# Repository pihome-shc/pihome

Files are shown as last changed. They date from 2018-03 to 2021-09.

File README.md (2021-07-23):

<p align="center">
    <a href="https://www.pihome.eu" target="_blank" align="center">
        
    </a>
<br/>
</p>

# PiHome - Smart Heating Control

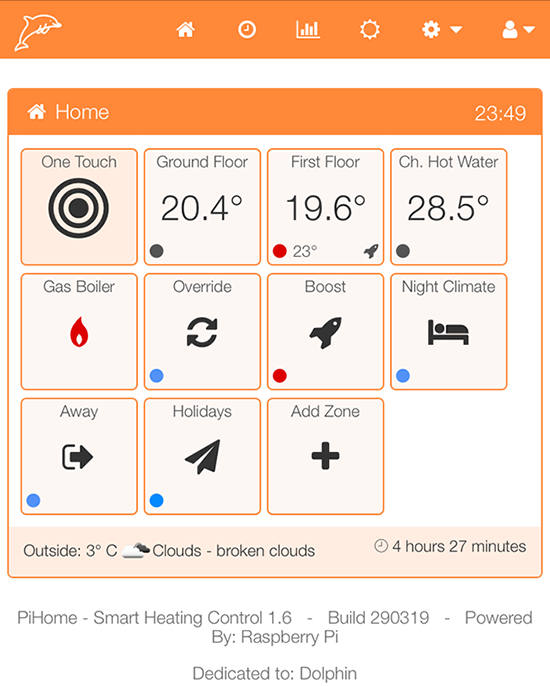
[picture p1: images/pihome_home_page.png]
PiHome - Smart Heating Control - Home Screen


PiHome – Smart Heating Control is home automation system or you can say central heating control systems that runs on credit card size single board computer Raspberry Pi. You can control your home heating from your smartphone, laptop or tablet, PiHome is a wireless boiler control which mean you don’t need to run cables from pihome controller to your boiler or to your heating zone valve or to any temperature sensors in any heating zone.PiHome is active heating control of your multi zoned heating, hot water including electrical immersion with unlimited schedules, boost and night climate suites your needs.

[Step by Step Instructions](http://www.pihome.eu/how-to-install/ "PiHome - Step by Step Instructions")

<p style="color:red;">Before we deep dive into this project something very important: PiHome comes with ABSOLUTELY NO WARRANTY, to the extent permitted by applicable law. DO NOT MAKE ANY CHANGES TO YOUR HEATING SYSTEM UNTIL UNLESS YOU KNOW WHAT YOU ARE DOING, contents provided here are for information and education purpose only, I take no responsibility for any loss or damage to you or your property.”</p3>

###If you want to download SD card image for Raspberry Pi please visit http://www.pihome.eu 

## Smart Heating Control – Features:
* Support Serial Gateway
* Support Ethernet and WiFi Gateway
* Unlimited schedule 
* Boiler and heating zone usage graphs
* Boost control for each Zone
* Override for each Zone
* Night climate
* Away

## Planned features
A real documentation (currently there's none, but the code is self explanatory and commented as well )

Follow Instructions on [PiHome](http://www.pihome.eu "PiHome - Smart Heating Control") if you have any question drop me comments and i will do my best to reply as soon as humanely possible. 

## Requirements
Basic knowledge of command line with following main components for pihome to function. 
* Apache Web Server
* PHP 7.x
* MySQL/MariaDB 

## How To Install 
sudo apt-get install git
sudo git clone https://github.com/pihome-shc/pihome "/var/www"
For more detailed instructiosn vist [PiHome](http://www.pihome.eu "PiHome - Smart Heating Control") website 

## Secial Thanks to

* [SB Admin 2 Template](http://startbootstrap.com/template-overviews/sb-admin-2 "SB Admin 2 Template ")
* [Pretty Checkbox](http://www.cssscript.com/pretty-checkbox-radio-inputs-bootstrap-awesome-bootstrap-checkbox-css "Pretty Checkbox ")
* [Font-Awesome](https://fortawesome.github.io/Font-Awesome "Font-Awesome")
* [Ionicons](http://ionicons.com "Ionicons ")
* [Box Shadow CSS](http://www.cssmatic.com/box-shadow "Box Shadow CSS")
* [AnimateCSS](https://daneden.github.io/animate.css "Animate.css ")
* [MySensors](https://www.mysensors.org "MySensors")
* [RaspberryPi Home Automation](http://pihome.harkemedia.de "RaspberryPi Home Automation")
* [All Others if forget them...](http://www.pihome.eu "All Others if forget them...")

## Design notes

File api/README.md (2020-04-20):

# APIs

## Boost State API
This API is used to set or check the BOOST on or off state for a given zone by name.
To check the current boost state call using http://pihome ip address/api/boostSet?zonename=abc where abc is the name of the zone.
To set the boost state call using http://pihome ip address/api/boostSet?zonename=abc&state=x where abc is the name of the zone and x is either true or false (alternatively 1 or 0 can be used).
The returned JSON format is:
```
    {
        "success": true,
        "state": zoneState
    }
```

## Get Zone Temperature API
This API is used to return the temperture for a given zone by name.
To return the temperature for a zone call using http://pihome ip address/api/getTemperature?zonename=abc where abc is the name of the zone.
The returned JSON format is:
```
    {
        "success": true,
        "state": zoneTemperature
    }
```

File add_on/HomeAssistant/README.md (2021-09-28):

# Home Assistant integration
For monitoring and controlling PiHome from Home Assistant via MQTT. PiHome will automatically broadcast over MQTT all the entity definitions needed to setup and then update the following HA entities:
* PiHome CPU Usage - sensor
* PiHome CPU Load (1m, 5m and 15m) - sensors
* PiHome CPU temperature - sensor
* PiHome Memory Use - sensor
* PiHome Swap Usage - sensor
* PiHome Disk Use - sensor
* PiHome Host Ip - sensor
* PiHome Last Boot - sensor
* PiHome Network throughput (up & down) - sensors
* PiHome Wifi Strength - sensor
* Boiler Status - binary sensor
* Climate entity for each zone defined in PiHome
  * Away Status (this is the same for all zones)
  * Zone Current Temperature (for each zone)
  * Zone Target Temperature (for each zone)
  * Zone Current Mode (for each zone)
  * Zone Current Status (for each zone)
  * Zone Boost (for each zone)
  * Zone Override (for each zone)
  * Zone sensor battery percentage (for each zone using a MySensor sensor)
  * Zone sensor battery voltage (for each zone using a MySensor sensor)

The climate entites allow to trigger the PiHome Boost function (Aux Heat in Home Assistant) for each zone, enable or disable the PiHome Away status and adjust the target temperature for each zone. When the target temperature of a zone is adjusted in Home Assisatant the Override mode is triggered in PiHome using the new target temperature. When installing this add-on a change will be made to the PiHome Override mode logic: **the Override mode will automatically be disabled when a new schedule for the zone starts**.

## Quick Start

1. Ensure your database is updated (i.e. the *mqtt* table includes the *topic* column)
2. Execute bash install.sh this will:
   * Install the Phyton moudles needed
   * Create and enable a service for autostart
   * Start service that was created

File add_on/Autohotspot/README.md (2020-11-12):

# Autohotspot

This code is the work of RaspberryConnect.com, thank you for this guide and code.

The installer has been modified to add support for the Armbian OS and to allow integartion with PiHome

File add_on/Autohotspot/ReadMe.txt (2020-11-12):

RaspberryConnect.com
This installer script, the autohotspot and autohotspotN scripts can be shared and modified but all references to RaspberryConnect.com must be kept in place.

AutoHotspot Setups:
This script is for installing a Raspberry Pi WiFi setup where the Pi will connect to a previously configured Wifi network when the Pi is in range of the router or Automatically setup a Raspberry Pi Hotspot/access point when a known wifi network is not in range.
This can also be run manually or with a timer to switch without a reboot.

This is available in two setups:
1: Internet access available for connected devices when a Ethernet cable is connected for the Raspberry Pi's 3A,3B,3B+ & 4. For Rapberry Pi's A,B, B+,& 2 if an usb Wifi adapter is used.
2: No internet access for connected devices. Designed for the Raspberry Pi Zero W or other Raspberry PI's where only a direct connection to the PI from a phone, tablet or Laptop is required.

There is also setup for permanent hotspot with internet access for connected devices.

For more information and for the manual setup's see:
https://www.raspberryconnect.com/projects/65-raspberrypi-hotspot-accesspoints/157-raspberry-pi-auto-wifi-hotspot-switch-internet
https://www.raspberryconnect.com/projects/65-raspberrypi-hotspot-accesspoints/158-raspberry-pi-auto-wifi-hotspot-switch-direct-connection
https://www.raspberryconnect.com/projects/65-raspberrypi-hotspot-accesspoints/168-raspberry-pi-hotspot-access-point-dhcpcd-method

This script will install any of these three setups or allow you to change between setup types.
In addition the Hotspot SSID and Password can be changed, new WiFi networks can be added to the Raspberry PI while in Hotspot Mode. The Pi can be forced between Network mode and Hotspot mode without a reboot. Also there is an uninstaller.

To use the installer:

Download the AutoHotspot-Setup.tar.xz archive from
curl "https://www.raspberryconnect.com/images/hsinstaller/AutoHotspot-Setup.tar.gz" -o AutoHotspot-Setup.tar.gz

Unarchive the file to the curent folder using the command
tar -xzvf AutoHotspot-Setup.tar.xz
If you are using the Desktop then right click on the AutoHotspot-Setup.tar.xz and select Extract Here

open a terminal screen and navigate to the Autohotspot folder. If this is in your home directory then use 
cd Autohotspot
if this is your desktop then use 
cd ./Desktop/Autohotspot
Run the script with the command
sudo ./autohotspot-setup.sh
This script will fail if sudo is not used.

You will presented with a menu with these options

 1 = Install Autohotspot with Internet for Connected Devices
 2 = Install Autohotspot with No Internet for connected devices
 3 = Install a Permanent Hotspot with Internet for connected devices
 4 = Uninstall Autohotspot or Permanent Hotspot
 5 = Add or Change a WiFi network (SSID)
 6 = Autohotspot: Force to a Hotspot or Force to Network if SSID in Range
 7 = Change the Hotspots SSID and Password
 8 = Exit

Option 1: Install Autohotspot with Internet for Connected Devices 
Once installed and after a reboot the Raspberry Pi will connect to a router that has previously been connected to and is listed in /etc/wpa_supplicant/wpa_supplicant.conf. If no router is in range then it will generate a WiFi hotspot.
This will have an SSID of RPiHotspot and password of 1234567890
Use option 7 to change the password and also the SSID if required
If an ethernet cable is connected to the Pi with access to the internet then it will allow devices connected to the hotspot access to the internet or local network.
Once a connection to the hotspot has been made you can access the Raspberry Pi via ssh & VNC with
ssh pi@192.168.50.5
vnc: 192.168.50.5::5900
for webservers use http://192.168.50.5/

Option 2: Install Autohotspot with No Internet for connected devices
This option is similar to option 1 but connected devices have no internet connection if an ethernet cable is connected. 
This has been designed so you can access only the Pi from a Laptop, tablet or phone.
The hotspot SSID will be RPiHotspot with a password of 1234567890
Once a connection to the hotspot has been made you can access the Raspberry Pi via ssh & VNC with
ssh pi@10.0.0.5
vnc: 10.0.0.5::5900
for webservers use http://10.0.0.5/

Otion 3: Install a Permanent Hotspot with Internet for connected devices
This is for a permanent WiFi hotspot with internet access for connected devices.
The Raspberry Pi will only have network or internet access when an ethernet cable is connected.
Once a connection to the hotspot has been made you can access the Raspberry Pi via ssh & VNC with
ssh pi@192.168.50.10
vnc: 192.168.50.10::5900
for webservers use http://192.168.50.10/

Additional setup is required if you wanted to use a second WiFi device to connect to the internet rather than a ethernet conection. This will be a future option.

Option 4: Uninstall Autohotspot or Permanent Hotspot
This will disable the setup of any of the three setups and return the Raspberry Pi to default Wifi settings.
Hostapd & dnsmasq will not be uninstalled just disabled.

Option 5: Add or Change a WiFi network (SSID)
If you are using either of the autohotspot setups in hotspot modes and wish to connect to a local WiFi network. You will be unable to scan for any networks as the desktop wifi option will be disabled, shown as red crosses. You can manually add the details to /etc/wpa_supplicant/wpa_supplicant.conf if you know them. 
This option will allow you to scan for local WiFi networks and update the Pi. If you then reboot or use the Force... option ,see below. 
This option only works for WiFi networks where only a password is required. If a username is required this will not work. (Future update)

Option 6: Autohotspot: Force to a Hotspot or Force to Network if SSID in Range
This option is only for the Autohotspot setups.
If you are at home and connected to your home network but would like to use the hotspot. This option will force the pi to hotspot mode and will ignore your home network untill the next reboot. If you use this option again while in hotspot mode it will attempt to connect to a known network. This will go back to the hotspot if no valid WiFi network is found or there is a connection issue.
 
Option 7: Change the Hotspots SSID and Password
By default the hotspot ssid is RPiHotSpot with a password of 1234567890. Use this option to change either or both SSID and Password.
You will be prompted to change both but if you make no entry and press enter the existing setting will be kept.
The password must be at least 8 characters. 

Option 8: Exit
Exit the script.

NFtables Warning.
This setup uses iptables for routing the Hotspots to the internet, options 1 & 3. From Raspbian 10 Buster, IPtables are depreciated in place of NFtables. By default NFtables will handle IPtable rules. 
If you know you are using NFtables for a Firewall or other routing rules then don't use the internet routed hotspots and only use option 2, Autohotspot without internet. Otherwise there will be a conflict with your routing tables. 
NFtables will be implemented shortly in the next main update of the installer and scripts.    
Raspbian Stretch (9) & Jessie (8) only use IPtables.
You will be warned when you initially run the installer script if NFtables are active.

/etc/network/interfaces file:
many older hotspot and network setup guides online add entries to the /etc/network/interfaces file. This file is depreciated in Raspbian and any entry in this file is not compatible with these setups. This installer backup and remove any entries found in this file. They will be restored if the uninstall option is used.

RaspberryConnect.com

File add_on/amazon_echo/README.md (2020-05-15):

# echo
For controlling local devices with the Amazon Echo.

Instructions for installation and usage see https://github.com/n8henrie/fauxmo

Credit to Nathan Henrie (https://n8henrie.com)

## Quick Start

1. Execute the installer using - 'sh install_echo.sh'
2. Tell Echo, "discover my devices"
3. Use Echo's "zone name on" and "zone name off" to set the BOOST on or off as required
4. Use the Alexa app to edit zone names as required

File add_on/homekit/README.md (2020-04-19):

# Homekit
For controlling local devices with the iOS Home App. This interface uses Homebridge and the Homebridge Http Webhooks plugin to provide control of BOOST for individual zones and to interogate temperature sensors. 

## Quick Start

1. Install Homebridge, see https://github.com/homebridge/homebridge/wiki/Install-Homebridge-on-Raspbian
2. Execute bash install.sh this will:
    Install the Homebridge Http Webhooks plugin.
    Modify /etc/apache2/sites-available/000-default.conf and enable mod_rewrite so that urls without the .php extension can be used (a backup will be created),
    Check that the Webhooks cache storage directory has been created and is empty.
    Create a backup of /var/lib/homebridge/config.json.
    Add to config.json the Webhooks platform
    Add to config.json Webhooks switches for each zone where status = 1, the [id] value will be switchxx where xx is the zone_id.
    Add to config.json Webhooks sensors for each zone where status = 1 or graph_it = 1, the [id] value will be sensorxx where xx is the zone_id.

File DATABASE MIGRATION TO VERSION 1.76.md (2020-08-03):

# Process to Migrate the Database to Version 1.76

## Changes
The 'zone' table has been split in to two tables, 'zone' and 'zone_sensors'.
The 'zone' table contains zone and contoller identification information.
The 'zone_sensors' table' contains any sensor related information linked to a particular zone. Category 2 type zones will have no entries in the 'zone_sensors' table.
The database views have been ammended to reflect the new table structures.

## Migration Process
Execute the 'migrate_db.php' file found in the directory 'MySQL_Database', this will update the database structure and migrate the existing 'zone' table data, it will also update the views as required.
Update the other files in the normal manner.

## NOTE - DO NOT UPDATE THE DATABASE BY EXECUTING 'update_db.php'.

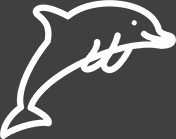
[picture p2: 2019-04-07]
images/dolphin.png

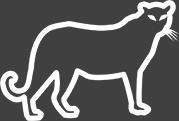
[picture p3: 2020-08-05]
images/amur_leopard.png

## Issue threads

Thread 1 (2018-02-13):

Customisation for different setup

harvybob, 2018-02-13:
Hi,

I'm very intrested in setting up a similar controller to what you have, but php coding is non existent for me, the work i have done is by learning python.

Can you assist/guide me a little on how to make this work for me?
The setup i have at the moment is
1)multiple DS18B20's around the house connected to multiple pi's. Each pi sends back readings to a central mysql database.
2) use bv4627 relay board to switch on and off various zones - i have an ufh manifold of 8 zones, plus first floor and DHW - so at present 10 zones (This will be come 15 in the future)

Everything is wired at present so no need to the wireless side, but want some pointers on where to make adjustments for the different relay controller, and also the data being held on a central mysql (not running on a pi!) I cant see any contact points via the website so forgive me for raising as an issue - feel free to close without comment if you are unable to help me!

pihome-shc, 2018-02-13:
Hi,
first question, what is the heat sources? is it gas boiler, solid fuel or solar? you are using pi with DS18B20 around the house to report back only temperature? does each pi with DS18B20 have relay connected or your relay module is connected to another pi who control zone?

harvybob, 2018-02-13:
Hi, the heat source is gas boiler,
I have two pi's and lots of network cables with sensors on the end.
Pi 1 has approx 8 sensors, and also runs my current code + interface
Pi 2 has approx 3 sensors and runs the control of the relay board over i2c
The relay pi has code which invokes a pulse of a relay (short on and off) based on the zone that is needed ( the relay board handles 12v, to then activate as 230v latching relay - The pi only needs to pulse to turn on, and pulse again to turn off of the 12v system, and is isolated from interference from the pi, as it is controlled using i2c rather then directly over gpio.

pihome-shc, 2018-02-13:
Hi,
main brain in pihome heating is boiler.php i have added support for GPIO Pin connected zone relay and boiler relay. line important to you are
205, 206 for Zone Relay
247, 248 for Boiler Relay ON status
285, 286 for Boiler Relay Off status
you can execute any command you like in these lines to control your zone or boiler relay, tried to google how to send on/off command to bv4627 relay but i didn't find any simple answer.

harvybob, 2018-02-13:
the bv4627 is a bit special in that way - the commands i have are in python -
for on is:
bv4627.write(bytearray([relay_no,1,0,1]))
for off is:
bv4627.write(bytearray([relay_no,0,0,1]))

but you need the i2c library for it to work. Ill have a look at boiler.php and see what i can do,

Any tips on the sensors? do you base boiler.php on the values as they are in a database table?

pihome-shc, 2018-02-13:
Then you can place these commands in boiler.php after you install required library.  and best to do test run.  on temperature sensors side:
Each temperature sensors is represented with node_id in nodes table, when you create zone you just select correct node_id (temperature sensor), this way you have zone and temperature sensors for each zone. i hope this make some sense. best to have look at table structure and table view structure.
Thank you

pihome-shc, 2018-02-22:
@harvybob
did you manage to test the code? need any further help?
W

harvybob, 2018-02-24:
I'm having issues installing and setting up, i've put a question on the LAMP setup page
[http://www.pihome.eu/2017/10/11/apache-php-mysql-raspberry-pi-lamp/#comment-238](url)

seems setup.php is throwing back an error on the mysql_connect() .
error is:
`PHP Fatal error:  Uncaught Error: Call to undefined function mysql_connect() in /var/www/setup.php:38
Stack trace:
#0 {main}
  thrown in /var/www/setup.php on line 38
`

Full detail son the post above

pihome-shc, 2018-02-24:
@harvybob
php7 isnt supported for PiHome, you need to following <a href="http://www.pihome.eu/2017/11/02/install-apache-php-7-0-mysqlmariadb-raspberry-pi-lamp/">Install Apache, PHP and MySQL on a Raspberry Pi (LAMP)</a> let me know if you need more help
Admin

pihome-shc, 2018-02-26:
@harvybob
i have added lines lines in setup.php to check php version before running it.
Admin

pihome-shc, 2018-04-01:
you can change that to anything as system isnt depended on utf16. let me know if you need more help otherwise i m closing this ticket.
pihome - admin

harvybob, 2018-04-02:
Is there a specific place that it needs to be changed or is it throughout the installation script?

pihome-shc, 2018-04-02:
can you share your python script you are using to control your relay?

harvybob, 2018-04-02:
If your able to see my repo's there's home heating. I2c_raw.py does the actual switching, and the switch_relay.py does it from application - so figures out which relay needs to change etc. Line 111 does the actual switch. I'll try an link it when I get to a computer, octodroid doesn't let me copy/paste a link

harvybob, 2018-04-09:
[https://github.com/harvybob/home_heating/blob/master/i2c_raw.py](url) is the class which activates the relays- there are 8 per board.

to invoke the above, i use:

`def switch_relay(sensor):
    """Will look up relay number for a sensor and switch it"""
    relay_results=select_sql("SELECT relay,board FROM sensor_master WHERE sensors = '{0}'".format(sensor))
    for relay in relay_results:
        relay_no=int(relay[0])
        relay_board=int(relay[1])
        bv4627 = i2c_raw.i2c(relay_board, 1)
        logging.info("switching on relay "+str(relay_no)+" on board "+str(relay_board))
        bv4627.write(bytearray([relay_no,1,0,1]))
        time.sleep(.4)
        logging.info("switching off relay "+str(relay_no)+" on board "+str(relay_board))
        bv4627.write(bytearray([relay_no,0,0,1]))`

pihome-shc, 2018-10-05:
Closing this issue, no further comments required,

Closed 2018-10-05.

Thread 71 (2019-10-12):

Buffer Tank -  Second Heat Source

dvdcut, 2019-10-12:
# Buffer Tank -  Second Heat Source
Some background and explanation about buffer tank and combined storage tank.

## Buffer Tank:
A buffer tank is a backup/reserve tank for storing heating in form of hot water which can be called upon when needed. Buffer Tanks are designed for use with standard central heating systems (biomass or solid fuel systems in conjunction with solar water heating system. The water is heated by the heat source (solar, biomass or wood boiler) to a set temperature in the tank and this hot water can be stored until it is required. It therefore will reduce the ‘short cycling’ of a boiler, in that it will reduce the amount of times that a boiler will turn on and off to heat the water and in doing this it will help to increase the lifetime of the boiler.

## Combined storage tanks
A combined storage tank combines hot water storage for heating support. As a result, warm water, typically from solar thermal energy is stored temporarily for both purposes for later consumption.  (its rare installation but still if some one else can shed some light and give schematic for connection and how to control it)

## Option for second heat source:
As i understand right now PiHome do not support second heat source and now way of controlling it or deciding where the heat comes from (heat sources is defined as boiler) and heat comes from same single source.

## Suggestion:
### Option One
Build some differential controller with two sensors and two relay and let that differential controller  to decide where the heat comes from, PiHome only send instructions when there is demand for heat. This would be ideal if buffer tank and boiler are in same location.

### Option Two
In some cases buffer tank and boiler aren't in same location hence one differential controller isn't going to work. configure/modify PiHome to have buffer tank as second heat source or should I say proffered heat source and if that heat source is above set point then heat should be called from buffer tank and if buffer tank is below set point then call for heat from second heat source i.e gas boiler. i know second option requires two controller: one for boiler and second for buffer tank.

This would be huge advantage for PiHome over commercially available solution in the market. all commercially available solutions do not have any way of managing or calling second heat source in managed and decent way as far as i tell (may be i m wrong but i m open to correction).
I would prefer to see PiHome managing/controlling second heat source from itself and second option would definitely gives more controller rather then having only option one implemented, also implementing option one would left out all those who's boiler and buffer tank in separate locations.

sorry for long story but i felt the needs explaining, i m not an expert by any mean and open to correction.

pihome-shc, 2019-10-13:
@dvdcut thank you for explaining and typing :)

pihome-shc, 2019-10-14:
@dvdcut i don't have buffer tank and don't know how heating is circulated from buffer tank. in my place i have to trigger boiler and then zone valve for heating and not to worry about circulation pump but if i had buffer tank then i would have some circulation pump to circulate the heat from buffer tank? so we just need to trigger that pump some what same as we do for gas boiler i would imagine until buffer tank temperature is above set point.

dvdcut, 2019-10-21:
i have been working on this, its not anywhere near finish but its starting point. i have touched boiler.php for second heat source,

### MySQL database table
```
CREATE TABLE `buffer_tank` (
	`id` INT(11) NOT NULL AUTO_INCREMENT,
	`status` TINYINT(4) NULL DEFAULT NULL,
	`name` CHAR(50) NULL DEFAULT NULL,
	`controller_id` INT(11) NULL DEFAULT NULL,
	`controller_child_id` INT(11) NULL DEFAULT NULL,
	`sensor_id` INT(11) NULL DEFAULT NULL,
	`sensor_child_id` INT(11) NULL DEFAULT NULL,
	`min_c` INT(11) NULL DEFAULT NULL,
	PRIMARY KEY (`id`),
	INDEX `FK_buffer_tank_nodes` (`sensor_id`),
	INDEX `FK_buffer_tank_nodes_2` (`controller_id`),
	CONSTRAINT `FK_buffer_tank_nodes` FOREIGN KEY (`sensor_id`) REFERENCES `nodes` (`id`) ON UPDATE SET NULL ON DELETE SET NULL,
	CONSTRAINT `FK_buffer_tank_nodes_2` FOREIGN KEY (`controller_id`) REFERENCES `nodes` (`id`) ON UPDATE SET NULL ON DELETE SET NULL
)
COLLATE='utf8mb4_general_ci'
ENGINE=InnoDB
AUTO_INCREMENT=2;
```
### settinglist.php file, i have this after boiler.
```
<button class="btn btn-default btn-circle btn-xxl mainbtn animated fadeIn" data-href="edit_boiler.php" data-toggle="modal" data-target="#buffer_tank">
<h3 class="buttontop"><small><?php echo $lang['buffer_tank']; ?></small></h3>
<h3 class="degre" ><i class="fa fa-tint fa-1x green"></i></h3>
<h3 class="status"></small></h3>
</button>
```
### model.php file

```
//Buffer Tank settings
echo '
<div class="modal fade" id="buffer_tank" tabindex="-1" role="dialog" aria-labelledby="myModalLabel" aria-hidden="true">
    <div class="modal-dialog">
        <div class="modal-content">
            <div class="modal-header">
			<button type="button" class="close" data-dismiss="modal" aria-hidden="true">x</button>
                <h5 class="modal-title">'.$lang['buffer_tank_settings'].'</h5>
            </div>
            <div class="modal-body">';
$query = "SELECT * FROM buffer_tank;";
$results = $conn->query($query);
$brow = mysqli_fetch_array($results);
echo '<p class="text-muted">'.$lang['buffer_tank_info_text'].'</p>';

echo '
	<form data-toggle="validator" role="form" method="post" action="settings.php" id="form-join">

	<div class="form-group" class="control-label">
	<div class="checkbox checkbox-default checkbox-circle">';
	if ($brow['status'] == '1'){
		echo '<input id="checkbox2" class="styled" type="checkbox" value="1" name="status" checked>';
	}else {
		echo '<input id="checkbox2" class="styled" type="checkbox" value="1" name="status">';
	}
	echo '<label for="checkbox2"> '.$lang['buffer_tank_enable'].'</label></div></div>

	<div class="form-group" class="control-label"><label>'.$lang['buffer_tank_name'].'</label>
	<input class="form-control input-sm" type="text" id="name" name="name" value="'.$brow['name'].'" placeholder="Buffer tank name ">
	</div>

	<div class="form-group" class="control-label"><label>'.$lang['buffer_tank_controller_id'].'</label> <small class="text-muted">'.$lang['buffer_tank_controller_id_info'].'</small>
	<select class="form-control input-sm" type="text" id="buffer_tank_controller_id" name="buffer_tank_controller_id">';

	//get current buffer_tank_controller_id from nodes table
	$query = "SELECT * FROM nodes WHERE id ='".$brow['controller_id']."' Limit 1;";
	$result = $conn->query($query);
	$row = mysqli_fetch_assoc($result);
	$controller_id=$row['node_id'];
	$notice_interval=$row['notice_interval'];

	echo '<option value="'.$controller_id.'" selected>'.($controller_id=='0' ? 'N/A' : $controller_id).'</option>';

	//get list from nodes table to display
	$query = "SELECT * FROM nodes where name = 'Buffer Controller Relay' OR name = 'Buffer Controller' AND node_id!=0;";
	$result = $conn->query($query);
	if ($result){
		while ($nrow=mysqli_fetch_array($result)) {
			echo '<option value="'.$nrow['node_id'].'">'.$nrow['node_id'].'</option>';
		}
	}
	echo '<option value="0">N/A</option>
	</select>
    </div>';

	echo '
	<div class="form-group" class="control-label"><label>'.$lang['buffer_tank_controller_child_id'].'</label> <small class="text-muted">'.$lang['buffer_tank_controller_child_id_info'].'</small>
	<select class="form-control input-sm" type="text" id="buffer_tank_controller_child_id" name="buffer_tank_controller_child_id">
	<option selected>'.$brow['controller_child_id'].'</option>
	<option value="0">0</option>
	<option value="1">1</option>
	<option value="2">2</option>
	<option value="3">3</option>
	<option value="4">4</option>
	<option value="5">5</option>
	<option value="6">6</option>
	<option value="7">7</option>
	<option value="8">8</option>
	</select>
    </div>

	<div class="form-group" class="control-label"><label>'.$lang['sensor_id'].'</label> <small class="text-muted">'.$lang['sensor_id_info'].'</small>
	<select class="form-control input-sm" type="text" id="sensor_id" name="sensor_id">
	<option selected>'.$brow['sensor_id'].'</option>
	<option value="0">0</option>
	<option value="1">1</option>
	<option value="2">2</option>
	<option value="3">3</option>
	<option value="4">4</option>
	<option value="5">5</option>
	<option value="6">6</option>
	<option value="7">7</option>
	<option value="8">8</option>
	</select>
    </div>

	<div class="form-group" class="control-label"><label>'.$lang['min_temperature'].'</label> <small class="text-muted">'.$lang['min_temperature_info'].'</small>
	<select class="form-control input-sm" type="text" id="max_operation_time" name="max_operation_time">
	<option selected>'.$brow['min_c'].'</option>
	<option value="30">30</option>
	<option value="40">40</option>
	<option value="45">45</option>
	<option value="50">50</option>
	<option value="55">55</option>
	<option value="60">60</option>
	<option value="65">65</option>
	<option value="70">70</option>
	<option value="80">80</option>
	<option value="85">85</option>
	<option value="90">90</option>
	<option value="95">95</option>
	<option value="100">100</option>
	<option value="110">110</option>
	<option value="120">120</option>
	</select>
    </div>
	';

	echo '</div>
            <div class="modal-footer">
				<button type="button" class="btn btn-primary btn-sm" data-dismiss="modal">'.$lang['close'].'</button>
				<input type="button" name="submit" value="Save" class="btn btn-default login btn-sm" onclick="buffer_tank_settings()">

            </div>
        </div>
    </div>
</div>';
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
pihome-shc, 2019-10-21:
@dvdcut,
i will give it try tomorrow, your code missing **request.js** and **db.php** code.

pihome-shc, 2019-10-26:
@dvdcut i had implemented your changes, all looks good on gui apart from buffer tank info text, i think its to long. its like explaining what buffer tank is, i think one short line would be enough.

> A buffer tank is a backup/reserve tank for storing heating in form of hot water which can be called upon when needed. Buffer Tanks are designed for use with standard central heating systems (biomass or solid fuel systems in conjunction with solar water heating system) If you have Butter Tank installed and you want to used it as primary heat source you can add this information here.

dvdcut, 2019-12-09:
Buffer tank implementation proving to be more difficult then i thought, i dont know if its all worth in the end or one  differential controller would be better option. anyway i have done some work in last few days on buffer tank i think all gui part is completed but boiler.php is proving to be bit difficult.

[Buffer Tank.zip](https://github.com/pihome-shc/pihome/files/3937471/Buffer.Tank.zip)

pihome-shc, 2019-12-14:
@dvdcut
all GUI looks good, and i can see buffer tank on main screen and all settings working for buffer tank but i think [boiler.php](https://github.com/pihome-shc/pihome/blob/master/cron/boiler.php) need some working and logic isn't there yet in the code, its partially working.

dvdcut, 2019-12-18:
yes, login in boiler.php isnt implemented and its proving to be difficult, i'll work on this issue in new year.

dvdcut, 2020-05-02:
i think i have to drop this, i have found that every buffer tank comes with its controller so i think we don't need this. we can always add butter as zone disable zone to monitor its temperature

pihome-shc, 2020-05-02:
@dvdcut i think you are right and not many user have buffer tank big enough to run heating from it but only supplement hot-water for the house.
closing this

Closed 2020-05-02.

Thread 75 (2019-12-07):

Hot Water Priority Feature Request

harvybob, 2019-12-07:
Hi, Some boilers have an option for hot water priority - where the boiler will increase the heat output to heat up a hot water tank quickly - at a higher temprature then the radiators would normally take.

for this, the boiler has an additional set of controls.

Is there a way for PiHome to be programmed such that if Hot Water demand is on, Close off all zone valves for non hot water if the following two criteria is met: there is a demand for hot water from the tank +the scheduled window for hot water is active?

pihome-shc, 2019-12-07:
@harvybob
is there any interface on boiler that can be checked? or how we know if boiler does this feature? and how to check if there is hotwater demand? this can be implemented.

harvybob, 2019-12-18:
Apologies missed this, how is hot water demand managed at the moment? Alternatively all tanks will have a thermostat so would need to detect using a pin on the pi. The thermostat is usually 0v so shouldn't be a problem?

Most boilers have the feature however usually undocumented, if the boiler has a feature it would be in the installation manual, internally wiring would have contacts for the room stat, and a second pair for dhw.

dvdcut, 2020-03-11:
recently i had new boiler installed and it has this feature but when i asked the installer about this feature he dismissed me by saying i don't have pipe work for this and i can not use it :( but currently hot water goes to my manifold and then based on which zone calling for heat that hot water circulated in that zone (either heating or hot water) i think this is how most of the houses have it setup. may be yours is different and you do have pipe work for hot water

harvybob, 2020-03-13:
Hi dvdcut, There are generally two ways to use HotWater Priority - first and the easiest is using a three port valve - which requires plumbing to be setup as such.

The other way (and the way that alot of plumbers dont know/want to know) is by using the correct actuators on the port valves (assuming you use these!) and/or using relays.

My setup is the second - i have three port valves, one for hot water, one for UFH and the third for rads. The same will apply if you have two port valves. The Hot water actuator has been changed to a 6 wire version - this allows the actuator to send both open and closed signals which is what is needed for my boiler to know if hot water is needed or radiator. If you want to use the existing 5 wire actuactor, you need in include a relay to flip the signal from open to closed and vice versa... Plumbers usually dont want to get involved in the electric side so dont want to do it.

Your setup may be different from this again, but will still be doable in some way! do you use an UFH manifold or are you using port valves?

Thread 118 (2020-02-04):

Serial Read Bottleneck

MindaugasMeskauskas, 2020-02-04:
### Summary:
Yesterday for first time I encountered strange issue, all 3 of my nodes were reporting wrong temperature. Boiler was ON for longer as it should have been. At first I couldn’t tell what was the problem, as all 3 nodes frequently were updating DB with “current” temperature. Next morning I checked graphs (see below) and you can see that right temperature curve appeared about 6 hours late. As it affected all notes the bottleneck must have been on receiving end.

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
Spikes shown on graph around 1am, was me testing nodes at around 10pm.

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
Raspberry Pi temp curve looks as it should (different script, not affected by serial read)

### Observations:
Haven’t done any testing, but this is what I have observed. All of this is my closest guess. Ref similar issue on [stackoverflow](https://stackoverflow.com/questions/19908167/reading-serial-data-in-realtime-in-python)

serialgw.py script has time.sleep(1) in its loop, so it means if serial port receives more than 1 message a second, messages will start to pile up in queue and will be read out one by one every second.
To delay serial read by this much (6h) about 21600 additional messages needed to be written/read in short period of time (not sure how many messages are generated in normal circumstances).

### Possible Solution:
Part 1: In general we are not expecting more than 1 message per second in average, but to prevent such unexpected behaviour and provide future proof, serialgw.py loop should be implemented without sleep as well as without causing extensive additional resources on CPU.

Part 2: Number of additional messages looks to be way too high. Need to be investigate what could have generated all of them in such sort time.

pihome-shc, 2020-02-04:
@MindaugasMeskauskas,
i know this issue, when last time i installed a 32 zone UFH system in Ireland
34 temperature sensors,
10 Zone Controller
1 Boiler Controller
if i do maths correctly:
Temperature sensors sends 3 messages: temperature, battery volt, battery %
Zone Controller: 4 messages per controller with ack to keep controller alive in system.

Node | # | rx | tx | total
-- | -- | -- | -- | --
Sensor | 32 | 0 | 3 | 96
Zone | 10 | 4 | 4 | 160
Boiler | 1 | 1 | 1 | 1
Total |   |   |   | 257

Total 257 messages to process per minute for script it was over the limit and script was causing some serious issues as script couldn't go thought all the messages in 60 seconds while boiler.php updated message_out table ready for next round.

### Workaround:
i decreased message_out per zone controller from 4 to 1 (manually set ack to 0 and leave one ack 1).
and inside wifigw.py  `time.sleep(0.1)`

back to what could have generated that many messages:
when heating is on temperature sensors send reading every 60ish seconds because temperature is changing. You have three zone so i m assuming, one zone controller, one boiler controller and three temperature sensors. your system have to deal with 27 messages every 60 seconds and if script go for sleep for 1 seconds we lose 30 seconds in sleep time per 60 seconds so its very close to cause queue.

Node | # | rx | tx | total
-- | -- | -- | -- | --
Sensor | 3 | 0 | 3 | 9
Zone | 1 | 4 | 4 | 16
Boiler | 1 | 1 | 1 | 2
Total |   |   |   | 27

i m not sure how cpu will react with no sleep time.
here is short video when boiler.php run and update message_out table, you can see cpu usage goes nearly 100% on both core.
https://www.dropbox.com/s/xwmobktyrtehbbc/2020-02-04%2023.02.54.mov?dl=0

MindaugasMeskauskas, 2020-02-05:
@pihome-shc
Did some digging yesterday and found that in average 30-40 messages were processed per minute. Max observed was 47. That is a bit high, but not to overload system, as it happened. Checked all processed messages and it looks like I haven't disabled debugging on GW and it prints all debugging info to serial. Will test that next. Still puzzled what could have caused such delay. Could have gateway debug printed so many messages in some scenario?

FYI, my setup:
2 temperature node - only for testing in different rooms or as redundancy
1 water tank node - 2 sensors but returns average
0 Zone - No zone controller (but guessing messages are still sent out as zones are setup in interface)
1 Boiler - but would be nice to have second source :) e.g. water tank is gas and electric.

pihome-shc, 2020-02-05:
@MindaugasMeskauskas
yes debug messages are processed as well even thought they dont get into database but python script still have to process them and ignore them. did you change sleep time to lower value? or remove it all together.

MindaugasMeskauskas, 2020-02-06:
@pihome-shc
Had no time to check it further. Haven't touched anything. Still running original code and with GW debug enabled. Seems to be running OK at the moment.

MindaugasMeskauskas, 2020-02-09:
Finally looked at this again. Observed that GW sometimes get into situation where it produces 200+ debug messages without any payload. Example below:

`0;255;3;0;9;1388779 TSF:MSG:READ,67-67-67,s=67,c=3,t=67,pt=2,l=8,sg=0:67
0;255;3;0;9;1388800 !TSF:MSG:LEN=8,EXP=15`

Have no node 67 so not sure if this some interference or what, but know that I don't need that information of incomplete incoming messages flooding serial buffer. If simply disabling debugging, GW stops writing to serial, but strangely still reads serial port :/ All Serial GW examples I found have debugging enabled which is OK for setting up, but not for production and no explanation how do it without enabling debugging. Played with parameters from MySensors library MyConfig.h and found that if disabling debug by removing line `#define MY_DEBUG` and adding `#define MY_SERIALDEVICE Serial` only messages are written to serial. Current message rate per minute for my setup is 5-17 and that is way better than before with 30-40 or even above 200 in rare circumstances.

Haven't done any code changes is serialgw.py, which is not required with current message rate.

pihome-shc, 2020-02-09:
@MindaugasMeskauskas may be someone in your nearby have mysensors nodes :)

pihome-shc, 2020-02-15:
@MindaugasMeskauskas are you using irq pin on your nRF (i m assuming you are using nRF radio) i know with irp pin it improves buffering and message processing.

pihome-shc, 2020-02-20:
is this issue need any further work?

Closed 2020-02-20.

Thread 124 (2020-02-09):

Zone - Add/Edit

pihome-shc, 2020-02-09:
When adding zone, it set to zone temperature sensors id to 0 and zone controller only show boiler controller from drop down list.

#69 - Missing save button on Zone edit

MindaugasMeskauskas, 2020-02-09:
I probably could check this tomorrow if no one else already doing so.

pihome-shc, 2020-02-09:
Zone Add/Edit is fixed from my last update but if you have free time may be test these changes. second part of this bug is when you edit the zone it add another entry in message_out table.

pihome-shc, 2020-02-20:
closing this issue

Closed 2020-02-20.

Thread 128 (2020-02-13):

Inversed logic

sandreialexandru, 2020-02-13:
Most boilers require a closed circuit to turn on heating. This means that a boiler connected to a Normal Open relay would be OFF in normal state. When triggering the relay the circuit gets closed and the boiler turns ON.
Having security in mind and assuming that the SD card or the Raspberry Pi could get faulty then the relay would close the NC contacts and the boiler would turn ON indefinitely. I suggest an inverse logic in _/cron/boiler.php_
**_$relay_on = '1'; //GPIO value to write to turn on attached relay
$relay_off = '0'; // GPIO value to write to turn off attached relay_**

dvdcut, 2020-02-13:
i think this is down to relay board you are using, You need to have relay with optocoupler as descried in [pihome website ](http://www.pihome.eu/2017/10/12/wireless-arduino-boiler-controller-relay-with-nrf24l01/)
this way if pi dies or sd card or any other thing then this relay gets turned off.

sandreialexandru, 2020-02-13:
Turning the relay off while the boiler is connected to NC contacts just puts the boiler to ON

MindaugasMeskauskas, 2020-02-13:
@sandreialexandru
Common standard relays have 3 contacts.
COM = common contact
NC = normally closed contact
NO = normally open contact

In our case if you disconnect signal wires from relay it should switch off (COM + NC = off when no signal)
Switch wires between NC and NO or change relay you have.

sandreialexandru, 2020-02-13:
@MindaugasMeskauskas
I'm very aware of how relays (electromagnetic or with transistor optocoupler) work. But inversing the logic would make PiHOME possible to be used with any kind of relays.

dvdcut, 2020-02-13:
two variables at the top of boiler.php to modify values as your needs. sorry not trying to be hard but if your boiler work different then you have to swap variable values so PiHome is always in control.

```
$relay_on = '1'; //GPIO value to write to turn on attached relay
$relay_off = '0'; // GPIO value to write to turn off attached relay
```

MindaugasMeskauskas, 2020-02-13:
I got now what was asked, but think reversing logic is done when compiling Arduino Sketch - PiHome_Boiler_Controller_v031.ino
`#define RELAY_ON 1  // GPIO value to write to turn on attached relay`
`#define RELAY_OFF 0 // GPIO value to write to turn off attached relay`

dvdcut, 2020-02-13:
i think @sandreialexandru was asking for raspberry pi gpio pin,

sandreialexandru, 2020-02-13:
After searching for a while to be sure that almost everywhere, all boilers and thermostats work on the same principle I've found some discussions stating that boilers get connected to COM+NO pins of relay. If we do this with PiHOME everything works backwards.
[https://www.tyrrellsmarthome.com/wp-content/uploads/2018/02/Thermostat-Energy-Combo-Bundle.pdf](url)
[https://diy.stackexchange.com/questions/115954/isolation-relay-for-ecobee-smart-thermostat-nc-or-no](url)

pihome-shc, 2020-02-13:
I think its worth testing this on raspberry pi just to be sure, i can do this later and update here the results.

sandreialexandru, 2020-02-15:
I have tested this by redefining the two variables in boiler.php
$relay_on = '1'; //GPIO value to write to turn on attached relay
$relay_off = '0'; // GPIO value to write to turn off attached relay

pihome-shc, 2020-02-15:
@sandreialexandru so if pihome set relay to 1 ($relay_on = '1';) it mean really would be on and if pi fails relay will turn off as there is no signal?
you dont need to unplug power to pi cable but you can unplug signal cable from pi to relay board.

aszumski, 2020-02-16:
@sandreialexandru I think most of optoisolated 5v relay boards that people use activate relay when you pull it down input to 0V. Just adjust relay on/off variables as you wish. For example I have zone valves wired to pi via relay board but I use uln2803 between relay board and pi (don't like idea of driving 5v input with 3.3v) that changes the on/off logic, so I just adjusted the script for my needs.

harvybob, 2020-02-16:
Would the values for this be better in a config file?(like you guys have done for the database connection details) that way it's kept for the individual, and not over written on upgrade? For me using i2c I need 1 for on, but for others it will be 0 for on depending on the relay used...

pihome-shc, 2020-02-20:
may be best to give option to user during creation of nodes i.e define on state of relay with dropdown 1 or 0 save it to database as it would be easy maintain and update.

pihome-shc, 2020-05-01:
closing this issue.

Closed 2020-05-01.

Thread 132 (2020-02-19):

Reorganising Settings Menu

MindaugasMeskauskas, 2020-02-19:
As @pihome-shc have mentioned in another post list of icons in settings menu keeps growing.
Open this issue to discussion how we could tackle this.

Example suggestions:
- Systems °, OS Version, PIHome Update, Uptime, Wifi, Ethernet, etc. could be added to one "system" menu under one icon as all just displays info. Maybe reboot and shutdown buttons added to it as well as they are relevant to the system.

- Once of confit of temperature units, language, time zone, etc., should be grouped under "First Startup".

- Or icons could be grouped like "One Touch" button on home screen

> i was looking at the ever growing list of icons under settings. i was thinking to put these settings under language or system or perhaps another icon for time-zone?

_Originally posted by @pihome-shc in https://github.com/pihome-shc/pihome/issues/121#issuecomment-583626295_

pihome-shc, 2020-02-19:
@MindaugasMeskauskas
Setting icons can be organised same as Temperature Graphs,  Daily usage, Boiler Usage (data-toggle), i m open to suggestions, i thin merging these icons requires decent amount of work and it will be easy for future addition for example i m thinking to make raspberry pi as access point if no wifi/ethernet available and give user option to configure Wi-Fi from settings.

### PiHome
PiHome Update
MQTT
PiConnect
Boost
Backup

### Systems
OS Version
Uptime
Wi-fi
Ethernet
User Account
Cron Jobs
Services

### Setup
Override
Frost
Units
Language
Graph
Boiler
Node
Sensors
Zone
Gateway
OpenWeather

pihome-shc, 2020-02-25:
may be its time to implement permission. i.e normal user dont need to see or change anything and some maintenance user account with higher power.

twa127, 2020-03-04:
I like that idea, user able to do scheduling, boost, override, holidays etc but not add zones, change units, language etc or even user not able to access the settings menu at all

dvdcut, 2020-03-04:
i m in favor of hiding some icons and only allow users with some sort of higher permission. bit like any other home alarm, where engineer have different code to access all options and home users some other options.

twa127, 2020-03-09:
Anyone want to try this and see what you think

[settingslist.zip](https://github.com/pihome-shc/pihome/files/4306624/settingslist.zip)

dvdcut, 2020-03-09:
that looks good, here is my version but can not get it to work properly so i think yours would better.

[settingslist.zip](https://github.com/pihome-shc/pihome/files/4306969/settingslist.zip)

twa127, 2020-03-09:
Hi,

Looks like we were thinking on the same lines.

I did not know whether to allow the selected sub-menu to stay open or close it when another menu is chosen as you have done.

dvdcut, 2020-03-09:
i think it will be confusing for ordinary people at first glance, may be best to hide first set of icons when displaying second, third or fourth, my version still have problems as you can see its hiding but not moving icons up next to displayed icons.

twa127, 2020-03-09:
dvdcut - attached your version mixed with mine
[settingslist.zip](https://github.com/pihome-shc/pihome/files/4308585/settingslist.zip)

pihome-shc, 2020-03-09:
@twa127 / @dvdcut
As always great work. few suggestions: change those icons as @twa127 had them in his version, add two <br>after icons list, add default load icon where you had shutdown, reboot and thank you icon. also worth adding one line description for each category

twa127, 2020-03-09:
update my version
[settingslist.zip](https://github.com/pihome-shc/pihome/files/4308798/settingslist.zip)

twa127, 2020-03-09:
what will default load do?

pihome-shc, 2020-03-09:
@twa127
i think your version mixed with @dvdcut  version looks lot better and with that i can not see shutdown, reboot and thank you icon.

twa127, 2020-03-09:
Update with a bit of help text when hovering over icons.
[settingslist.zip](https://github.com/pihome-shc/pihome/files/4308911/settingslist.zip)

pihome-shc, 2020-03-10:
@twa127 / @dvdcut
i have combined your ideas into this, see what you both think and if happy can you do pull request.
[settingslist.zip](https://github.com/pihome-shc/pihome/files/4315144/settingslist.zip)

twa127, 2020-03-11:
Looks good to me

Sent from my iPhone

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

twa127, 2020-03-11:
Just a thought - why not enter settings with all sub menus closed. Also I don’t think shutdown and reboot sit logically in the status menu, which is why I left them on the main settings screen.

Sent from my iPhone

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

pihome-shc, 2020-03-11:
Yes, that is good idea, lets do that then.

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

dvdcut, 2020-03-11:
i love the way it worked out, @twa127 is right shutdown and reboot do not sit in status, i made some improvements to @pihome-shc combined version. i m happy with this

[settingslist.zip](https://github.com/pihome-shc/pihome/files/4317645/settingslist.zip)

twa127, 2020-03-11:
I've tidied up a bit, left thanks in the status menu and added the following lines to en.php:

$lang['tooltip_1'] = "System Status Displays";
$lang['tooltip_2'] = "System Configuration Menus";
$lang['tooltip_3'] = "Boiler Configuration Menus";
$lang['tooltip_4'] = "Node and Zone Configuation";
$lang['system_status'] = "System Status";
$lang['system_configuration'] = "System Configuration";
$lang['boiler_configuration'] = "Boiler Configuation";
$lang['node_zone_configuration'] = "Node and Zone Configuation";

[settingslist.zip](https://github.com/pihome-shc/pihome/files/4319093/settingslist.zip)

pihome-shc, 2020-03-11:
great work, can you do pull request for this now, i think its ready to be implemented.

MindaugasMeskauskas, 2020-03-13:
Works nicely, well done.
But have one observation, tab icons are too small for small touchscreen devices. Tried to fix, but I'm not good with CSS.

twa127, 2020-03-14:
Latest version has slightly larger icons, is that better

Sent from my iPhone

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

twa127, 2020-03-30:
Hi,

I was thinking that 'Services' might be better in the System Configuration menu as now both the MQTT and Amazon Echo services can be configured here

Closed 2020-04-19.

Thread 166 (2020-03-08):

Remove Default Values from Database

pihome-shc, 2020-03-08:
Remove all default values from database and add those values in code so system do not rely on default values where information isnt added via code. fixing this issue will help **#57 Process to update PiHome and Database** and streamline the code for updates and it will remove MySQL/MariaDB version dependency.

twa127, 2020-03-09:
Sounds okay to me, you would need to populate the user table via code otherwise you could not get in to the application at all

dvdcut, 2020-03-09:
in my experience with update_db.php is strange i thought its something to do with my setup even though i m using img file from pihome website. but it keep asking me to update default values.

twa127, 2020-03-09:
I'd also not display the the Boiler icon on the home screen until there was an entry in the boiler table

twa127, 2020-03-09:
dvdcut - had a similar problem in the past was due to using an older version of MySQL/MariaDB, so this change would fix that problem.

twa127, 2020-03-10:
I'll post an update for the boiler model to enable creation of the initial boiler record

twa127, 2020-03-14:
Getting quite close to a solution for this, a couple of points:

1. The user table need to be populated to allow initial access to the WEB interface
2. The system table needs to be populated to identify version and build values

These could be populate using a couple of INSERT queries in setup_db.php
The initial setup of the system could then be performed from the WEB interface -

1. Configure nodes either automatically or manually for GPIO and I2C
2. Configure boiler from boiler model
3. Configure Zones
4. Configure schedules

pihome-shc, 2020-03-14:
@twa127
yes you are right, basic database we have at the moment with some basic entries would be the default ones, i.e user and system related information and i think no need to insert them during setup_db.php.

or you are thinking to making web based installer without any information in database file? but in either case lots of code needs to be changed to remove default values, for example right now nodes related info fully populated from gateway script. and same for holiday schedule left null.

twa127, 2020-03-15:
I think the latest commit will allow us to use a completely empty database file, with version and build numbers in the config.ini file, setupdb.php will be used to populate user and system tables.

Please give the attached a try

[setup_db.zip](https://github.com/pihome-shc/pihome/files/4333997/setup_db.zip)

pihome-shc, 2020-03-15:
@twa127 looks good, i think having blank database will help updating database easy and clean, also future pull request can only update **db_config.ini** with build number and this will limit messing up database file.

twa127, 2020-03-15:
Still need to add create default away and holidays tables to zones.php when the first zone is created, I'll add that to the next commit

twa127, 2020-03-15:
Do you want me to commit this update

pihome-shc, 2020-03-16:
@twa127, did you already commit this update?

twa127, 2020-03-16:
No, I’ll do it in the morning if your happy with it

Sent from my iPhone

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

pihome-shc, 2020-03-16:
Second Part of this updated was to eliminate any default values from database, for instance boiler table have some default values,

CREATE TABLE `boiler` (
	`id` INT(11) NOT NULL AUTO_INCREMENT,
	`sync` TINYINT(4) NOT NULL **DEFAULT '0',**
	`purge` TINYINT(4) NOT NULL **DEFAULT '0'** COMMENT 'Mark For Deletion',
	`status` TINYINT(4) NULL DEFAULT '0',
	`fired_status` TINYINT(4) NULL **DEFAULT '0'**,
	`name` CHAR(50) NULL **DEFAULT 'Gas Boiler'** COLLATE 'utf16_bin',
	`node_id` INT(11) NULL **DEFAULT NULL**,
	`node_child_id` INT(11) NULL **DEFAULT '1'**,
	`hysteresis_time` TINYINT(4) NULL **DEFAULT '3'**,
	`max_operation_time` TINYINT(4) NULL **DEFAULT '60',**
	`datetime` TIMESTAMP NULL **DEFAULT current_timestamp() ON UPDATE current_timestamp(),**
	PRIMARY KEY (`id`) USING BTREE,
	INDEX `FK_boiler_zone` (`node_id`) USING BTREE,
	CONSTRAINT `FK_boiler_zone` FOREIGN KEY (`node_id`) REFERENCES `pihome`.`nodes` (`id`) ON UPDATE RESTRICT ON DELETE RESTRICT
)
COLLATE='utf8_general_ci'
ENGINE=InnoDB
AUTO_INCREMENT=2
;

removing these values will help me to further work on #24 PiConnect Improvements and #57 Process to update PiHome and Database.

twa127, 2020-03-17:
okay I will work on that before I commit the empty database, I think the date related defaults will be the biggest problem as some of the UPDATE queries rely on the default.

twa127, 2020-03-17:
Do you want to remove all the default values from every table

Sent from my iPhone

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

pihome-shc, 2020-03-17:
Yes where possible. I can work with you if you wand to devide work with me.

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

twa127, 2020-03-17:
I’ll plod on for now, away, boiler, holidays  and gateway are done

Sent from my iPhone

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

twa127, 2020-03-17:
Also boost, email and frost_protection are done, working on the message queues

Sent from my iPhone

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

pihome-shc, 2020-03-17:
Thank you.

twa127, 2020-03-19:
I think that I've now changed all the INSERT INTO queries. I've setup my test system successfully from an empty database which has no default clauses.

Please give the attached a try

[setup_db.zip](https://github.com/pihome-shc/pihome/files/4354534/setup_db.zip)

pihome-shc, 2020-03-20:
@twa127 Great work,
couple of things

Boiler:
Enable Boiler checkbox is disabled but after i add boiler records it set that to enable
Schedule:
schedulelist.php have two extra </div> at line 139 and 140
when adding schedule it leaves holidays_id column as null, may be add 0 instead of null value
Boost:  (sb-admin-2.css)
.chat li.left .chat-body padding-top: 10px;
987 canceling out 233
Holidays
holidaylist.php have extra </div > on line 156
enabling and disable schedule does not reload holidayslist.php file but it works on holiday dates.

twa127, 2020-03-20:
Hi

Can you please explain what you mean:

Schedule:
schedulelist.php have two extra at line 139 and 140

Sent from my iPhone

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

pihome-shc, 2020-03-20:
@twa127

Schedule:
schedulelist.php have two extra div  at line 139 and 140

Holidays
holidaylist.php have extra div  on line 156

twa127, 2020-03-20:
I see and agree that they are both wrong, but they have not been changed in this latest batch of updates, so the errors are historical.

I use grep -o '<div' schedulelist.php | wc -l to count the number of opening div and then grep -o '</div' schedulelist.php | wc -l to count the number of closing div, the numbers should obviously match.

I will investigate and fix both files if you want?

pihome-shc, 2020-03-20:
@twa127 that is great way of calculating.
with those extra div panel footer isnt in its correct place.
can you push these changes please.

twa127, 2020-03-20:
okay will do

twa127, 2020-03-20:
Boost: (sb-admin-2.css)
.chat li.left .chat-body padding-top: 10px;
987 canceling out 233

You committed this change on 14 Dec 2019, I'm not sure which one is correct

pihome-shc, 2020-03-20:
@twa127,
i m working on PiConnect script and null values are problematic thats why it has to be 0 if schedule isnt belongs to holiday.

twa127, 2020-03-20:
okay, I'll give the problem some thought :-)

twa127, 2020-03-20:
Okay, now changed

Sent from my iPhone

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

dvdcut, 2020-03-26:
@twa127
my gateway is keep failing with error in log file

```
### 2020-03-26 14:38:50,570 - ERROR ###
Traceback (most recent call last):
  File "/var/www/cron/gateway.py", line 245, in <module>
    timestamp = datetime.datetime.now().strftime('%Y-%m-%d %H:%M:%S')
NameError: name 'datetime' is not defined

### 2020-03-26 14:42:37,333 - ERROR ###
Traceback (most recent call last):
  File "/var/www/cron/gateway.py", line 258, in <module>
    timestamp = datetime.datetime.now().strftime('%Y-%m-%d %H:%M:%S')
NameError: name 'datetime' is not defined

### 2020-03-26 14:43:18,794 - ERROR ###
Traceback (most recent call last):
  File "/var/www/cron/gateway.py", line 258, in <module>
    timestamp = datetime.datetime.now().strftime('%Y-%m-%d %H:%M:%S')
NameError: name 'datetime' is not defined

### 2020-03-26 14:44:31,136 - ERROR ###
Traceback (most recent call last):
  File "/var/www/cron/gateway.py", line 258, in <module>
    timestamp = datetime.datetime.now().strftime('%Y-%m-%d %H:%M:%S')
NameError: name 'datetime' is not defined
```

pihome-shc, 2020-03-29:
@twa127 sorry if i missed anything but i still see database have all the values, i.e its not blank.

twa127, 2020-03-30:
Not committed the empty one yet as I was not sure you were happy with it, just let me know and I’ll do it

Sent from my iPhone

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

pihome-shc, 2020-03-30:
@twa127
let me test this one last time and after this you can do pull request, i'll be using reference to this attachment.
https://github.com/pihome-shc/pihome/issues/166#issuecomment-601154249

twa127, 2020-03-30:
Okay

Sent from my iPhone

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

pihome-shc, 2020-03-30:
@twa127
**Setting->Gateway**
Language missing, some extra fields are showing but when gateway type is select then right fields are displayed. toggle isn't working as it suppose to work. everything works as it should.

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
you can do pull request for database.

twa127, 2020-03-31:
Hi

Is this problem fixed now?

pihome-shc, 2020-03-31:
@twa127 yes, language issue is fixed i think you can do pull request for database. i'll change documentation to include extra steps.

twa127, 2020-03-31:
Okay will do

Sent from my iPhone

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

dvdcut, 2020-05-22:
can i suggest here something:
can we keep some defaults data in database, like boiler and two zone, one heating second hotwater.

pihome-shc, 2020-05-27:
@dvdcut is there any reason you want to have two zone and boiler record in database?

dvdcut, 2020-06-06:
when i was installing my dev system from github i had some issues, may be adding boiler and one zone will make few things out of the box work and make it more plug and play type

pihome-shc, 2020-06-06:
@twa127 did great job on clean-up work on database, i know it is confusing as documentation is missing for fresh install, specially if some one is trying to install from scratch.

adding boiler record wouldn't hurt but it has to added from [setup.php](https://github.com/pihome-shc/pihome/blob/master/setup.php) and [setup_db.php](https://github.com/pihome-shc/pihome/blob/master/MySQL_Database/setup_db.php) files.

Closed 2020-07-02.

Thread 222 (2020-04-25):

Python 3

twa127, 2020-04-25:
Do you think we should consider migrating to the latest version of python?

pihome-shc, 2020-04-25:
Up until now single image is compatible with all versions of rpi, do you think moving to altes version of python will make single image compatible across all rpi models?

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

pihome-shc, 2020-04-25:
i have rpi 3, 4 and zoro w, if you need testing i can do this for you no problem,

twa127, 2020-04-25:
can't see why not Raspian comes with Python 2 & 3, only reason for asking is that 2 is now obsolete

pihome-shc, 2020-04-25:
then i dont see any problem updating to version 3

twa127, 2020-04-25:
oh dear I need to upskill then :-)))

pihome-shc, 2020-04-25:
You asked for it :)

dvdcut, 2020-04-27:
python isnt major part of pihome i think only place python is used is gateway or i2c relay.

harvybob, 2020-04-27:
I packed away my test pi, but i will set it up tonight and test i2c with python3 - i ran the upgrade utility and the only changes made were the comments so fingers crossed with that side!

pihome-shc, 2020-04-28:
@harvybob,
did you mange you test your 12c relay with python version 3?

harvybob, 2020-04-28:
both easyi2c.py and i2c_relay.py (both needed together) work on python 3.5

pihome-shc, 2020-05-09:
Free python 3 course if anyone interested, don’t know how good is this one.

https://www.udemy.com/course/python-3-bootcamp-2020/?couponCode=PYTHON-LEARN

twa127, 2020-05-12:
Here is the updated python3 gateway code, I've been running it on both a serial and ethernet gateway for over 24 hours, please let me know what you think

[cron.zip](https://github.com/pihome-shc/pihome/files/4616551/cron.zip)

dvdcut, 2020-05-12:
Notes to Python3 as @twa127 mentioned in other issue:
Check version of pthon you have:
`python --version`
Set python 3 as default:
`nano ~/.bashrc`
Add the following after the last line in the file
`alias python='/usr/bin/python3'`
To implement the change:
`source ~/.bashrc`

Remember that after this if you want to run python 2 code you will have to call as phython2 e.g python2 /var/www/cron/gateway.py (to run the existing gateway script)
Also you need to install phthon3 mysql library
`sudo apt-get install python3-mysqldb`

dvdcut, 2020-05-12:
@twa127,
dont know what is wrong but find_mygw3.py isnt finding my gateway, i deliberately changed ip to wrong one in my database for gateway and killed exiting process to let check_gw3.php find gateway but after over one hour still not found. but then i run old scrip `python2 /var/www/cron/find_mygw/find_mygw.py` and in few minuts it found gateway. dont know what is wrong with find_mygw3.py

twa127, 2020-05-12:
okay I'll have a look, it uses an updated version of ping.py, so maybe it's something related to that

twa127, 2020-05-12:
I did not notice that ping.py had been doctored to return when the ip/port was discovered. Implemented the same process for ping3.py, so should now find the gateway

[ping3 .zip](https://github.com/pihome-shc/pihome/files/4617647/ping3.zip)

pihome-shc, 2020-05-12:
@twa127  / @dvdcut great work, i just tested and it is working for me with your latest ping3.py,
also steps for setting python3 as default worked as well.

twa127, 2020-05-12:
good news, so most of the python now works with version 3, I'll mop up the rest

do you want to stick with the '3' in the file names or should be drop it?

pihome-shc, 2020-05-12:
i lets move to python 3 and keep old name (remove 3 from the name)

pihome-shc, 2020-05-12:
@harvybob can you test your i2c relay with python 3

twa127, 2020-05-12:
I think we could do i2c using 'blinka' but I don't have an i2c relay to play with. I've moved my boiler watchdog display over to blinka using SPI, did have a few problems but they were down to the beaglebone kernel naming conventions tor the SPI ports
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

pihome-shc, 2020-05-12:
@twa127 that display looks great, i also monitor my flow temperature. but not return temperature, did you put any intelligence based on flow and return temperature?

to test i2c @harvybob is the only one who have i2c relay board.

twa127, 2020-05-12:
Nope the main function is to monitor the fault condition and attempt to reset the boiler x times to clear the fault. The main fault condition is due to the return temp not tracking the flow temp in a given time, so the boiler thinks there is a blockage, hence I display both and the boiler has flow and return thermistors which return current temps

harvybob, 2020-05-13:
> @harvybob can you test your i2c relay with python 3

Mine work fine - do you want me to push the new code? tbh the only code that needed changing was the comments put in for PiHome!

(i have not done a full pull of the new code - just tested the i2c relay board itself!)

harvybob, 2020-05-13:
> @twa127 / @dvdcut great work, i just tested and it is working for me with your latest ping3.py,
also steps for setting python3 as default worked as well.

Just a thought, the change to 3 using profile may not work when running cron jobs? (a good few years back when i was working on RHEL 5 we had problems where changes in the profile didnt work in the script. As part of crontab or the job itself we had to invoke the profile...

twa127, 2020-05-13:
Morning

We execute call gpio_ds18b20.py and notice.py as cron jobs, the rest are called from within php code.

We could execute as, for instance , python3 gpio_ds18b20.py then no need to make python 3 the default.

I don't think the pycache folder gets created in every instance, for example running gpio_ds18b20.py or notice.py does not create a pycache folder, but find_mygw does, but in fact this is little different to the current python2 find_mygw which produces a ping.pyc file rather than the  __pycache__ folder produced by the python3 version

I

twa127, 2020-05-13:
"When you import a module, Python stores the compiled bytecode in that directory so that future imports can use it directly, rather than having to parse and compile the source again. It does not do that for merely running a script, only when a file is imported. (Previous versions used to store the cached bytecode as .pyc files that littered up the same directory as the .py files, but starting in Python 3 they were moved to a subdirectory to make things tidier.)"

In the case if find_mygw.py ping is imported and for i2c_relay.py  easyi2c is imported and this is where the .pyc file or  __pycache__ directory get created.

harvybob, 2020-05-13:
Personally i think doing this
` python3 gpio_ds18b20.py `

would be a better way - a bit more work  but it will mean if other people dont make 3 the default etc then it wont cause problems ,plus at some point when 4 comes round and we migrate to 4, we will know which ones are 3 and 4 etc.

The pycache is just to keep github tidy! as soon as someone runs the code it will get created anyway, but github doesnt need the cache'd files does it?

twa127, 2020-05-13:
we have already sent a precedent in boiler.php by executing the new gpio relay code with python3, so it gets my vote :-)

I don't see the need to distribute the pycache directories as they get created at run time, where required.

dvdcut, 2020-05-13:
i can see in boiler.php  both ways its not unified,

`exec("python3 /var/www/cron/gpio/gpio3_relay.py " .$boiler_node_child_id ." ".$relay_on );`
and
`exec("python /var/www/cron/i2c/i2c_relay.py" .$boiler_node_id." ".$boiler_node_child_id." 1"); `

i m based on pihome img file so all the hard work will be done for me by author :)

twa127, 2020-05-13:
Hi,

Yes that's because we have already deployed the python3 gpio relay code, but not yet deployed the i2c update to python3

harvybob, 2020-05-13:
I've pushed #231  to add two new files for the i2c relays. Boiler.php has NOT been updated - i need to rebuild my setup with the current code - I have a VM where my main code runs, along with the database, and then a PI which does the DS and actual relays... need to rebuild both but need to do a full rebuild for db which will take time.

twa127, 2020-05-13:
can someone give this a try please, you need to execute with python3 gpio_ds18b20.py

[gpio_ds18b20.zip](https://github.com/pihome-shc/pihome/files/4621698/gpio_ds18b20.zip)

dvdcut, 2020-05-13:
@twa127 i tested this and it worked for me, i even deleted my exiting ds sensors from database to check it if creates them again or not, and that worked as well.

twa127, 2020-05-13:
great, the changes were only cosmetic

pihome-shc, 2020-05-13:
@dvdcut thank you for testing this, @twa127 can you do pull request for ds18b20 sensors please. i m planing to another release over weekend and want to get added in next version.

twa127, 2020-05-13:
Okay, I'll do all the python3 updates using existing naming (ie no 3)

harvybob, 2020-05-13:
updated boiler.php to refer to python3 #235 for the i2c control.

pihome-shc, 2020-05-13:
@twa127
i m getting this error while starting gateway.py file
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
twa127, 2020-05-14:
Very sorry I did not really make myself plain. This version of fauxmo is very different from the python2 one we are currently using, to test we do not need to use any of the existing installation process. The advantage to this one is that it is maintained, see https://github.com/n8henrie/fauxmo

To test:

1. Install faxmon with - pip3 install fauxmo
2. create config directory with - mkdir /etc/fauxmo
3. copy the config.json file I sent before with - cp config.json /etc/fauxmon
4. edit /etc/fauxmon/config.json and change the zonename to match your setup (using %20 for any white spaces)
5. start with verbose debugging using - fauxmon -vv
6. echo should be able to discover the new Test Switch

pihome-shc, 2020-05-14:
@twa127
i tested echo without modifying anything and it worked, can we produce zone names automatically?

```
root@pihome:~# fauxmo -vv
2020-05-14 14:35:50 fauxmo:42       INFO     Fauxmo v0.5.0
2020-05-14 14:35:50 fauxmo:51       INFO     Using config: /etc/fauxmo/config.json
2020-05-14 14:35:50 fauxmo:136      INFO     Starting UDP server
2020-05-14 14:35:57 fauxmo:57       INFO     setup.xml requested by Echo
2020-05-14 14:35:57 fauxmo:66       INFO     request BasicEvent1
2020-05-14 14:35:57 fauxmo:140      INFO     Attempting to get state for Test Switch
2020-05-14 14:35:57 fauxmo:146      INFO     Test Switch state: off
2020-05-14 14:35:59 fauxmo:66       INFO     request BasicEvent1
2020-05-14 14:35:59 fauxmo:140      INFO     Attempting to get state for Test Switch
2020-05-14 14:35:59 fauxmo:146      INFO     Test Switch state: off
2020-05-14 14:36:13 fauxmo:57       INFO     setup.xml requested by Echo
2020-05-14 14:36:53 fauxmo:66       INFO     request BasicEvent1
2020-05-14 14:36:53 fauxmo:162      INFO     Attempting to turn on Test Switch
2020-05-14 14:36:53 fauxmo:66       INFO     request BasicEvent1
2020-05-14 14:36:53 fauxmo:140      INFO     Attempting to get state for Test Switch
2020-05-14 14:36:53 fauxmo:146      INFO     Test Switch state: on
2020-05-14 14:37:11 fauxmo:57       INFO     setup.xml requested by Echo
2020-05-14 14:37:11 fauxmo:66       INFO     request BasicEvent1
2020-05-14 14:37:11 fauxmo:157      INFO     Attempting to turn off Test Switch
2020-05-14 14:37:11 fauxmo:66       INFO     request BasicEvent1
2020-05-14 14:37:11 fauxmo:140      INFO     Attempting to get state for Test Switch
2020-05-14 14:37:11 fauxmo:146      INFO     Test Switch state: off
```

twa127, 2020-05-14:
Hi,

That's good news, I'll come up with an install.sh to install, modify the service and build the config.json similar to the homekit solution and commit when ready

pihome-shc, 2020-05-14:
@twa127,
Thank you for your hard work.

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

harvybob, 2020-05-15:
Just noticed a typo in boiler.php with reference to i2c_relay.py pushing the fix - to add a space after the .py

Only affects i2c

pihome-shc, 2020-06-06:
@twa127 Any more work needed for python 3 or can this issue be closed?

twa127, 2020-06-06:
Hi

I think it’s safe to close

Sent from my iPhone

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

Closed 2020-06-06.

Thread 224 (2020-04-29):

Gateway script with wired and wireless ds18b20

dvdcut, 2020-04-29:
This looks some bug in the gateway.py script,
background:
i added two wired sensors to raspberry pi and enable cron job for ds18b20 sensors and it worked ok as expected.
when i power on wireless sensors gateway.py script keep terminating and i think it is related to node id of wired sensors node_id.
**one example of error:**
```
Size of the String Received:  41
Date & Time:                  Wed Apr 29 15:32:32 2020
Full String Received:         32;255;0;0;17;2.3.1\n
Full Statement Received:      ['32', '255', '0', '0', '17', '2.3.1\n']
Node ID:                      32
Child Sensor ID:              255
Message Type:                 0
Acknowledge:                  0
Sub Type:                     17
Pay Load:                     2.3.1
/var/www/cron/gateway.py:182: Warning: (1292L, "Truncated incorrect DOUBLE value: '28-03156520b4ff                                                                                     '")
  cur.execute('SELECT COUNT(*) FROM `nodes` where node_id = (%s)', (node_id, ))
/var/www/cron/gateway.py:182: Warning: (1292L, "Truncated incorrect DOUBLE value: '28-01156572dbff                                                                                     '")
  cur.execute('SELECT COUNT(*) FROM `nodes` where node_id = (%s)', (node_id, ))
1: Node ID: 32  Already Exist In Node Table, Updating MS Version
DB Error 1292: Truncated incorrect DOUBLE value: '28-03156520b4ff                                                                                     '
More info in log file: /var/www/logs/main.log
### 2020-04-29 15:32:32,225 - ERROR ###
Traceback (most recent call last):
  File "/var/www/cron/gateway.py", line 194, in <module>
    cur.execute('UPDATE nodes SET ms_version = %s where node_id = %s', (payload, node_id))
  File "/usr/lib/python2.7/dist-packages/MySQLdb/cursors.py", line 250, in execute
    self.errorhandler(self, exc, value)
  File "/usr/lib/python2.7/dist-packages/MySQLdb/connections.py", line 50, in defaulterrorhandler
    raise errorvalue
OperationalError: (1292, "Truncated incorrect DOUBLE value: '28-03156520b4ff
```

i have warped node_id with single ' after many tries i got it working but now it is presenting 3 more problems,
i. it does not update sensor name
ii. it does not update sketch version
iii. each time i reset sensor it create new entry in node table again without name and sketch version.

on screen it present all ok but db update not happening. i can not fix this issue. see attached gateway.zip file, may be there is better way to address this.

can any one looks at this please.
[gateway.zip](https://github.com/pihome-shc/pihome/files/4552494/gateway.zip)

twa127, 2020-04-29:
node_id is an integer and the node_id column is CHAR, so hence the error, you could try replacing line 182 with -

        query = 'SELECT COUNT(*) FROM `nodes` where node_id = ' + str(node_id)
        cur.execute(query)

twa127, 2020-04-29:
Only happens when you have ds18b20 sensors nodes in the table

dvdcut, 2020-04-29:
i installed wired sensors on my raspberry pi to monitor spare room temperature. if that is question then yes it only happened since in installed wired sensor.
this time after resting sensors few times it didnt create multiple entries for same sensors but still name and sketch version is missing.

```
Size of the String Received:  41
Date & Time:                  Wed Apr 29 22:31:19 2020
Full String Received:         32;255;0;0;17;2.3.1\n
Full Statement Received:      ['32', '255', '0', '0', '17', '2.3.1\n']
Node ID:                      32
Child Sensor ID:              255
Message Type:                 0
Acknowledge:                  0
Sub Type:                     17
Pay Load:                     2.3.1
/var/www/cron/gateway.py:184: Warning: (1292L, "Truncated incorrect DOUBLE value: '28-03156520b4ff                                                                                     '")
  cur.execute(query)
/var/www/cron/gateway.py:184: Warning: (1292L, "Truncated incorrect DOUBLE value: '28-01156572dbff                                                                                     '")
  cur.execute(query)
1: Adding Node ID: 32 MySensors Version: 2.3.1

```
Here are the changes.
```
				# ..::Step One::..
				# First time Temperature Sensors Node Comes online: Add Node to The Nodes Table.
				if (node_id != 0 and child_sensor_id == 255 and message_type == 0 and sub_type == 17):
				#if (child_sensor_id != 255 and message_type == 0):
					#cur.execute('SELECT COUNT(*) FROM `nodes` where node_id = (%s)', ('node_id', ))
					query = 'SELECT COUNT(*) FROM `nodes` where node_id = ' + str(node_id)
					cur.execute(query)
					row = cur.fetchone()
					row = int(row[0])
					if (row == 0):
```

twa127, 2020-04-29:
yeah I'm sure you have identified a bug in gateway.py script, I can reproduce by creating a dummy ds18b20 node, I'll try adding a wireless node and see what happens

twa127, 2020-04-29:
quick test - added a single mysensor node with no name or sketch_version

dvdcut, 2020-04-29:
yes i did :( but what is the fix for this, you have better control over python

twa127, 2020-04-30:
Good Morning

please try this

[gateway.zip](https://github.com/pihome-shc/pihome/files/4556737/gateway.zip)

dvdcut, 2020-04-30:
just like that, waoo, that is great and it worked, i haven't restarted any other nodes, do you think it will be ok for other wireless nodes ?
```
node_id = str(statement[0])
```

twa127, 2020-04-30:
Glad it worked okay, yeah should be okay for the wireless nodes, I deleted one and it came back okay.

Do you think we should have a new 'type' for these ds18b20 sensors, as calling them GPIO means they show up in the nodes settings gui?

twa127, 2020-04-30:
We could call them GPIOSensor

dvdcut, 2020-04-30:
i didnt notice they show up in nodes, but not you got me thinking should we rename nodes to wired node, Yes GPIOSensors is good option

twa127, 2020-04-30:
yep would only then need a little tweak in model.php
change $query = "SELECT * FROM nodes where type != 'MySensor';";
to $query = "SELECT * FROM nodes where type not like '%Sensor';";

pihome-shc, 2020-04-30:
@twa127/ @dvdcut i did test and pull request worked great, anything else you need or can this issue be closed ?

twa127, 2020-05-01:
Okay for me

Sent from my iPhone

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

dvdcut, 2020-05-01:
@twa127 thank you for fixing this. i will close this issue now,

Closed 2020-05-01.

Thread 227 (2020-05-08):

python error for physical gpio

dvdcut, 2020-05-08:
i think space is missing and small other things.
```
2020-05-08 11:09:25 - Zone: Sensor Reading     29.80
2020-05-08 11:09:25 - Zone: Weather Factor     0.6
2020-05-08 11:09:25 - Zone: DeadBand           0.5
2020-05-08 11:09:25 - Zone: Temperature        30.9
2020-05-08 11:09:25 - Zone ID: 35
2020-05-08 11:09:25 - Zone: Hot Water Controller: 0 Controller Child: 33 Zone Status: 0
2020-05-08 11:09:25 - Zone: Hot Water Stop Cause: No Schedule - Target C:0 Zone C:30.4
2020-05-08 11:09:25 - Zone: GIOP Relay Status: 1 (0=On, 1=Off)
----------------------------------------------------------------------------------------
2020-05-08 11:09:25 - Boiler Switched Off At: 2020-05-08 07:44:02
python3: can't open file '/var/www/cron/gpio/gpio3_relay.py35': [Errno 2] No such file or directory
2020-05-08 11:09:25 - Boiler GIOP: 35 Status: 1 (0=On, 1=Off)
2020-05-08 11:09:25 - Boiler Fired Status: 0
2020-05-08 11:09:25 - Boiler Hysteresis Status: 0
----------------------------------------------------------------------------------------
2020-05-08 11:09:25 - Boiler Script Ended

```

pihome-shc, 2020-05-08:
@dvdcut i had comments on PiHome website yesterday [Shaun Jepson](http://www.pihome.eu/2020/04/11/pihome-version-1-74/#comment-21325) had same issue, i thought he needed following dependencies installed. (i replied without ready :( )

```
sudo apt install python3-pip
sudo pip3 install RPI.GPIO
sudo pip3 install adafruit-blinka
```

pihome-shc, 2020-05-11:
@dvdcut any further testing needed? @twa127 you are the expert on python. anything else needed for this issue?

twa127, 2020-05-12:
I think we are okay with the gpio code, just need to make sure the dependences are installed, also need to add to the list -
sudo apt-get install python3-mysqldb

#222 need this one for the gateway code migration to python3. I've moved it across to python3 can you please test the attached gateway migration - the main change was to the serial read/write as python3 handles strings differently, I've included '3' in the filenames just to distinguish it from the old version, you will need to change the cron job from check_gw.php to  check_gw3.php and kill gateway.py if it's still running.

[cron.zip](https://github.com/pihome-shc/pihome/files/4614042/cron.zip)

dvdcut, 2020-05-12:
@twa127
i tried your code.
```
root@pihome:~# python /var/www/cron/gateway3.py
  File "/var/www/cron/gateway3.py", line 162
    print("Full String Received:         ",end = in_str)
                                               ^
SyntaxError: invalid syntax
```

twa127, 2020-05-12:
are you running under python3 by default, if not needs to be

python3 /var/www/cron/gateway3.py

dvdcut, 2020-05-12:
my mistake, how i can make python3 as default?
by running python3 /var/www/cron/gateway3.py it is working.

twa127, 2020-05-12:
you can check what is the current version by using python --version

to set python 3 as default - nano ~/.bashrc and at the following after the last line in the file

alias python='/usr/bin/python3'

remember that after this if you want to run python 2 code you will have to call as phython2 eg
 python2 /var/www/cron/gateway.py (to run the existing gateway script)

twa127, 2020-05-12:
I've been running both a serial and ethernet gateway with the python3 code for the last 24hours and so far no problems

dvdcut, 2020-05-12:
root@pihome:~# python --version
Python 2.7.16
root@pihome:~#

dvdcut, 2020-05-12:
```
root@pihome: ~ # python3 --version
Python 3.7.3
root@pihome:~#
```

dvdcut, 2020-05-12:
ok, its all looks ok, we have to make python 3 as default or call it with python3
one question inside check_gw3.php
you changed this
```
//if status set to 0 then check if gateway PID is running and if found then kill
if ($gw_status == '0') {
	//Gateway Python Script location
	$gw_script_txt = 'python /var/www/cron/gateway.py';
	//Check if Porocess is running and get its PID
	exec("ps aux | grep '$gw_script_txt' | grep -v grep | awk '{ print $2 }' | head -1", $out);
	if (count($out) > 1) {
		echo "\033[36m".date('Y-m-d H:i:s')."\033[0m - Gateway PID is: \033[41m".$out[0]."\033[0m \n";
		echo "\033[36m".date('Y-m-d H:i:s')."\033[0m - Stopping Python Gateway Script \n";
		//Kill Gateway Python Scrip PID
		exec("kill -9 '$out[0]'");
	} else {
		echo "\033[36m".date('Y-m-d H:i:s'). "\033[0m - Gateway is DISABLED \n";
	}
```
to this

```
//if status set to 0 then check if gateway PID is running and if found then kill
if ($gw_status == '0') {
	exec("ps -p $gw_pid", $output);
        if (count($output) > 1) {
	        echo "\033[36m".date('Y-m-d H:i:s'). "\033[0m - Stopping Python Gateway Script \n";
        	exec("kill -9 $gw_pid");
		echo $line;
        } else {
		echo "\033[36m".date('Y-m-d H:i:s'). "\033[0m - Python Gateway Script is DISABLED \n";
	}
```

twa127, 2020-05-12:
sorry I was not using the latest copy of check_gw, the only changes were to the python calls, updated current version attached

[find_mygw3.zip](https://github.com/pihome-shc/pihome/files/4616342/find_mygw3.zip)

dvdcut, 2020-05-12:
i was referring to check_gw3.php i didn't check find_mygw3.py

twa127, 2020-05-12:
oops sorry sent the wrong file :-(

[check_gw3.zip](https://github.com/pihome-shc/pihome/files/4616454/check_gw3.zip)

dvdcut, 2020-05-12:
can we close this issue and move this conversation to #222

twa127, 2020-05-12:
sounds a good idea to me, I'll repost the code to test in that tread

dvdcut, 2020-05-12:
closing this issue. now, gpio issue was resolved.

Closed 2020-05-12.

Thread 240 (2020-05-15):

Boost issue zone status not known (i2c?)

harvybob, 2020-05-15:
Hi Guys, I've updated to the latest software (the python 3 changes as of 15/5/20),
and have the following setup:

1) A VM running the database and the main code
2) A Pi2 B with DS18b20
3) A Pi1 B with two I2C relay Boards - IDs in the os as boards 32 and 33.

I created the nodes for the two relay boards - Type as I2C, Node ID as the board ID and number of children as 8.

I then went to add a Zone - the DS18B20 were already writing to the database so just a matter of selecting the correct relay board and relay, first issue: When i added the Nodes, it automatically creates the children as 1 to 8 - but my board needs 10-17. No matter - i manually changed the values on the Nodes table for the two boards to have a max child id of 17.

Then i go back to create the Node, and it needs a boilerID - now i dont have a boiler ID as my setup will be that the zone valve will activate the boiler?

I end up creating the boiler as my first I2C Node, and child 1 (note that i do not have a relay that will activate with the board id of 32, and relay id of 1!)

I've been testing various bits to make sure all is working and i've come across this error:
```----------------------------------------------------------------------------------------
2020-05-15 16:06:02 - Boost is Active for This Zone
2020-05-15 16:06:02 - Zone: Sensor Reading     24.06
2020-05-15 16:06:02 - Zone: Weather Factor     0.6
2020-05-15 16:06:02 - Zone: DeadBand           0.5
2020-05-15 16:06:02 - Zone: Temperature        25.16
2020-05-15 16:06:02 - Zone ID: 39
2020-05-15 16:06:02 - Zone: dining room Controller: 33 Controller Child: 16 Zone Status:
Traceback (most recent call last):
  File "/var/www/cron/i2c/i2c_relay.py", line 49, in <module>
    main()
  File "/var/www/cron/i2c/i2c_relay.py", line 40, in main
    status = int(sys.argv[3])
IndexError: list index out of range
2020-05-15 16:06:03 - Zone Relay Broad: 33 Relay No: 16 Status:
```

The error seen is because the Zone Status is not set - ie its not been populated.

Another Zone which is working is:

```
----------------------------------------------------------------------------------------
2020-05-15 16:06:03 - Zone: Sensor Reading     24.56
2020-05-15 16:06:03 - Zone: Weather Factor     0.6
2020-05-15 16:06:03 - Zone: DeadBand           0.5
2020-05-15 16:06:03 - Zone: Temperature        25.66
2020-05-15 16:06:03 - Zone ID: 40
2020-05-15 16:06:03 - Zone: kitchen Controller: 33 Controller Child: 15 Zone Status: 0
2020-05-15 16:06:03 - Zone: kitchen Stop Cause: No Schedule - Target C:0 Zone C:25.16
2020-05-15 16:06:05 - Zone Relay Broad: 33 Relay No: 15 Status: 0
----------------------------------------------------------------------------------------
```

I seem to recall this issue appearing previously -but never got to the bottom of it - something to do with the boost i think and being close to the target values.

pihome-shc, 2020-05-15:
when you i2c node, it ask for Number of Child Devices attached to Node, which gives max number of child devices number i.e if you add 10 it will give max number of child devices. but looks like its a bug where your child devices numbers are not starting from 1 to 10?

On you boiler, even your boiler isnt controlled by PiHome you still need one boiler entry in database.

harvybob, 2020-05-16:
> when you i2c node, it ask for Number of Child Devices attached to Node, which gives max number of child devices number i.e if you add 10 it will give max number of child devices. but looks like its a bug where your child devices numbers are not starting from 1 to 10?
>
> On you boiler, even your boiler isnt controlled by PiHome you still need one boiler entry in database.

I had to do that as the way my i2c board is numbered is 10-17. The way the code is setup is that it uses the childId to select which relay to activate

pihome-shc, 2020-05-16:
i think logic can be added for i2c child id as free text input,

harvybob, 2020-05-18:
To be honest im ok with it working this way - i tell it its child id 1-17, i just use 10-17 so dont need to change on my account. The status thing is more the issue. Throws an error when boost is set, the zone does not get a correct status.

pihome-shc, 2020-05-18:
@harvybob it looks like one one arrangement is passed to i2c python script, ie. status is blank
**2020-05-15 16:06:03 - Zone Relay Broad: 33 Relay No: 16 Status:**
i think best to change language for more clarity

```
$lang['node_child_id'] = "Child Devices";
$lang['node_child_id_info'] = "Number of Attached Devices for i2c max number of child id";
```

harvybob, 2020-05-19:
But ChildID 17 which is also active  works just fine, ,as does 16 when the temperature is lower then 24 degrees.

pihome-shc, 2020-05-22:
@harvybob do we need to do anything further on this issue?

harvybob, 2020-05-26:
Not sure - the error i guess is not having a status - which only happens when using boost..

pihome-shc, 2020-05-26:
@harvybob it only happens when you boost one zone and rest of the zone stay normal? can you do some testing and run boiler.php and send all output.

pihome-shc, 2020-06-06:
@harvybob can we close this issue? or any update?

twa127, 2020-06-07:
Just for info - i2c_relay.py expects 3 parameters in order to drive the BV4627, the first is the i2c address of the board (default is 32 decimal, I guess if you had 2 boards, you would change the address of the second board to 33 decimal), the second parameter is the relay number of the board (1 to 8) and the final parameter is the relay state (0 = off, 1 = on). The code requires all 3 parameters in the correct sequence, note that the existing code does not check that it is passed all 3 arguments.

My understanding of using 2 BV4627 boards with the existing python script, is that each board would have its individual i2c address and 8 child ids numbered 1 to 8

harvybob, 2020-06-08:
Hi twa127, The issue is that the status is unknown, not sure why but i cant get it to happen again at the moment (maybe because weather is hotter and already over the max set...

I have the boards set with different id's etc and that is all working.

pihome-shc, 2020-07-02:
@harvybob any further work required on this? can this issue be closed ?

harvybob, 2020-07-03:
Not that i can identify, I cant seem to test/get the same error now so i cant really dig any more.
May as well close.

Closed 2020-07-03.

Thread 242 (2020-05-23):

Frost protection icon

dvdcut, 2020-05-23:
today one of my wireless sensors was out of battery power and that zone went into frost protection but no icon was showing on gui only boiler icon was red and upon physical inspection of manifold i realized my ground floor heating was on and sensors hadn't reported as it was out of power. i think this is bug, also i think if i frost protection temperature is set to 0 then it will be disabled. may be changing info text for this as well.
`$lang['frost_protection_text'] = "System will protect itself against frost. To Disable projection you can set the temperature to 0";`

pihome-shc, 2020-05-27:
@dvdcut i will do some testing later and suggest the update.

pihome-shc, 2020-05-27:
@dvdcut,
if zone temperature sensors do not send reading for while and db_cleanup.php remove 3 days old value from the point db_cleanup.php run.
```
$query = "DELETE FROM messages_in WHERE datetime < DATE_SUB(curdate(), INTERVAL 3 DAY);";
```
i this issue is caused by interval between db_cleanup.php and value being 24h older. hence still shows in zone but boiler.php kick start zone as frost protection.

as far as frost protection disable goes that should do as well. if value is set to 0 then frost protection is disable.
can you do pull request for change in language please.

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

pihome-shc, 2020-05-27:
another option would be to change db_cleanup.php crontab to 10 0 * * * from 0 2 * * * or even run job once every 1 hour.

dvdcut, 2020-05-29:
if that is the case then fix is easy, why not remove old values more frequently ?

pihome-shc, 2020-05-29:
@dvdcut yes it would best to run cleanup cronjob more frequently, may be run it once every hour. i m going to change this in PiHome image as well.

pihome-shc, 2020-06-03:
closing this issue now, text is already added in frost protection model and clean-up job will be added once every hour in next img file for raspberry pi.

Closed 2020-06-03.

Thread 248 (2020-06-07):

Multi Zone Relay Module

twa127, 2020-06-07:
I have been looking at the existing i2c relay code, with the aim of bringing it in-line with the GPIO relay code. This has made me realize that the existing i2c solution is hardware specific, the code is tailored for the ByVac  BV4627 relay module and it appears that ByVac no longer trade, hence it's a bit of a dead-end.
Their do not appear to be many alternatives available and any i2c module with multiple relays will have its own specific way of controlling the individual relays, for example the Sparkfun Qwiic Quad Relay (COM-15102) uses a specific single byte to control each relay, while the BV4627 uses a sequence of bytes to select a relay and set its state.

For systems which require a large number of zone relays, some type of interface would be required to avoid using a large number of GPIO pins. The interface could be i2c or SPI, or 1-wire (even RS232). My initial thought is using an Arduino i2c 8  channel relay driver shield https://www.robotshop.com/uk/8-channel-relay-driver-shield.html coupled with perhaps a Arduino Uno and an off-the-shelf 8 relay module. The Uno could be configured as a wireless node with or without a temperature sensor. The 8  channel relay driver shield  is stackable so there is room for expansion. Any thoughts?

I've attached a single file python 3 i2c relay control for the BV4627 if anyone is in a position to test.

[i2cRelay.zip](https://github.com/pihome-shc/pihome/files/4742096/i2cRelay.zip)

harvybob, 2020-06-08:
Hi @twa127. I think I'm the only one using i2c at the moment - and im the only one with the ByVac boards!

ByVac has indeed stopped trading, DCS Electronics has taken over the hardware and will be looking to manufacture these in the future, however they did not get the licence for software so not sure where that leaves the support for these going forward.

With regards to the i2cRelay file, will it be used in the same way? board number, relay number and then on/off?

twa127, 2020-06-08:
Hi

Yes should work exactly the same way

Sent from my iPhone

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

harvybob, 2020-06-08:
Just downloading micropython as that is a dependency I do not have installed at the moment...

harvybob, 2020-06-08:
Having problems with micropython -

I downloaded the latest one - 1.12

untar'ed it.
cd mpy-cross
make

let it complete then tried to run the i2c script and got the following:

``` python3 i2cRelay.py 32 10 1

  _____    _   _    _
 |  __ \  (_) | |  | |
 | |__) |  _  | |__| |   ___    _ __ ___     ___
 |  ___/  | | |  __  |  / _ \  | |_  \_ \   / _ \
 | |      | | | |  | | | (_) | | | | | | | |  __/
 |_|      |_| |_|  |_|  \___/  |_| |_| |_|  \___|

    S M A R T   H E A T I N G   C O N T R O L

********************************************************
*   I2C Interface Relay Support Communication Script   *
*   Build Date: 11/09/2019 Version 0.02                *
*   Last Modified: 06/06/2020                          *
*                                 Have Fun - PiHome.eu *
********************************************************

Traceback (most recent call last):
  File "i2cRelay.py", line 33, in <module>
    from micropython import const
ImportError: No module named 'micropython'
```

twa127, 2020-06-09:
ok I'll come up with a version without micropython

twa127, 2020-06-09:
version with no micropython

[i2cRelay.zip](https://github.com/pihome-shc/pihome/files/4752761/i2cRelay.zip)

harvybob, 2020-06-10:
Had to install some additional software:
sudo apt-get install python3-pip
sudo pip3 install adafruit-circuitpython-busdevice

Once that was installed, the new i2c code works fine as follows:
to switch on relay A (10) on board 32:
'python3 i2cRelay.py 32 10 1

to switch off relay A (10) on board 32:
'python3 i2cRelay.py 32 10 0

I switched each on board 32 and 33 without problems
And i also learnt that

you can turn off all relays with:
'python3 i2cRelay.py 32 18 1

and
you can turn on all relays with:
'python3 i2cRelay.py 32 19 1

pihome-shc, 2020-07-02:
@twa127 any further update on this? or can this be closed ?

Closed 2020-07-03.

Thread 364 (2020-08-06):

Issue since v1.76 update

pihome-shc, 2020-08-06:
Received this from one user.

Hats off to you and the team on the latest release. Its really getting slick.

I've been following the github discussions with interest, and updated from 1.75 to 1.76 as soon as you sent the notification.

I noticed a few things since the update - but I'm not very familiar with github - I didn't know if I should raise these queries as bugs, but I figured I'd run them by you.

Issue since v1.76 update:
- Graphs no longer showing temperature - despite sensor's saving temp readings to database (otuside temp + cpu temp graphs are working fine though.
- 'network settings' blank in database - no new row created via migrate or update php scripts (I manually added an entry)
- 'node_id' blank in database - no new row created via migrate or update php scripts
- 'zone_graphs' blank in database - no new row created via migrate or update php scripts    I tried out the tasmota set-up - but i note that a number of the menu's in 'Settings' do not seem to save - so I have manually added the http command settings via phpmyadmin. For now the home gui is showing my tasmota relay's cycling on/off - but the command issued via pihome do not seem to be working I will need to dig into this further to see if I can figure out what is happening).

Kind regards,

twa127, 2020-08-06:
Hi,

Not sure why the graphs should be a problem
Network settings table not effected by either migrate or update so should remain in the same state as before or be empty
Not sure what you mean about node_id
zone_graphs table should not be effected by either migrate or update, I'll investigate
I fixed the http message GUI yesterday #360

twa127, 2020-08-06:
I think I can see the problem with the zone graphs, the query in gateway.py need to be amended to reflect the split zone table, I'll sort this out asap

twa127, 2020-08-06:
The current version of gateway.py uses absolute values to reference the columns in the select query used for zone_graphs table, I'll change this to reference the columns by name, just in case this is causing a problem

twa127, 2020-08-06:
the node_id table was added at #321 MySensors Nodes without ID and is populated as required by gateway.py

scottagecheeseandcrackers, 2020-08-06:
Hey guys - in the interest of working out any kinks - here is my SQL database backup from prior to the update. I hope this helps.
[pihome_2020-08-05_08-27-35.zip](https://github.com/pihome-shc/pihome/files/5037040/pihome_2020-08-05_08-27-35.zip)

@twa127 - I gave the sonoff / tasmota add-on a try. I managed to set-up a hallway lamp. The add 'zone http message' button would not allow me to save the power on command via the GUI. I tried adding the http message manually through phpmyadmin. If i locally login to my tasmota and cycle it - the pihome gui updates to show the state - but clicking the 'hallway lamp' symbol via pihome does not cycle the tasmota. I may need to dig further into this to figure out what is going on.

pihome-shc, 2020-08-06:
@twa127 graph issue is fixed after #365

twa127, 2020-08-06:
hi
@scottagecheeseandcrackers  I notice there is no 'zone_graphs' table in your database dump.

After #360 update you may need to delete your browser history to pickup the change to js/request.js, this should fix the http message GUI

twa127, 2020-08-07:
@scottagecheeseandcrackers when trying to debug your Sonoff, the first thing to check is that you have an entry in the messages_out table, this should have been created by the Add Zone process. Example below shows id = 92 entry for the Sonoff zone. You can manually set the Sonoff state by setting the payload to either 'Power ON' or 'Power OFF' and setting 'sent' to 0, gateway.py will then set the Sonoff the next time it cycles. Hope that helps
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

pihome-shc, 2020-08-08:
Any more work needed for this issue or. Can I close this issue?

twa127, 2020-08-08:
I think we have solved the issues mentioned in the original post

scottagecheeseandcrackers, 2020-08-08:
Apologies guys - was under a rock - missed the messages above.

@twa127  - Sonoff issue fixed with #360 - many thanks - really cool feature (I now have to see how many things around the house I can tasmota-ize)

zone_graphs is showing readings for the majority of my temperature sensors (for some reason one of them is missing)
But the graphs on the gui only show 2 temperature readings.
Also I'm not sure if you have implemented the battery voltage graph yet - but that too is blank.

pihome-shc, 2020-08-08:
@scottagecheeseandcrackers zone type nme are hard coded as heating and water make sure you have these two names as heating and water

twa127, 2020-08-08:
should have been no impact on battery voltage graphs, do you have anything in the nodes_battery table?

scottagecheeseandcrackers, 2020-08-08:
> @scottagecheeseandcrackers zone type nme are hard coded as heating and water make sure you have these two names as heating and water

@pihome-shc - my zone type table has these listed as 'Heating' and 'Hot Water'

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

scottagecheeseandcrackers, 2020-08-08:
> should have been no impact on battery voltage graphs, do you have anything in the nodes_battery table?

@twa127 - nodes_battery table fully populated for all sensors.

pihome-shc, 2020-08-08:
Change hot water to water in zone_type table

twa127, 2020-08-08:
Hi,

That's not going to work for all the current records in the zone_graphs table, might be a good idea to change the string test to look for sub-strings 'heating, 'water' and 'Immersion'

scottagecheeseandcrackers, 2020-08-08:
Sorry @twa127 - that went over my head...

twa127, 2020-08-08:
he he

Try using this for chart_load.php
[chart_load.zip](https://github.com/pihome-shc/pihome/files/5045443/chart_load.zip)

twa127, 2020-08-08:
I've looked at chart_batteryusage.php again and still can't see anything which should cause you to loose them after migrating the database. Can you post the first few records from your nodes_battery table please

scottagecheeseandcrackers, 2020-08-08:
@twa127
#
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

twa127, 2020-08-08:
That looks fine, I'll investigate further, did the updated chart_load.php fix your missing temperatures?

twa127, 2020-08-08:
Can you send me a screen shot of your nodes table please

scottagecheeseandcrackers, 2020-08-08:
> That looks fine, I'll investigate further, did the updated chart_load.php fix your missing temperatures?

Just rebooted the system to see any changes - I can now see my hot water temp reading alongside the outside temp.

Still missing a sensor reading though - perhaps it will appear as new readings are received.

scottagecheeseandcrackers, 2020-08-08:
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

twa127, 2020-08-08:
ah there is a check in chart_batteryusage.php for a valid min_value

$querya ="select * from nodes where `type` = 'MySensor' AND `name` LIKE '%Sensor' AND `min_value` <> 0;";

you need to set a min_value for all your nodes which are battery powered, hopefully that should fix the problem

scottagecheeseandcrackers, 2020-08-08:
Is the min_value for voltage or temp?

twa127, 2020-08-08:
% battery level threshold say for example 75, when the level falls below 75% it triggers a notification

scottagecheeseandcrackers, 2020-08-08:
> % battery level threshold say for example 75, when the level falls below 75% it triggers a notification

That fixed the voltage charts. Thanks

twa127, 2020-08-08:
great, so you happy with 1.76 now?

scottagecheeseandcrackers, 2020-08-08:
> great, so you happy with 1.76 now?

Great work. Fantastic build. Its really starting to out-perform other platforms.

twa127, 2020-08-08:
glad you like it :-)

Closed 2020-08-08.

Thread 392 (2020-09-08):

Releases 1.77

pihome-shc, 2020-09-08:
PiHome community always working hard to improve your smart home experience. Get the latest version for all of the available features. This release packed with some serious improvements and bug fixes.

# Highlights in This Release
There are over 100 changes to PiHome since Last release version 1.76, to name few of major changes:

#178 Fix for boiler and zone logs query
#387 Update to Sunset for Cat2 Zones #381 to enable offset against sunset time from weather api and improvement to formatting
#166 Changes to cron jobs - INSERT INTO queries changed to enable use of a database without DEFAULT values
#386 Change weather update check from 1 hour to 24 hours
#176 Enable creation of new frost protection record if table empty, tidy up email code section
#385 Enable use of sunset to start cat2 schedule, requires weather api, note: if schedule start time is set prior to sunset then this time is used to start schedule
#175 Create weather table record when database table empty
#382 Cosmetic change to display correctly when editing with nano
#174 Enable creation of new gateway record
#380 Fix to display min and max temperatures for 6 day weather
#173 Default away and holidays table creation
#172 Voice Command
#376 Fix to zone.php
#372 Update zone model display for cat2 zones and zones with multiple controllers
#369 Update chart_load.php to use sub-string as selection criteria
#164 Night Climate Scheduling added to scheduling.php
#367 Move max_operation_time to zone table (note; the zone table values will be NULL but not currently used anywhere)
#159 Fix Messages stalling in the Output Queue
#361 Bug Fix homelist.php (schedule running icon for add-on zones)
#360 Bug Fix Add HTTP Message GUI
#159 Bug Fix Gateway Python Script
#383 German translation (Thanks to Kevin)

## Full List of changes
https://github.com/pihome-shc/pihome/compare/1.76...master

# Contributors
Special thanks to the people who have contributed code and ideas to this release:
https://github.com/pihome-shc/pihome/graphs/contributors

# Important information
Update your PiHome Smart Heating installation even if you do not want to use new features, new release also include some bug fixes.

# How To update
Login to your PiHome via ssh and follow these steps to update your PiHome Smart Heating.

### Update Raspberry pi
sudo apt update
sudo apt upgrade

### Python 3 installation (if you are upgrading from older version)
sudo apt-get install python3-mysqldb
sudo apt-get install python3-pip
sudo pip3 install RPI.GPIO
sudo pip3 install adafruit-blinka
sudo pip3 install pyserial

### Set Python 3 as Default
python --version
Set python 3 as default:
nano ~/.bashrc
Add the following after the last line in the file
alias python='/usr/bin/python3'
To implement the change:
source ~/.bashrc

### Update PiHome Software
cd /var/www/
git pull origin

### Updated PiHome Database
cd MySQL_Database/
php update_db.php

### Migration Database
Execute the 'migrate_controller.php' file found in the directory 'MySQL_Database', this will update the database structure and migrate the existing controller records from zone table to zone_controller table, it will also update the views as required.

Update the other files in the normal manner.
cd /var/www/MySQL_Database/
php migrate_controller.php

## Wiring Pi Deprecated
Wiringpi is deprecated and no longer supported by PiHome, If you are using Raspberry pi GPIO to controller your zone or boiler make sure you update GPIO pin number, to physical pin number of your Raspberry pi.

## Help for Next PiHome Release
If you're interested in helping out please checkout GitHub for issue. If you like PiHome Smart Heating Controller please consider starring the project on GitHub and like us on Facebook (https://www.facebook.com/PiHomeHVAC)

### About PiHome and Its Evolution
http://www.pihome.eu/about-pihome-and-its-evolution/

pihome-shc, 2020-09-09:
@twa127 updated my dev. system and database migrated all good.

pihome-shc, 2020-09-11:
@twa127 when i setup new database it still requires migrate_controller.php, can these changes added to database for new setup so user don't need to run migrate_controller.php

twa127, 2020-09-11:
I left the database changes out because it caused problems when we did the sensor split migration. I thought leave it for a couple of days for most people to implement, then put in the database and view changes,

baseline-s, 2020-09-11:
Hi, Upgraded from 1.75 and had the following errors:

Applying Updates to Database.
MySQL Database Error with Query ALTER TABLE `zone` DROP `sensor_id`;
:Cannot drop index 'FK_zone_nodes': needed in a foreign key constraint
MySQL Database Error with Query ALTER TABLE `zone` MODIFY CONSTRAINT `FK_zone_type_id` FOREIGN KEY (`type_id`) REFERENCES `zone_type` (`id`);
:You have an error in your SQL syntax; check the manual that corresponds to your MariaDB server version for the right syntax to use near 'CONSTRAINT `FK_zone_type_id` FOREIGN KEY (`type_id`) REFERENCES `zone_type` (...' at line 1
MySQL Database Error with Query ALTER TABLE `zone` DROP INDEX `FK_zone_nodes`;
:Cannot drop index 'FK_zone_nodes': needed in a foreign key constraint

Additionally seem to have lost all my nodes and previous config.

twa127, 2020-09-11:
Hi,

I guess you probably had the same issue as @scottagecheeseandcrackers, I would suggest going back to a copy of the database before the update, then -

1. run migrate_db.php
2. run migrate_controller.php

DO NOT run update_db.php at any point

baseline-s, 2020-09-11:
Thanks, that solved the zone issues. load average is exceptionally high now with mysql taking most of the cpu. I'll have to dig deeper to understand why this is so. Running this on an old ModelB.

twa127, 2020-09-11:
yeah the load has crept up over the last few releases

Closed 2020-09-12.

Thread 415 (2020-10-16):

Holidays & nodes do not get deleted

sandreialexandru, 2020-10-16:
Triggering the delete button for holidays and nodes does nothing.

twa127, 2020-10-17:
committed a fix

twa127, 2020-10-17:
The delete node button in settings is working okay for me

Closed 2020-10-21.

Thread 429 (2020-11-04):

ZONE overrun

sandreialexandru, 2020-11-04:
Having a zone valve open for some time, after the boiler stops would be a good idea. This helps with the dissipation of heat and the prevention of pressure building up.
CASE 1:
 If boiler is triggered by zone valve, then boiler overrun is the way to prevent pressure build-up, if the recirculation pump can be managed separately.
CASE 2:
If boiler is triggered by GPIO, then as soon as boiler stops the zone valve closes(triggered by GPIO or Zone Controller), but residual heat will not be dissipated and pressure would build.

pihome-shc, 2020-11-05:
we already have implemented this: boiler stops first and takes reading from boiler table for overrun time and leave zone valve open but if anyone have boiler controlled by zone valve we have no way of offering control over that other then user have separate controller for boiler. or alternately user can disable this and have overrun loop (as i belive all systems have this)

sandreialexandru, 2020-11-05:
Are you saying that if boiler is controlled by GPIO and zones are controlled by Wireless Zone Controllers, the valves remain open after the boiler stops?

pihome-shc, 2020-11-05:
yes, that is the idea and i have my system controlled by gpio and it works

sandreialexandru, 2020-11-05:
Great! I think I missunderstood the code. Sorry for that.

pihome-shc, 2020-11-05:
no worries, if no further actions required can you close this issue

Closed 2020-11-05.

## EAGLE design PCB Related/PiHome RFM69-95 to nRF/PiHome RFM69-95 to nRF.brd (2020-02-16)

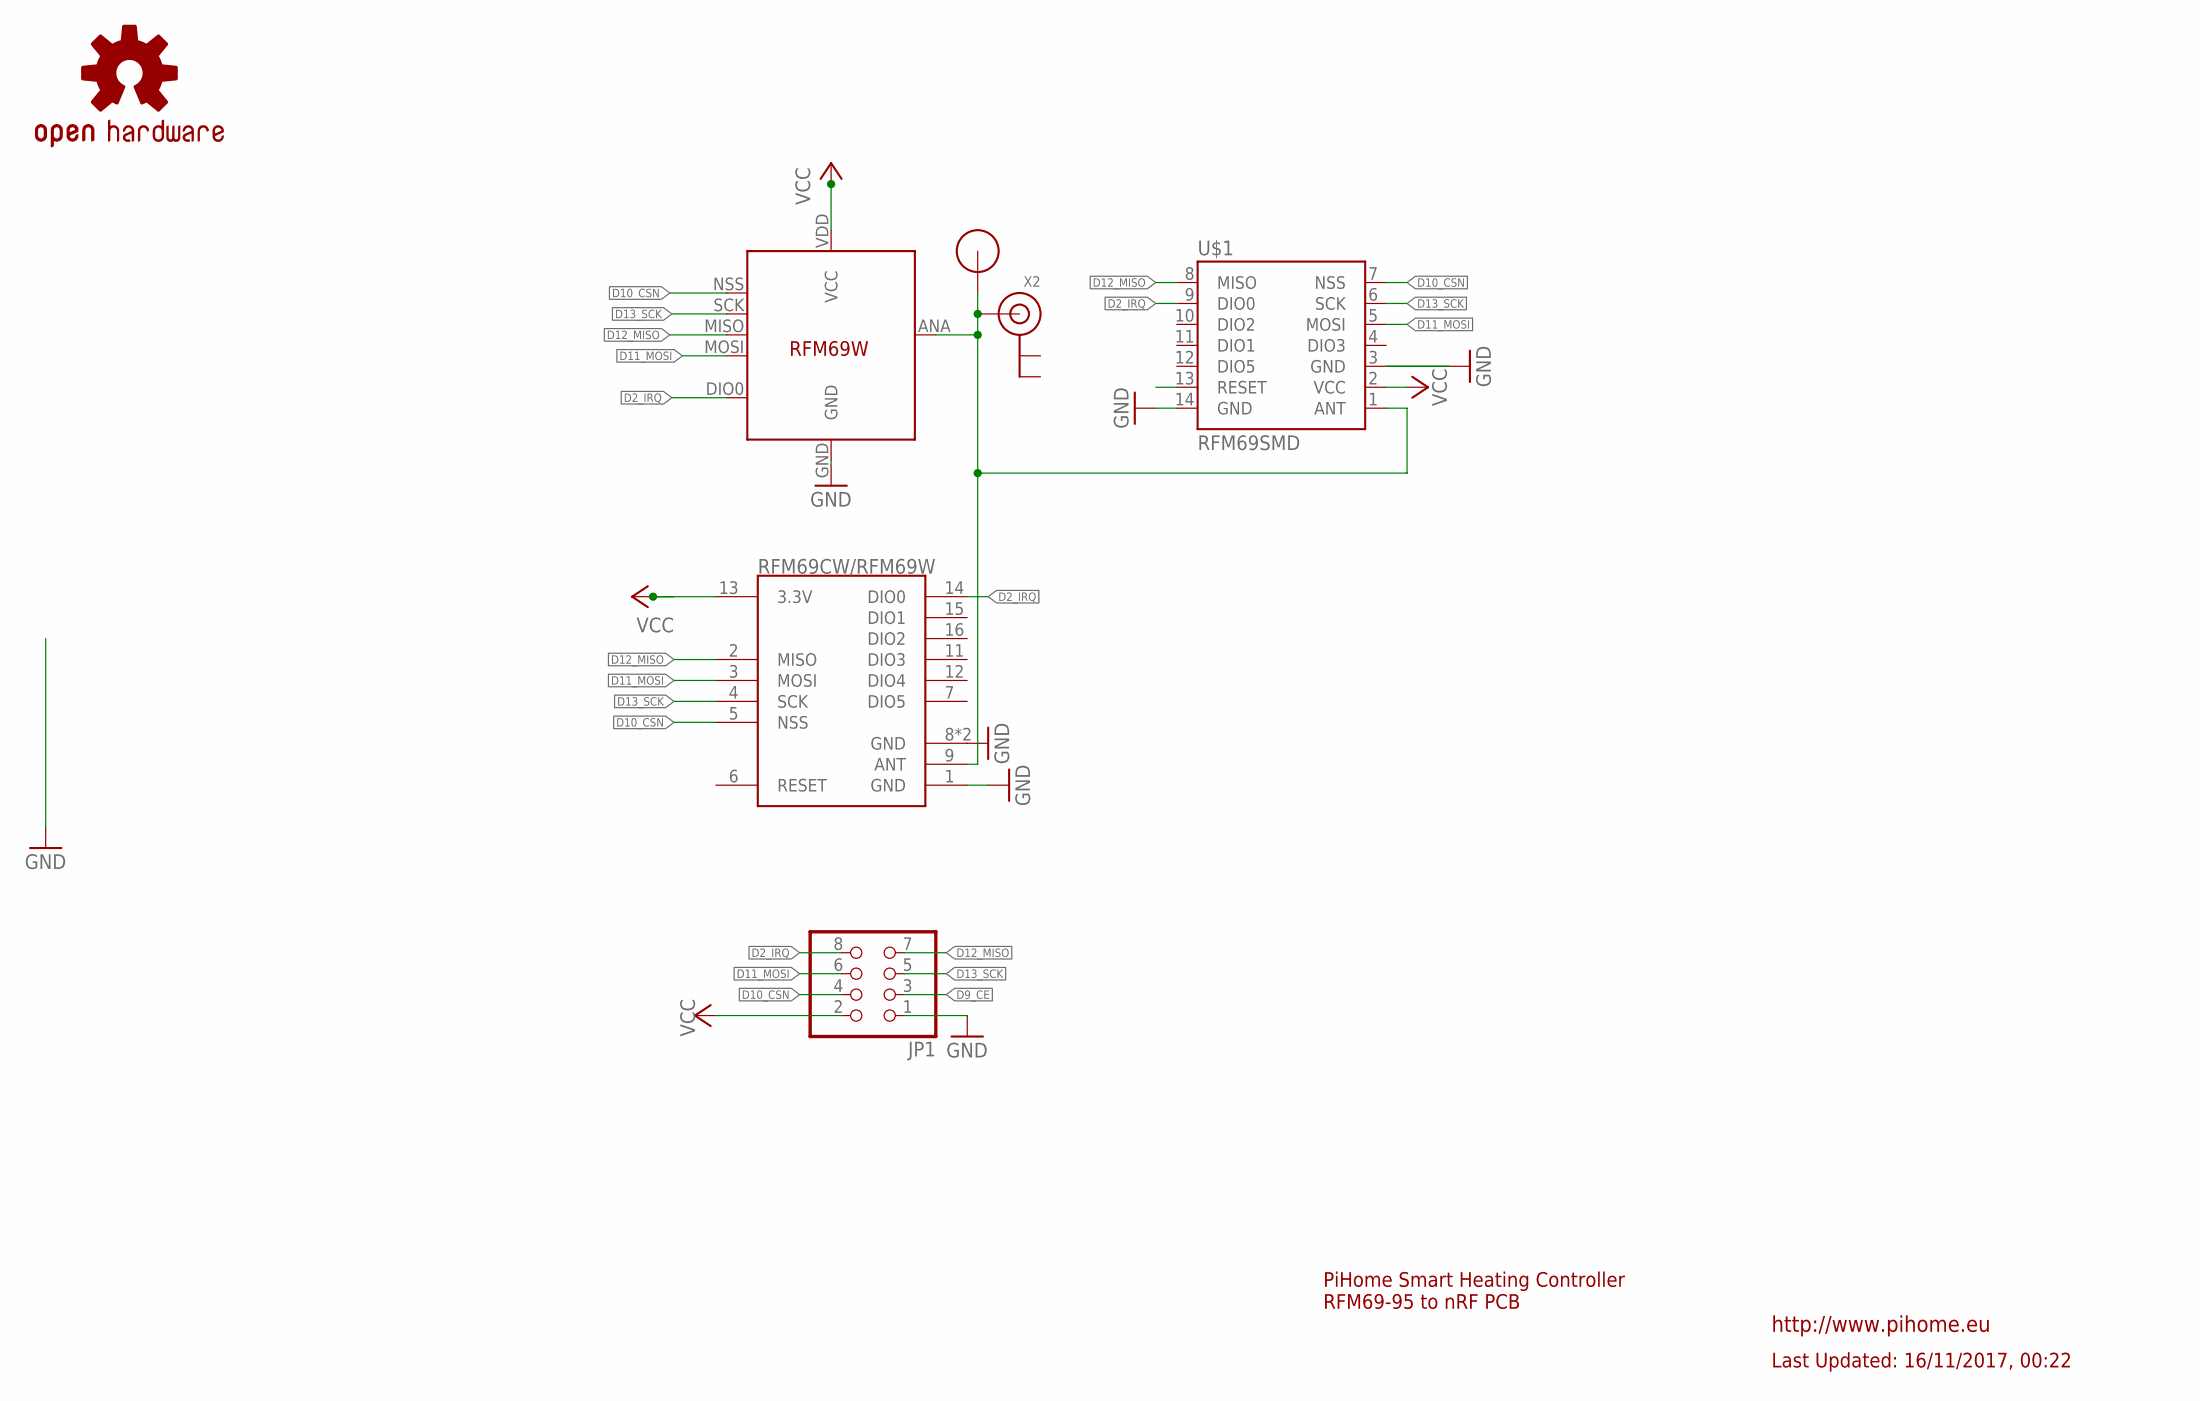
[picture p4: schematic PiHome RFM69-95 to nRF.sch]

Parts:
JP1: PINHD-2X4; 2X04
LOGO2: OSHW-LOGOS; OSHW-LOGO-S
RFM69CW/RFM69W: RFM69HCW; RFM69HCW-XXXS2
RFM69W-433MHZ: RFM69; RFM69W-MINPADS
U$1: RFM69SMD; RFM69
U$6: RFM12B_ANTENNA; RFM12B-ANTENNA
X2: ANTENNA_U.FL; U.FL

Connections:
D2_IRQ: JP1.8, RFM69CW/RFM69W.14 (DIO0), RFM69W-433MHZ.DIO0, U$1.9 (DIO0)
D9_CE: JP1.3
D10_CSN: JP1.4, RFM69CW/RFM69W.5 (NSS), RFM69W-433MHZ.NSS (SEL), U$1.7 (NSS)
D11_MOSI: JP1.6, RFM69CW/RFM69W.3 (MOSI), RFM69W-433MHZ.MOSI, U$1.5 (MOSI)
D12_MISO: JP1.7, RFM69CW/RFM69W.2 (MISO), RFM69W-433MHZ.MISO, U$1.8 (MISO)
D13_SCK: JP1.5, RFM69CW/RFM69W.4 (SCK), RFM69W-433MHZ.SCK, U$1.6 (SCK)
GND: JP1.1, RFM69CW/RFM69W.1 (GND), RFM69CW/RFM69W.8 (GND), RFM69CW/RFM69W.10 (GND), RFM69W-433MHZ.GND, U$1.3 (GND), U$1.14 (GND)
unnamed: RFM69CW/RFM69W.9 (ANT), RFM69W-433MHZ.ANA (ANT), U$1.1 (ANT), U$6.P$1, X2.3 (SIGNAL)
VCC: JP1.2, RFM69CW/RFM69W.13 (3.3V), RFM69W-433MHZ.VDD (VCC), U$1.2 (VCC)

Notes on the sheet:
PiHome Smart Heating Controller RFM69-95 to nRF PCB
Last Updated: 16/11/2017, 00:22
http://www.pihome.eu

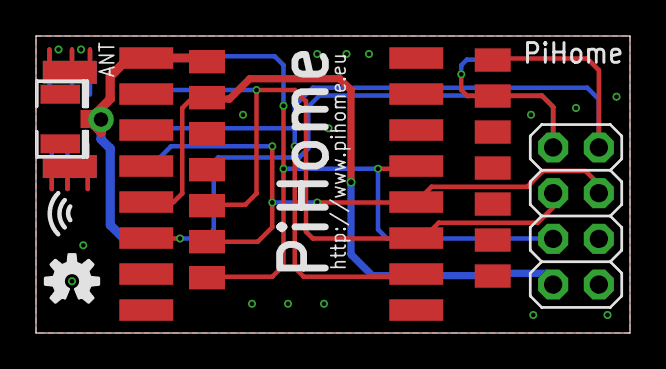
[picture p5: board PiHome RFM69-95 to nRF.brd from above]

Board: 2 copper layers, 33.0 x 16.5 mm, 7 parts (1 on the bottom side), 8 nets.

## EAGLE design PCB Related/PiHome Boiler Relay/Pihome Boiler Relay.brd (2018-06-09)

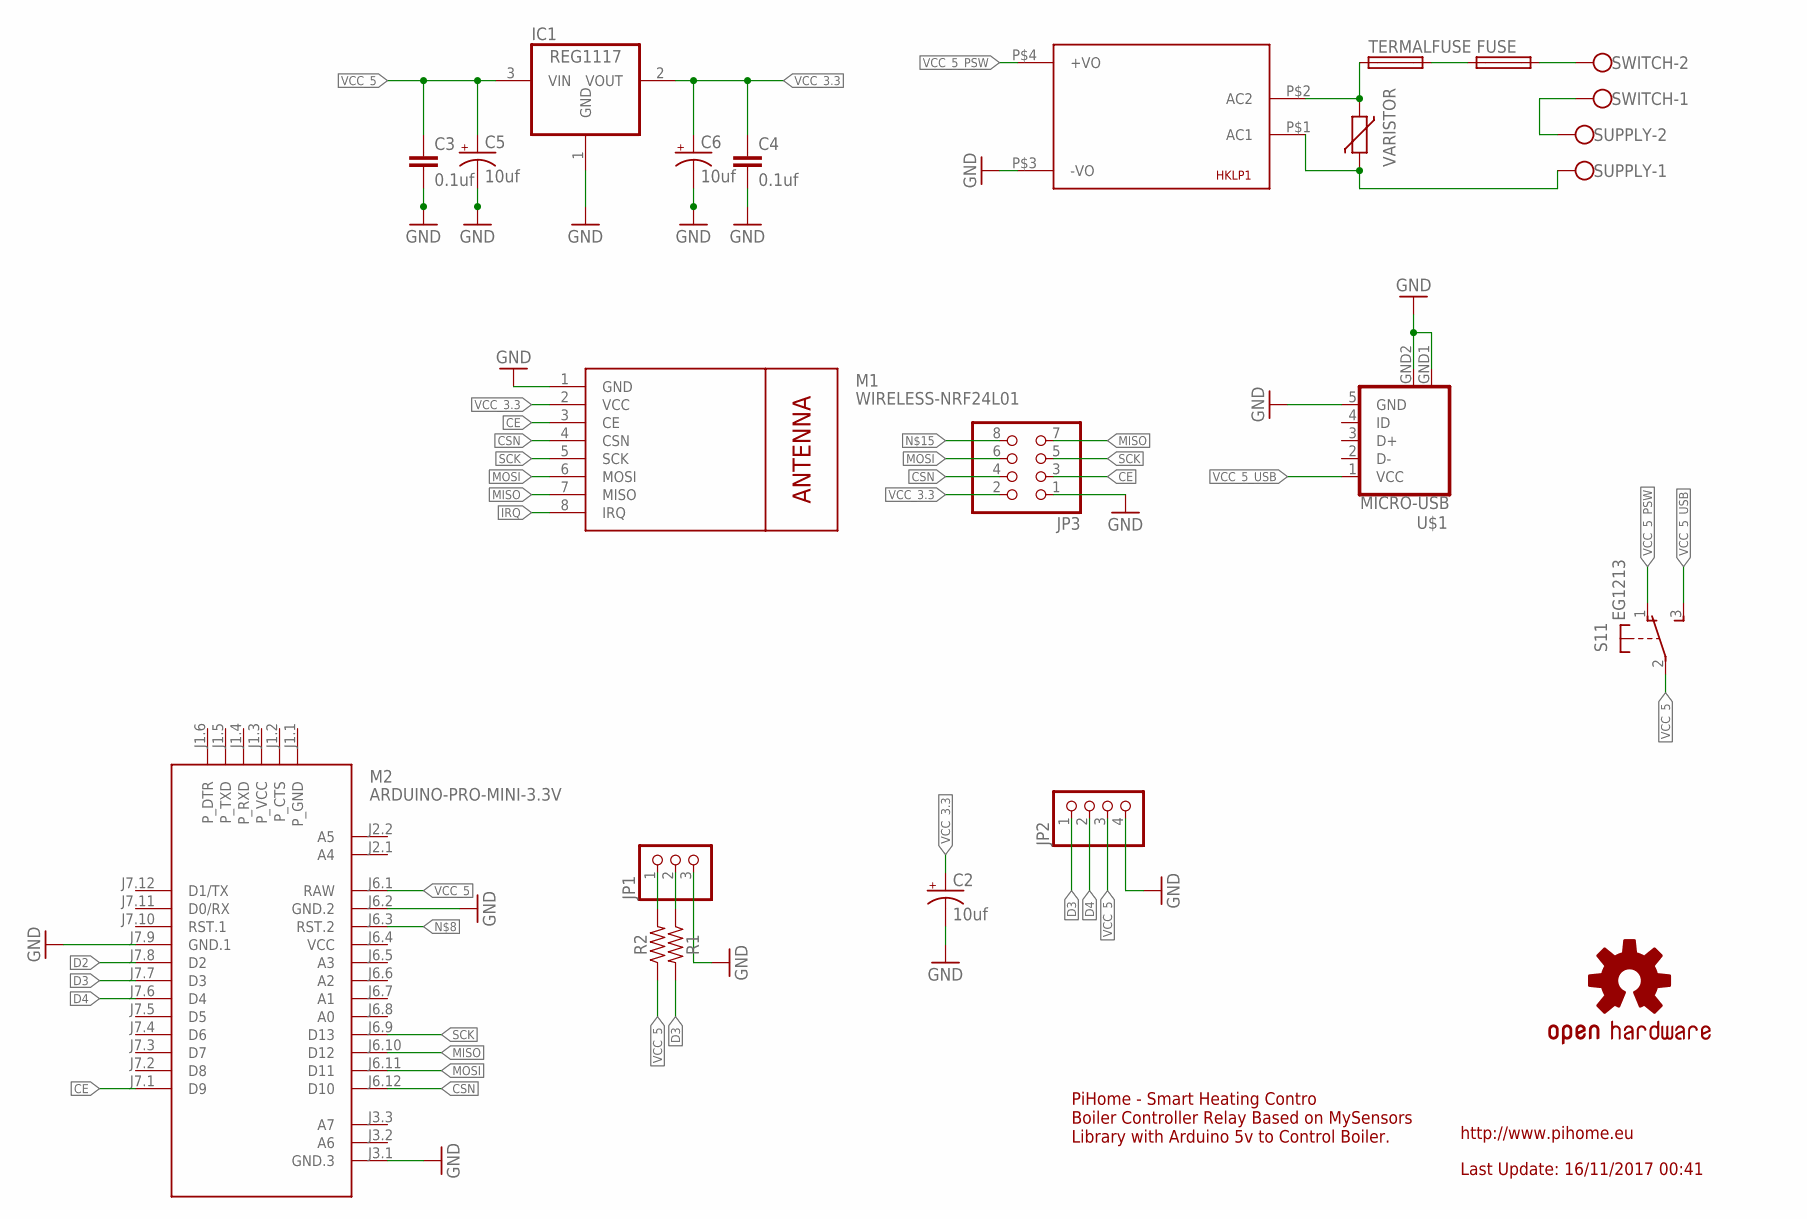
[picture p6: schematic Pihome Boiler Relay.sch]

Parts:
C2, C5, C6: 10uf; CPOL-RADIAL-10UF-25V-KIT
C3, C4: 0.1uf; CAP-PTH-SMALL-KIT
FUSE: TE5
HKLP1: HKLPM01
IC1: REG1117; SOT223
JP1: PINHD-1X3; 1X03
JP2: PINHD-1X4; 1X04
JP3: PINHD-2X4; 2X04
LOGO1: OSHW-LOGOL; OSHW-LOGO-L
M1: WIRELESS-NRF24L01
M2: ARDUINO-PRO-MINI-3.3V; ARDUINO-PRO-MINI
R1, R2: AXIAL-0.3
S1: EG1213
SUPPLY: W237-102
SWITCH: W237-102
TERMALFUSE: TE5
U$1: MICRO-USB
VARISTOR: VARISTOR-7,5; R-7,5

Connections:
CE: JP3.3, M1.3 (CE), M2.J7.1 (D9)
CSN: JP3.4, M1.4 (CSN), M2.J6.12 (D10)
D2: M2.J7.8 (D2)
D3: JP2.1, M2.J7.7 (D3), R1.P$2 (2)
D4: JP2.2, M2.J7.6 (D4)
GND: C2.2 (-), HKLP1.P$3 (-VO), JP1.3, JP2.4, JP3.1, M1.1 (GND), M2.J3.1 (GND.3), M2.J6.2 (GND.2), M2.J7.9 (GND.1), U$1.5 (GND), U$1.GND1 (GND), U$1.GND2 (GND)
GND-: C3.2, C4.2, C5.2 (-), C6.2 (-), IC1.1 (GND)
IRQ: M1.8 (IRQ)
MISO: JP3.7, M1.7 (MISO), M2.J6.10 (D12)
MOSI: JP3.6, M1.6 (MOSI), M2.J6.11 (D11)
unnamed: SUPPLY.2, SWITCH.1
unnamed: FUSE.1, TERMALFUSE.2
unnamed: HKLP1.P$2 (AC2), TERMALFUSE.1, VARISTOR.1
unnamed: HKLP1.P$1 (AC1), SUPPLY.1, VARISTOR.2
unnamed: JP1.2, R1.P$1 (1)
unnamed: JP1.1, R2.P$2 (2)
unnamed: FUSE.2, SWITCH.2
SCK: JP3.5, M1.5 (SCK), M2.J6.9 (D13)
VCC: M2.J6.4 (VCC)
VCC_3.3: C2.1 (+), C4.1, C6.1 (+), IC1.2 (VOUT), JP3.2, M1.2 (VCC)
VCC_5: C3.1, C5.1 (+), IC1.3 (VIN), JP2.3, M2.J6.1 (RAW), R2.P$1 (1), S1.2
VCC_5_PSW: HKLP1.P$4 (+VO), S1.1 (O)
VCC_5_USB: S1.3 (S), U$1.1 (VCC)

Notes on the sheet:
Last Update: 16/11/2017 00:41
http://www.pihome.eu
PiHome - Smart Heating Contro Boiler Controller Relay Based on MySensors Library with Arduino 5v to Control Boiler.

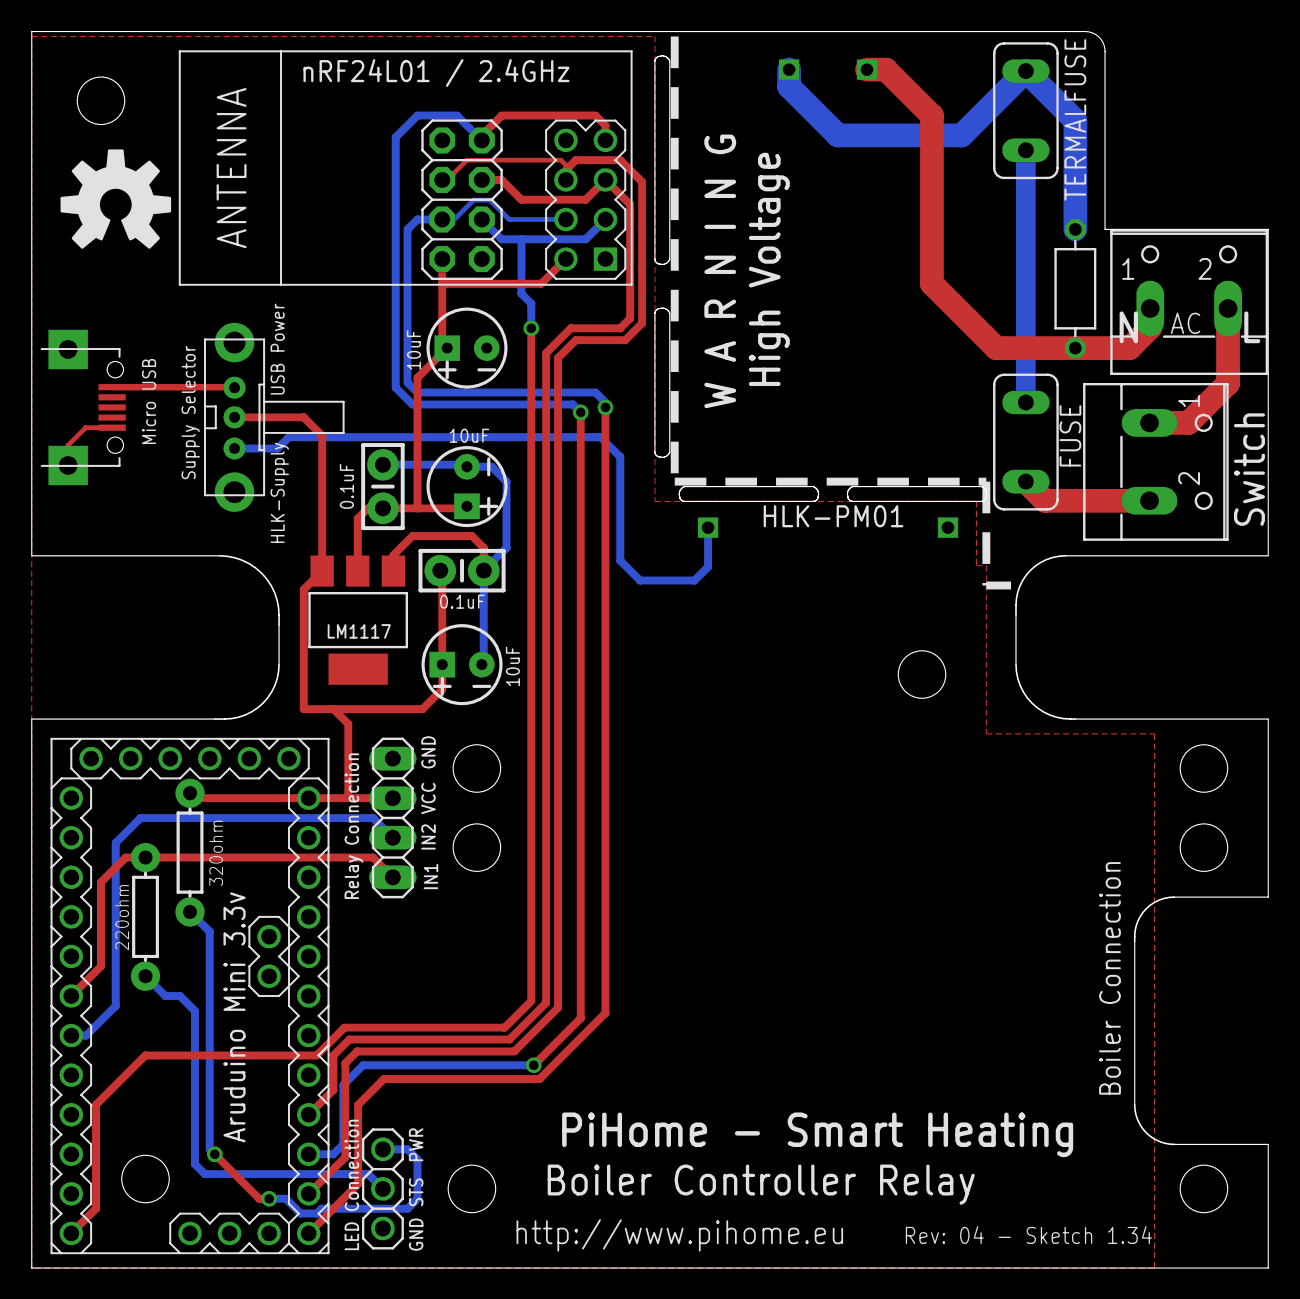
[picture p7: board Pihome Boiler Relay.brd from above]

Board: 2 copper layers, 79.4 x 79.4 mm, 22 parts (0 on the bottom side), 20 nets.

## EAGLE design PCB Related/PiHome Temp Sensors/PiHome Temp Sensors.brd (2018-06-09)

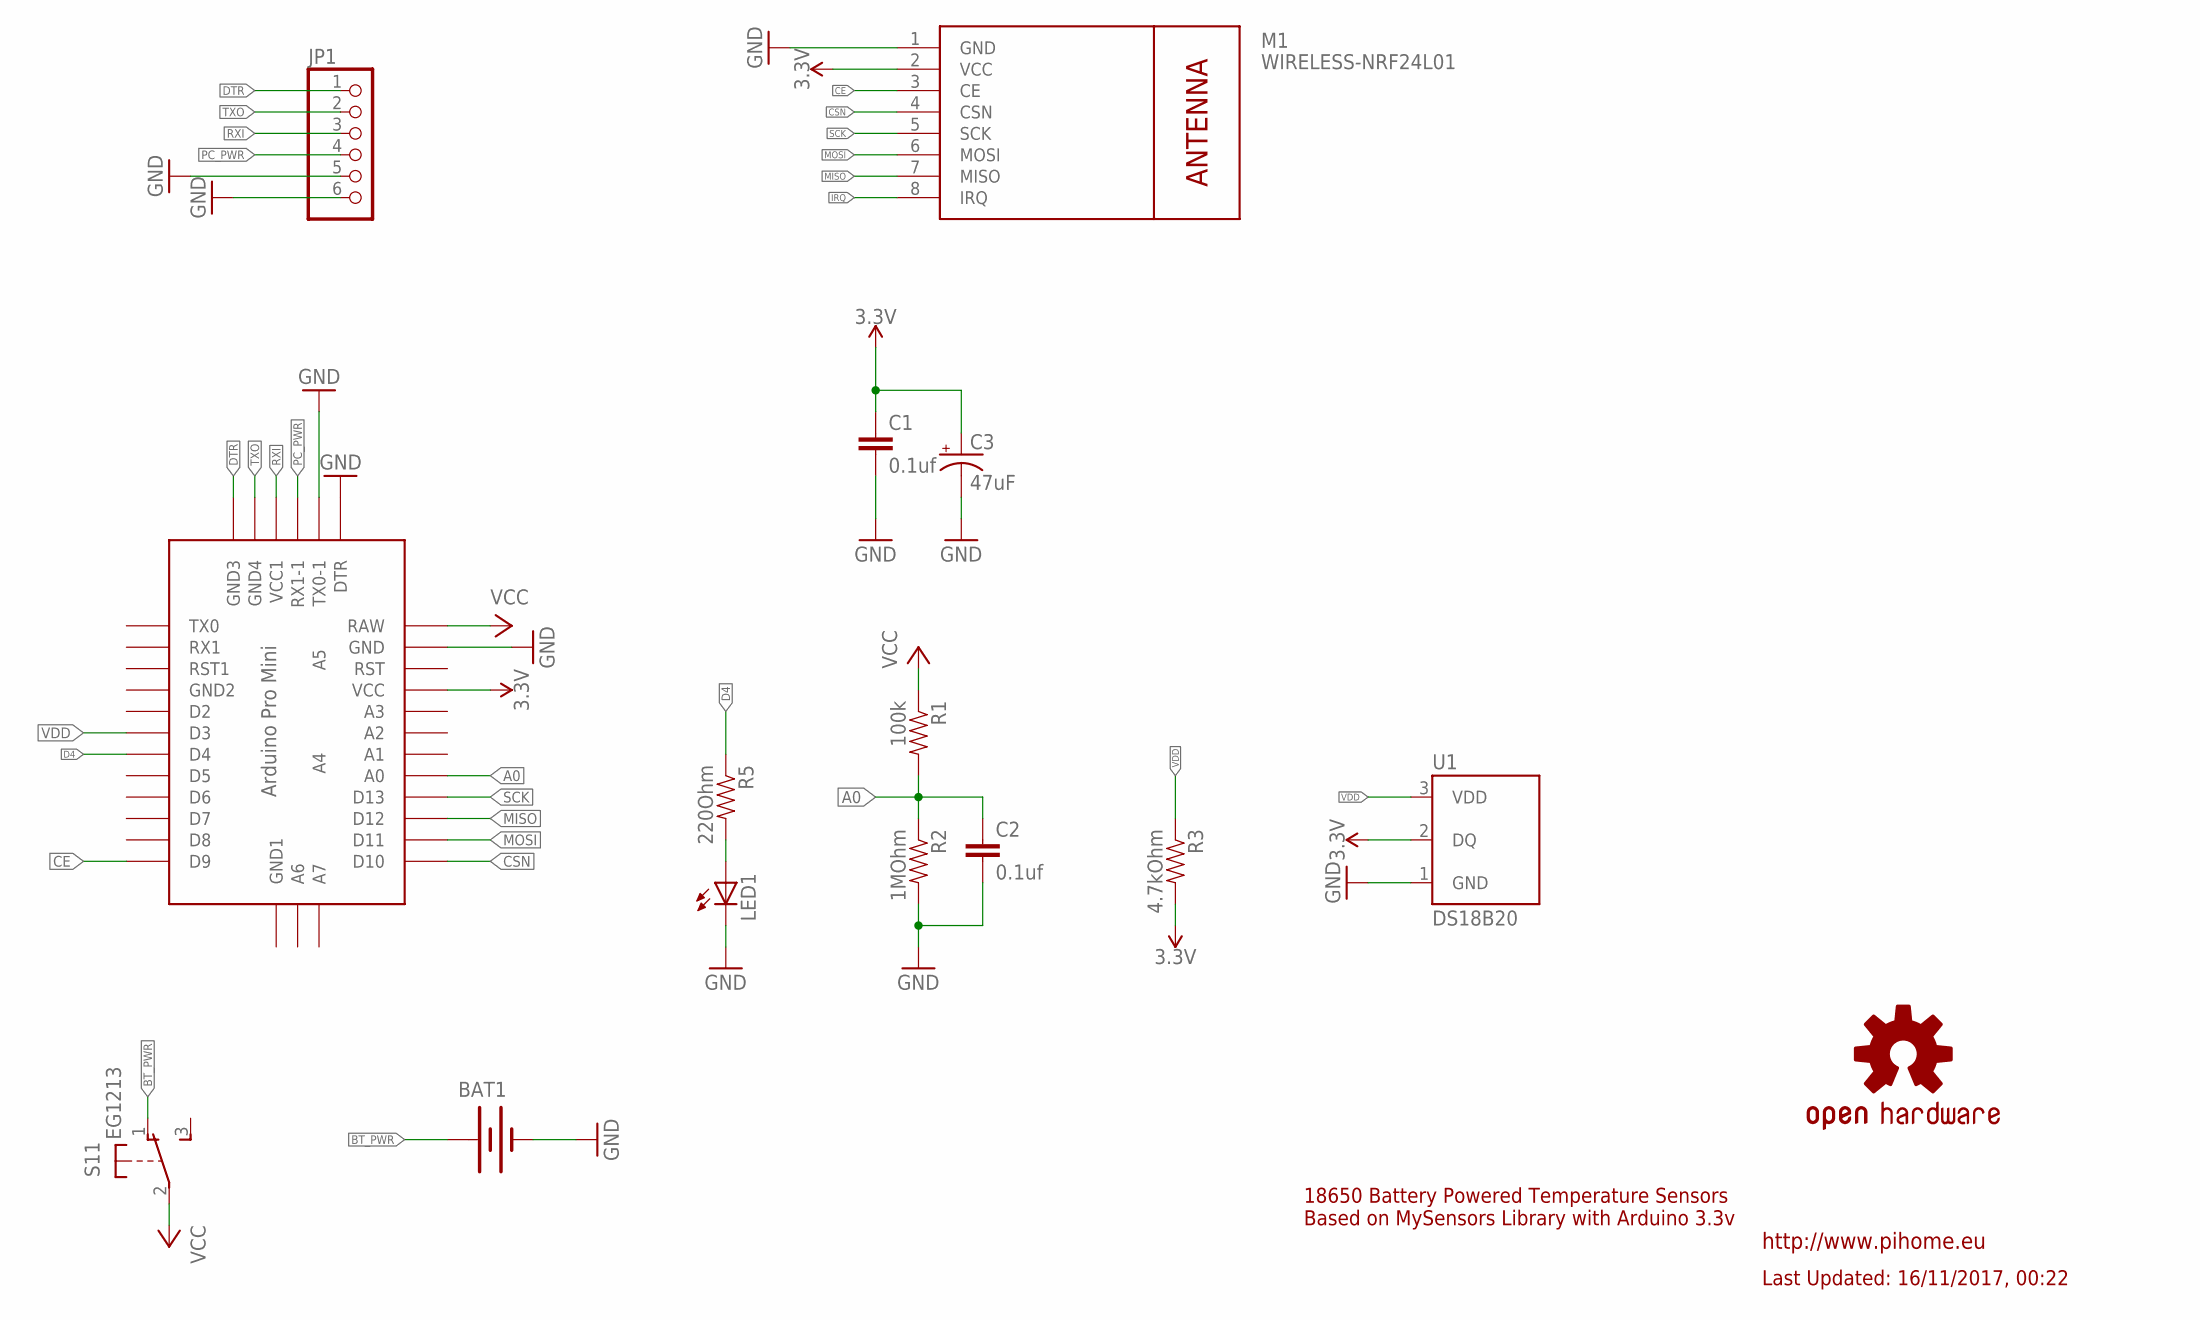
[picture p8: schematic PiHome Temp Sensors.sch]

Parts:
BAT1: BATTERY18650; BATTERY_18650-HOLDER
C1, C2: 0.1uf; CAP-PTH-SMALL-KIT
C3: 47uF; CPOL-RADIAL-10UF-25V-KIT
JP1: PINHD-1X6; 1X06
LED1: LED3MM
LOGO1: OSHW-LOGOL; OSHW-LOGO-L
M1: WIRELESS-NRF24L01
R1: 100k; AXIAL-0.3
R2: 1MOhm; AXIAL-0.3
R3: 4.7kOhm; AXIAL-0.3
R5: 220Ohm; AXIAL-0.3
S1: EG1213
U1: DS18B20; TO-92-AMMO
U$1: ABK-PRO-MINI

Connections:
3.3V: C1.1, C3.1 (+), M1.2 (VCC), R3.P$2 (2), U1.2 (DQ), U$1.VCC
A0: C2.1, R1.P$2 (2), R2.P$1 (1), U$1.A0
BT_PWR: BAT1.PWR@1 (+), S1.1 (O)
CE: M1.3 (CE), U$1.D9
CSN: M1.4 (CSN), U$1.D10
D4: R5.P$1 (1), U$1.D4
DTR: JP1.1, U$1.GND2 (GND3)
GND: BAT1.GND@1 (-), C1.2, C2.2, C3.2 (-), JP1.5, JP1.6, LED1.K (C), M1.1 (GND), R2.P$2 (2), U1.1 (GND), U$1.DTR, U$1.GND, U$1.TX0-1
IRQ: M1.8 (IRQ)
MISO: M1.7 (MISO), U$1.D12
MOSI: M1.6 (MOSI), U$1.D11
unnamed: LED1.A, R5.P$2 (2)
PC_PWR: JP1.4, U$1.RX1-1
RXI: JP1.3, U$1.VCC1
SCK: M1.5 (SCK), U$1.D13
TXO: JP1.2, U$1.GND3 (GND4)
VCC: R1.P$1 (1), S1.2, U$1.RAW
VDD: R3.P$1 (1), U1.3 (VDD), U$1.D3

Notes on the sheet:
18650 Battery Powered Temperature Sensors Based on MySensors Library with Arduino 3.3v
Last Updated: 16/11/2017, 00:22
http://www.pihome.eu

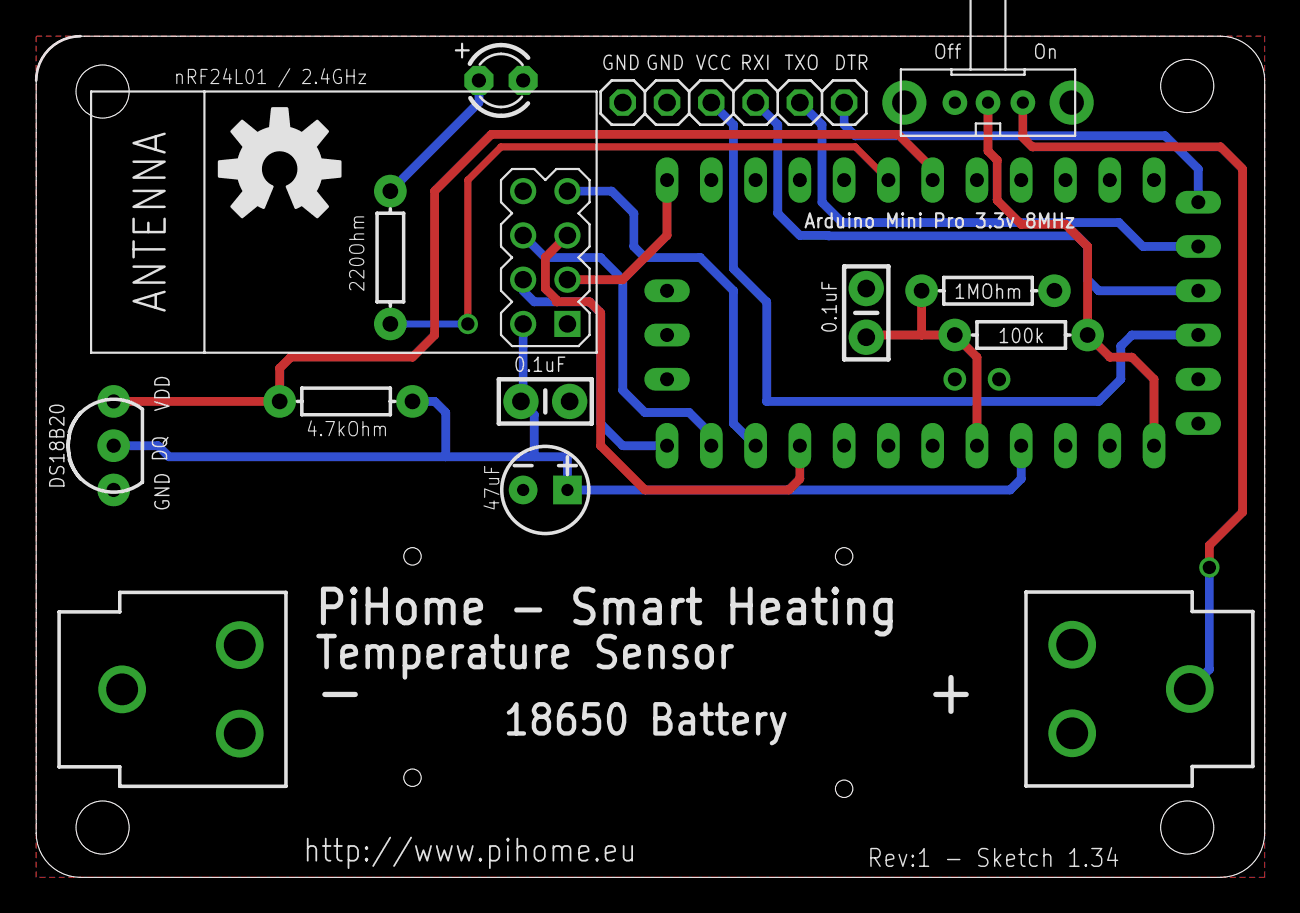
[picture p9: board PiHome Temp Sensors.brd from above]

Board: 2 copper layers, 70.5 x 48.3 mm, 15 parts (0 on the bottom side), 17 nets.

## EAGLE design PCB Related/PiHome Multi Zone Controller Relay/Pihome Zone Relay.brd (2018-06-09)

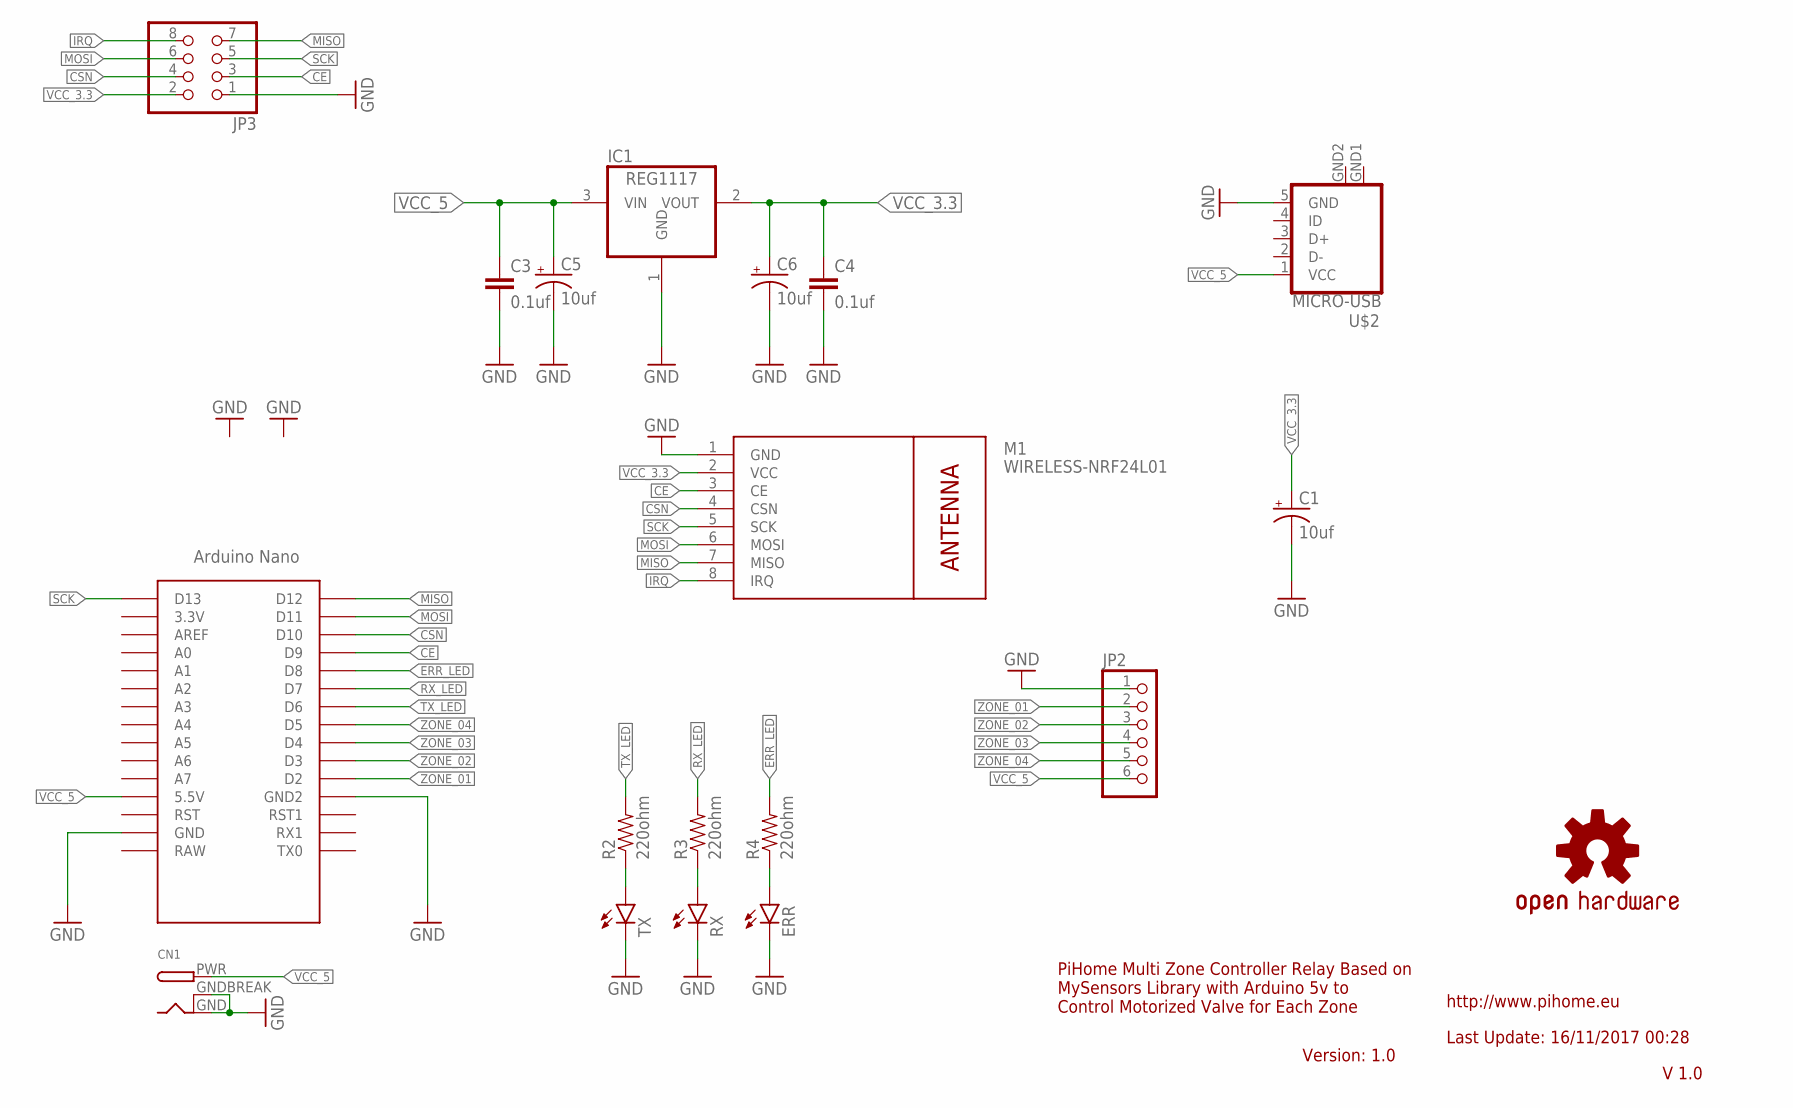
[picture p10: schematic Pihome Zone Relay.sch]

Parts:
C1, C5, C6: 10uf; CPOL-RADIAL-10UF-25V-KIT
C3, C4: 0.1uf; CAP-PTH-SMALL-KIT
CN1: DCBARRELPTH; DCJACK_2MM_PTH
ERR: LED3MM
IC1: REG1117; SOT223
JP2: PINHD-1X6; 1X06
JP3: PINHD-2X4; 2X04
LOGO4: OSHW-LOGOM; OSHW-LOGO-M
M1: WIRELESS-NRF24L01
R2, R3, R4: 220ohm; AXIAL-0.3
RX: LED3MM
TX: LED3MM
U$1: NANO
U$2: MICRO-USB

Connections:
CE: JP3.3, M1.3 (CE), U$1.D9
CSN: JP3.4, M1.4 (CSN), U$1.D10
ERR_LED: R4.P$2 (2), U$1.D8
GND: C1.2 (-), C3.2, C4.2, C5.2 (-), C6.2 (-), CN1.GND, CN1.GNDBREAK, ERR.K (C), IC1.1 (GND), JP2.1, JP3.1, M1.1 (GND), RX.K (C), TX.K (C), U$1.GND, U$1.GND1 (GND2), U$2.5 (GND), U$2.GND1 (GND), U$2.GND2 (GND)
IRQ: JP3.8, M1.8 (IRQ)
MISO: JP3.7, M1.7 (MISO), U$1.D12
MOSI: JP3.6, M1.6 (MOSI), U$1.D11
unnamed: R2.P$1 (1), TX.A
unnamed: R3.P$1 (1), RX.A
unnamed: ERR.A, R4.P$1 (1)
RX_LED: R3.P$2 (2), U$1.D7
SCK: JP3.5, M1.5 (SCK), U$1.D13
TX_LED: R2.P$2 (2), U$1.D6
VCC_3.3: C1.1 (+), C4.1, C6.1 (+), IC1.2 (VOUT), JP3.2, M1.2 (VCC)
VCC_5: C3.1, C5.1 (+), CN1.PWR, IC1.3 (VIN), JP2.6, U$1.5V (5.5V), U$2.1 (VCC)
ZONE_01: JP2.2, U$1.D2
ZONE_02: JP2.3, U$1.D3
ZONE_03: JP2.4, U$1.D4
ZONE_04: JP2.5, U$1.D5

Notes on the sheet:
http://www.pihome.eu
Last Update: 16/11/2017 00:28
PiHome Multi Zone Controller Relay Based on MySensors Library with Arduino 5v to Control Motorized Valve for Each Zone
Version: 1.0
V 1.0

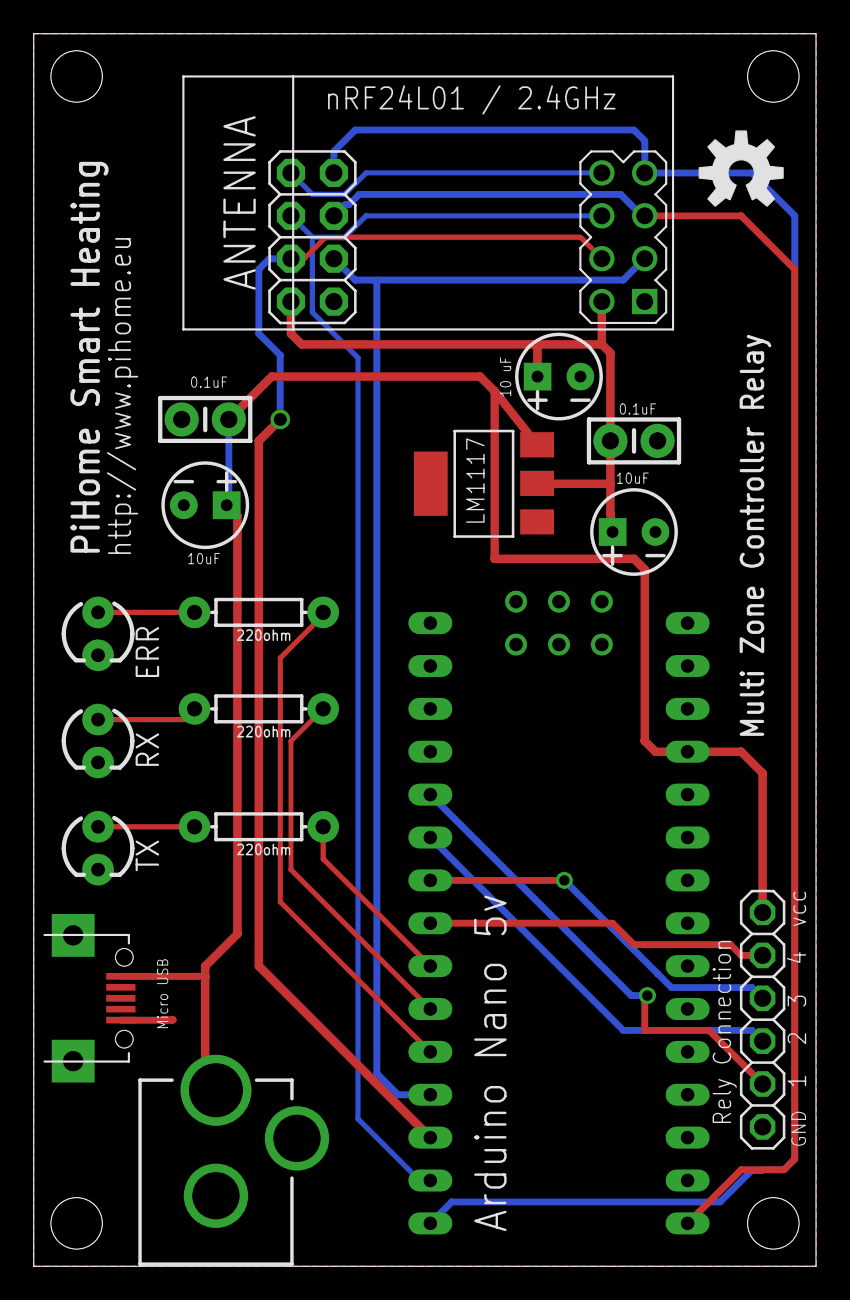
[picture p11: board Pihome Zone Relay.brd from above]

Board: 2 copper layers, 46.3 x 73.0 mm, 19 parts (0 on the bottom side), 19 nets.

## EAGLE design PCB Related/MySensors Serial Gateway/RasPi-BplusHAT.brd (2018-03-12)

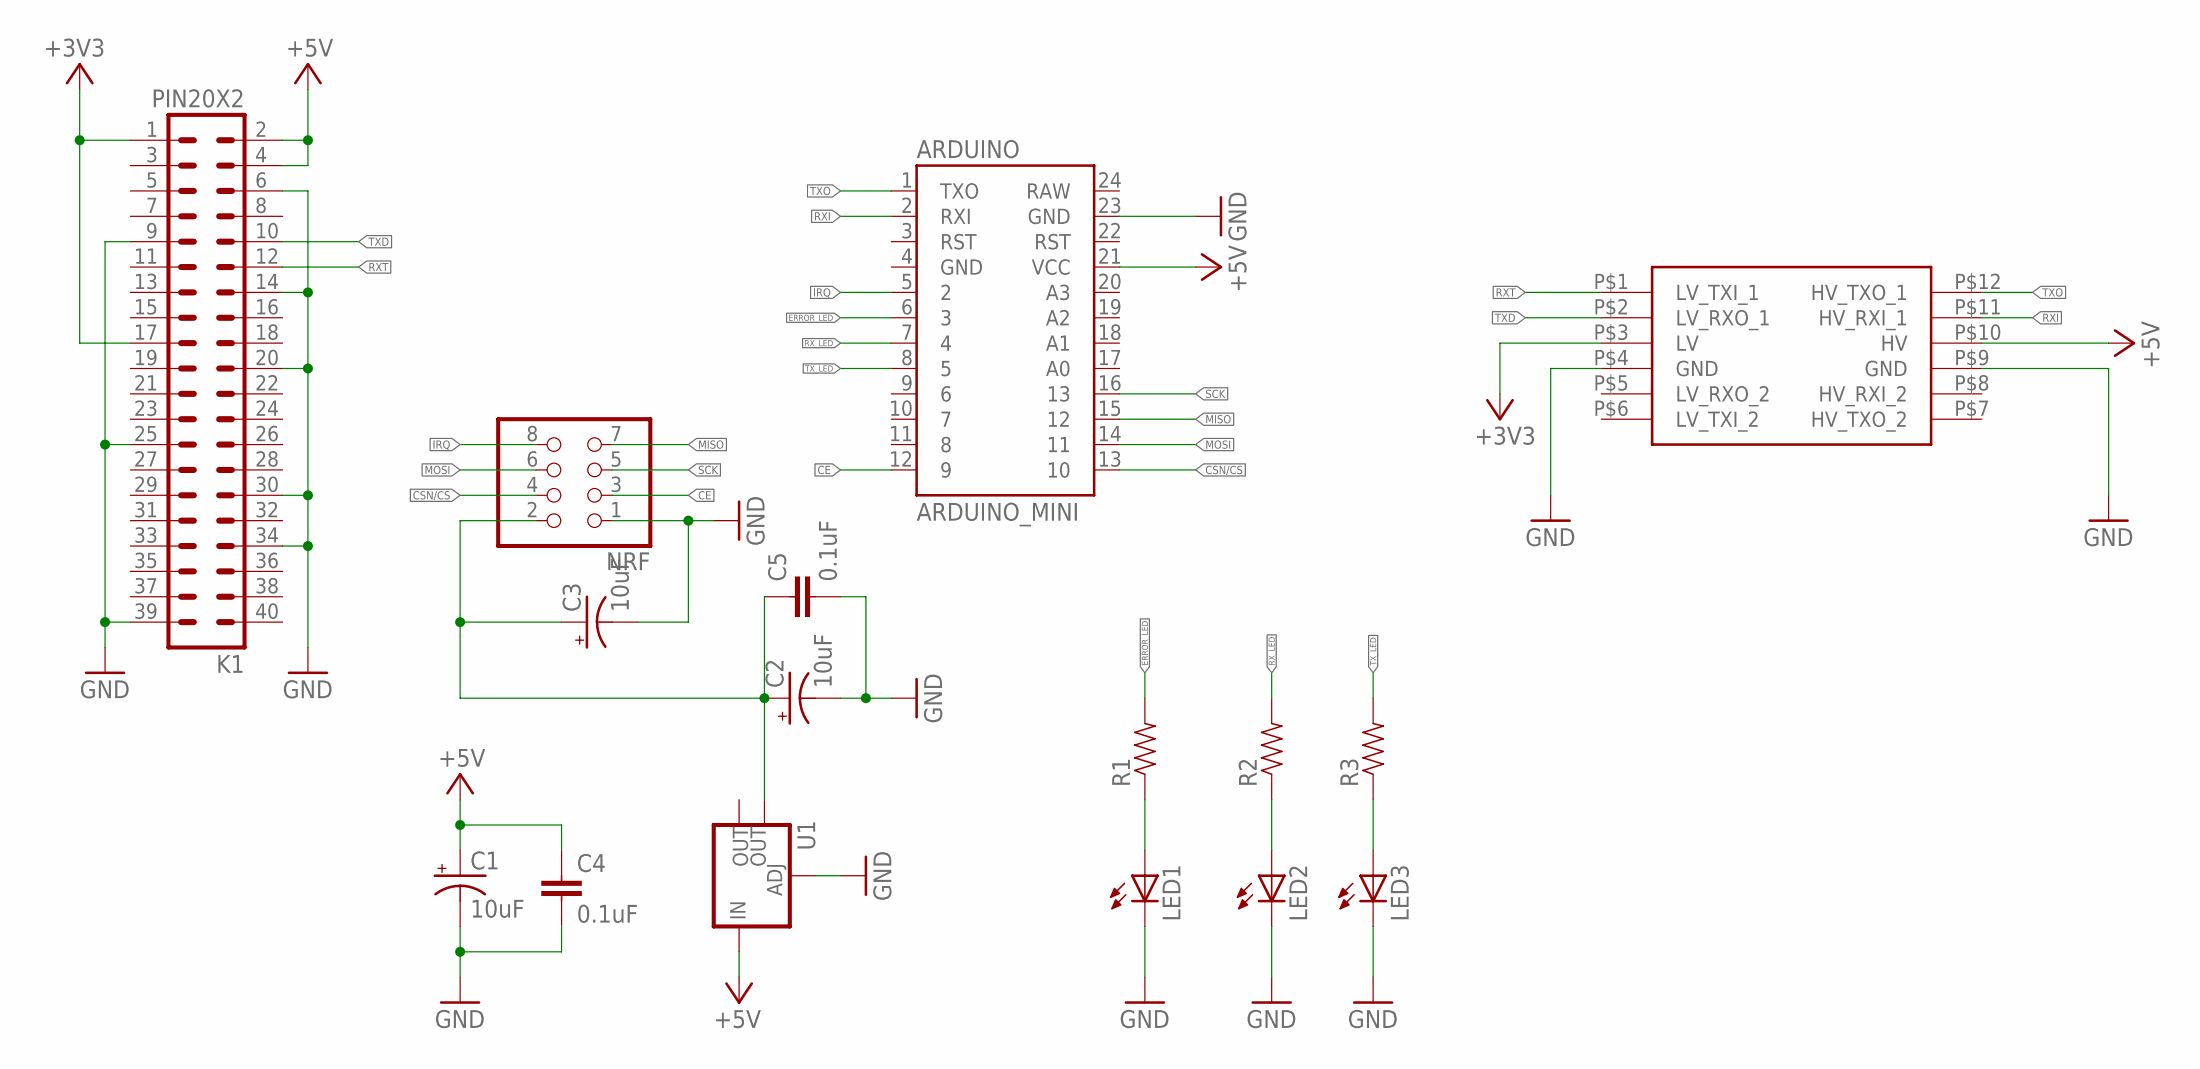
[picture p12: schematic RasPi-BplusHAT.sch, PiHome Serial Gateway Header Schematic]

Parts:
ARDUINO: ARDUINO_MINI
C1, C2, C3: 10uF; CPOL-RADIAL-10UF-25V
C4, C5: 0.1uF; CAP-PTH-SMALL
K1: PIN20X2; PIN_20X2
LED1, LED2, LED3: LED3MM
NRF: PINHD-2X4; 2X04
R1, R2, R3: RESISTORPTH-1/4W; AXIAL-0.4
U1: V_REG_LM1117SOT223; SOT223
U$2: LOGIC_LEVEL_CONVERTER

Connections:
+3V3: K1.1, K1.17, U$2.P$3 (LV)
+5V: ARDUINO.21 (VCC), C1.1 (+), C4.1, K1.2, K1.4, U1.3 (IN), U$2.P$10 (HV)
CE: ARDUINO.12 (9), NRF.3
CSN/CS: ARDUINO.13 (10), NRF.4
ERROR_LED: ARDUINO.6 (3), R1.P$2 (2)
GND: ARDUINO.23 (GND), C1.2 (-), C2.2 (-), C3.2 (-), C4.2, C5.2, K1.6, K1.9, K1.14, K1.20, K1.25, K1.30, K1.34, K1.39, LED1.K (C), LED2.K (C), LED3.K (C), NRF.1, U1.1 (ADJ), U$2.P$4 (GND), U$2.P$9 (GND)
IRQ: ARDUINO.5 (2), NRF.8
MISO: ARDUINO.15 (12), NRF.7
MOSI: ARDUINO.14 (11), NRF.6
unnamed: C2.1 (+), C3.1 (+), C5.1, NRF.2, U1.4 (OUT)
unnamed: LED1.A, R1.P$1 (1)
unnamed: LED2.A, R2.P$1 (1)
unnamed: LED3.A, R3.P$1 (1)
RXI: ARDUINO.2 (RXI), U$2.P$11 (HV_RXI_1)
RXT: K1.12, U$2.P$1 (LV_TXI_1)
RX_LED: ARDUINO.7 (4), R2.P$2 (2)
SCK: ARDUINO.16 (13), NRF.5
TXD: K1.10, U$2.P$2 (LV_RXO_1)
TXO: ARDUINO.1 (TXO), U$2.P$12 (HV_TXO_1)
TX_LED: ARDUINO.8 (5), R3.P$2 (2)

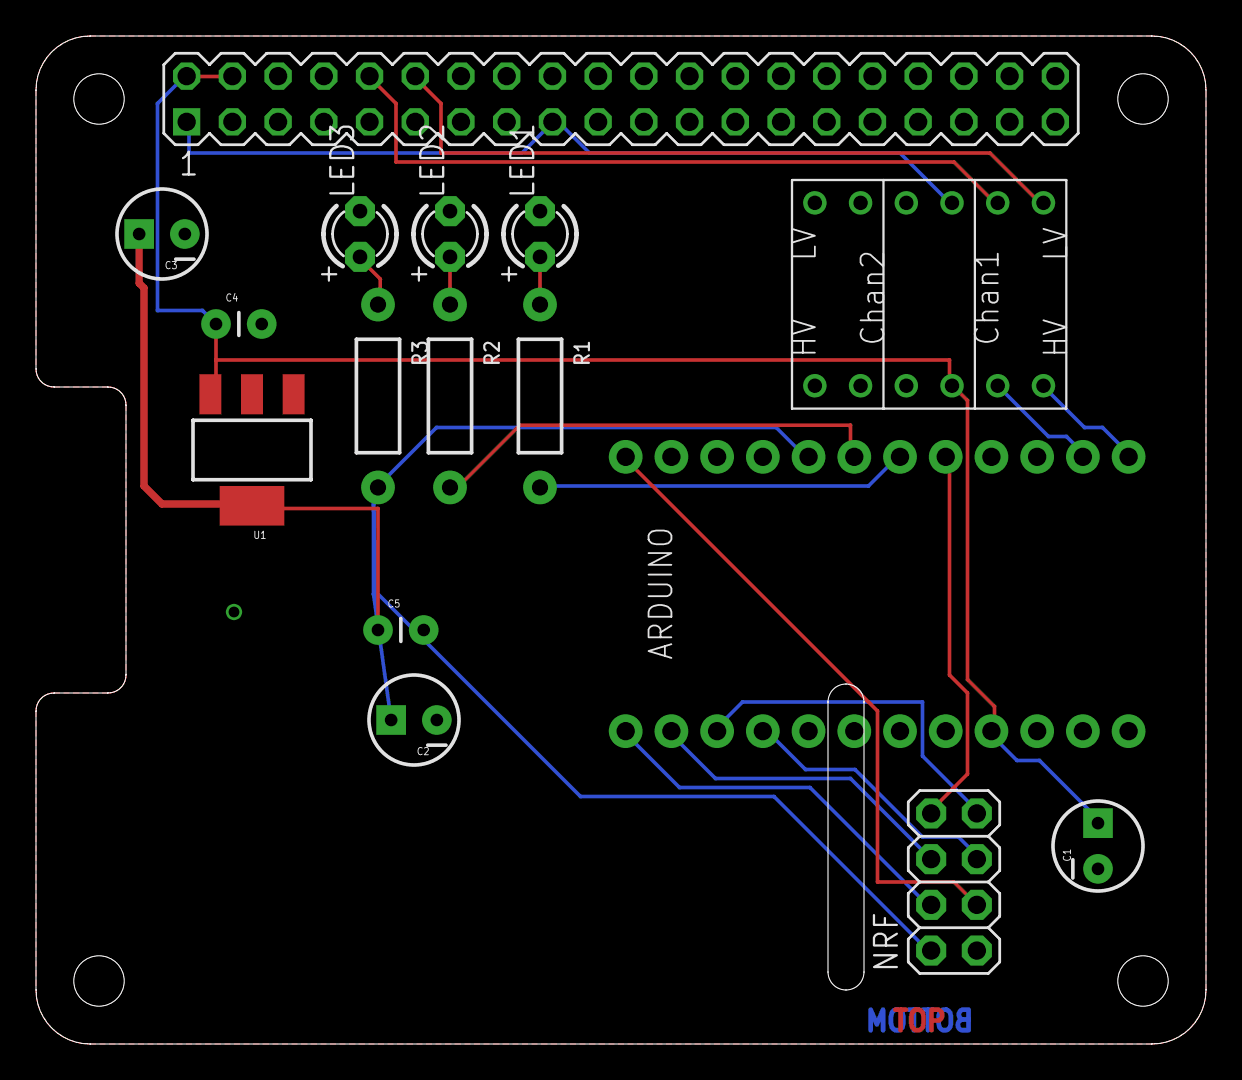
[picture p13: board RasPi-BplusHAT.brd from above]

Board: 2 copper layers, 65.0 x 56.0 mm, 16 parts (0 on the bottom side), 20 nets.

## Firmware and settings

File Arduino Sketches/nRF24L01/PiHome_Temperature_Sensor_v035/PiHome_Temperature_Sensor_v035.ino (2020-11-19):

//  _____    _   _    _                             
// |  __ \  (_) | |  | |                           
// | |__) |  _  | |__| |   ___    _ __ ___     ___ 
// |  ___/  | | |  __  |  / _ \  | |_  \_ \   / _ \ 
// | |      | | | |  | | | (_) | | | | | | | |  __/
// |_|      |_| |_|  |_|  \___/  |_| |_| |_|  \___|
//
//    S M A R T   H E A T I N G   C O N T R O L 
// *****************************************************************
// *       Battery Powered OneWire DS18B20 Temperature Sensor      *
// *           Version 0.35 Build Date 06/11/2017                  *
// *            Last Modification Date 28/06/2020                  *
// *                                          Have Fun - PiHome.eu *
// *****************************************************************

// Enable debug prints to serial monitor
//#define MY_DEBUG

//Set MY_SPLASH_SCREEN_DISABLED to disable MySensors splash screen. (This saves 120 bytes of flash)
#define MY_SPLASH_SCREEN_DISABLED

//Define Sketch Name 
#define SKETCH_NAME "Temperature Sensor"
//Define Sketch Version 
#define SKETCH_VERSION "0.35"

// Enable and select radio type attached
#define MY_RADIO_RF24
//#define MY_RADIO_NRF5_ESB
//#define MY_RADIO_RFM69
//#define MY_RADIO_RFM95

//IRQ Pin on Arduino
#define MY_RF24_IRQ_PIN 2

//Enable OTA 
//#define MY_OTA_FIRMWARE_FEATURE

// * - RF24_PA_MIN = -18dBm
// * - RF24_PA_LOW = -12dBm
// * - RF24_PA_HIGH = -6dBm
// * - RF24_PA_MAX = 0dBm
// Set LOW transmit power level as default, if you have an amplified NRF-module and
// power your radio separately with a good regulator you can turn up PA level.
// RF24_PA_MIN RF24_PA_LOW RF24_PA_HIGH RF24_PA_MAX RF24_PA_ERROR
#define MY_RF24_PA_LEVEL RF24_PA_MIN
//#define MY_DEBUG_VERBOSE_RF24

/**
 * @brief RF channel for the sensor net, 0-125.
 * Frequencies: 2400 Mhz - 2525 Mhz
 * @see https://www.nordicsemi.com/eng/nordic/download_resource/8765/2/42877161/2726
 * - 0 => 2400 Mhz (RF24 channel 1)
 * - 1 => 2401 Mhz (RF24 channel 2)
 * - 76 => 2476 Mhz (RF24 channel 77)
 * - 83 => 2483 Mhz (RF24 channel 84)
 * - 124 => 2524 Mhz (RF24 channel 125)
 * - 125 => 2525 Mhz (RF24 channel 126)
 * In some countries there might be limitations, in Germany for example only the range
 * 2400,0 - 2483,5 Mhz is allowed.
 * @see http://www.bundesnetzagentur.de/SharedDocs/Downloads/DE/Sachgebiete/Telekommunikation/Unternehmen_Institutionen/Frequenzen/Allgemeinzuteilungen/2013_10_WLAN_2,4GHz_pdf.pdf
 */
 
//Default RF channel Default is 76
#define MY_RF24_CHANNEL  91

//PiHome - Make Sure you change Node ID, for each temperature sensor. 21 for Ground Floor, 20 for First Floor, 30 for Domastic Hot Water.
#define MY_NODE_ID 20

//RF24_250KBPS for 250kbs, RF24_1MBPS for 1Mbps, or RF24_2MBPS for 2Mbps
#define MY_RF24_DATARATE RF24_250KBPS

//Enable Signing 
//#define MY_SIGNING_SIMPLE_PASSWD "pihome"

//Enable Encryption This uses less memory, and hides the actual data.
//#define MY_ENCRYPTION_SIMPLE_PASSWD "pihome"

// Set baud rate to same as optibot
//#define MY_BAUD_RATE 9600

//set how long to wait for transport ready in milliseconds
//#define MY_TRANSPORT_WAIT_READY_MS 3000

#include <MySensors.h>  
#include <DallasTemperature.h>
#include <OneWire.h>

#define ledpin 4      // LED for one Blink Power On, second blink for temperature sensors after successfull radio contact with gateway and three blinks for low battery 

// Define sensor node childs
#define CHILD_ID_BATT 1
#define CHILD_ID_TEMP 0

#define COMPARE_TEMP 1 // Send temperature only if changed? 1 = Yes 0 = No, > 1 - force send if it value not sent that number of times and value is valid (keep lower than notice interval)
#define COMPARE_BVOLT 0 // Send battery voltage only if changed? 1 = Yes 0 = No, > 1 - force send if it value not sent that number of times
#define ONE_WIRE_BUS 3 // Pin where dallase sensor is connected 

#define MAX_ATTACHED_DS18B20 1
unsigned long SLEEP_TIME = 56000; // Sleep time between reads (in milliseconds)

int batteryNotSentCount=0;
int temperatureNotSentCount[MAX_ATTACHED_DS18B20];

// Battery related init
int BATTERY_SENSE_PIN = A0;  // select the input pin for the battery sense point
float oldBatteryV = 0;
MyMessage msgBatt(CHILD_ID_BATT, V_VOLTAGE);
#define MIN_VALUE 80 // threshold battery level to trigger notifications
MyMessage msgBattLevel(CHILD_ID_BATT, V_VAR1);

// Dallas Temperature related init
#define TEMPERATURE_PRECISION 12 // Temperature resolution
OneWire oneWire(ONE_WIRE_BUS); // Setup a oneWire instance to communicate with any OneWire devices (not just Maxim/Dallas temperature ICs)
DallasTemperature sensors(&oneWire); // Pass the oneWire reference to Dallas Temperature. 
float lastTemperature[MAX_ATTACHED_DS18B20];
int numSensors=0;
bool receivedConfig = false;
bool metric = true;
// Initialize temperature message
MyMessage msg(CHILD_ID_TEMP, V_TEMP);

void before(){
  // Startup up the OneWire library
  sensors.begin();
}

void setup(){
  //This is LED pin set to output and turn it on for short while 
  pinMode(ledpin, OUTPUT);
  digitalWrite(ledpin, HIGH);
  delay(60);
  digitalWrite(ledpin, LOW);
  // requestTemperatures() will not block current thread
  sensors.setWaitForConversion(false);
  sensors.setResolution(TEMPERATURE_PRECISION);
  // needed for battery soc
  // use the 1.1 V internal reference
  #if defined(__AVR_ATmega2560__)
    analogReference(INTERNAL1V1);
  #else
    analogReference(INTERNAL);
  #endif
  // set minimum battery level threshold
  send(msgBattLevel.set(MIN_VALUE, 0));
}

void presentation() {
  // Send the sketch version information to the gateway and Controller
  sendSketchInfo(SKETCH_NAME, SKETCH_VERSION);
  // Fetch the number of attached temperature sensors  
  numSensors = sensors.getDeviceCount();
  //Blink LED as number of sensors attached
  blink_led(numSensors, ledpin);
  
  //check if attached sensors number is grater then 0 if no then put led on solid
  #if numSensors > 0
    digitalWrite(ledpin, HIGH);
  #else 
    digitalWrite(ledpin, LOW);
  #endif
  // Present all sensors to controller
  for (int i=0; i<numSensors && i<MAX_ATTACHED_DS18B20; i++) {
    present(i, S_TEMP);
  }
}

void loop(){
  // get the battery Voltage
  //ref http://www.ohmslawcalculator.com/voltage-divider-calculator
  // Sense point is bypassed with 0.1 uF cap to reduce noise at that point
  
  // 1M, 100K divider across battery and using internal ADC ref of 1.1V
  // ((1e6+100e3)/100e3)*1.1 = Vmax = 12.1 Volts
  // 12.1/1023 = Volts per bit = 0.011828 
  
  //R1 820k, R2 220k
  //((820e3+220e3)/220e3)*1.1 = Vmax = 5.2 Volts
  //5.2/1023 = Volts per bit = 0.005083089
  
  int battSensorValue = analogRead(BATTERY_SENSE_PIN);
  //float batteryV  = battSensorValue * 0.005083089; //R1 820k, R2 220k divider across battery and using internal ADC ref of 1.1v
  float batteryV  = battSensorValue * 0.011828;    //R1 1M, R2 100K divider across battery and using internal ADC ref of 1.1v
  
  //int batteryPcnt = ((batteryV - 2.9) / (4.2 - 2.9) * 100); // for 18650 Battery Powred 
  //int batteryPcnt = ((batteryV - 2.1) / (3.0 - 2.1) * 100); // for 2 x AAA Battery Powered
  int batteryPcnt = ((batteryV - 2.5) / (4.5 - 2.5) * 100); // for 3 x AAA Battery Powered
    
  #ifdef MY_DEBUG
    Serial.print("Pin Reading: ");
    Serial.println(battSensorValue);
    Serial.print("Battery Voltage: ");
    Serial.print(batteryV);
    Serial.println(" v");
    //Print Battery Percentage
    Serial.print("Battery percent: ");
    Serial.print(batteryPcnt);
    Serial.println(" %");
  #endif
  
  #if COMPARE_BVOLT == 1
    if (oldBatteryV != batteryV) {
      send(msgBatt.set(batteryV, 2));
      sendBatteryLevel(batteryPcnt);
      oldBatteryV = batteryV;
    }
  #elif COMPARE_BVOLT == 0
    send(msgBatt.set(batteryV, 2));
    sendBatteryLevel(batteryPcnt);
  #else
    if (oldBatteryV != batteryV || batteryNotSentCount>=COMPARE_BVOLT) {
      send(msgBatt.set(batteryV, 2));
      sendBatteryLevel(batteryPcnt);
      oldBatteryV = batteryV;
      batteryNotSentCount=0;
    }else{
      batteryNotSentCount++;
    }
  #endif

  // Fetch temperatures from Dallas sensors
  sensors.requestTemperatures();
  // query conversion time and sleep until conversion completed
  int16_t conversionTime = sensors.millisToWaitForConversion(sensors.getResolution());
  //sleep() call can be replaced by wait() call if node need to process incoming messages (or if node is repeater)
  sleep(conversionTime);
  #ifdef MY_DEBUG
    Serial.print("Conversion Time: ");
    Serial.println(conversionTime);
  #endif
  // Read temperatures and send them to controller 
  for (int i=0; i<numSensors && i<MAX_ATTACHED_DS18B20; i++) {
    // Fetch and round temperature to one decimal
    float temperature = static_cast<float>(static_cast<int>((getControllerConfig().isMetric?sensors.getTempCByIndex(i):sensors.getTempFByIndex(i)) * 10.)) / 10.;

    // Only send data if temperature has changed and no error
    #if COMPARE_TEMP == 1
      if (lastTemperature[i] != temperature && temperature != -127.00 && temperature != 85.00) {
        // Send in the new temperature
        send(msg.setSensor(i).set(temperature,1));
        // Save new temperatures for next compare
        lastTemperature[i]=temperature;       
      }
    #elif COMPARE_TEMP == 0
      if (temperature != -127.00 && temperature != 85.00) {
        // Send in the new temperature
        send(msg.setSensor(i).set(temperature,1));
      }
    #else
      if ((lastTemperature[i] != temperature || temperatureNotSentCount[i]>=COMPARE_TEMP) && temperature != -127.00 && temperature != 85.00) {
        // Send in the new temperature
        send(msg.setSensor(i).set(temperature,1));
        // Save new temperatures for next compare
        lastTemperature[i]=temperature; 
        //Reset values not sent count
        temperatureNotSentCount[i]=0;      
      }else{
        lastTemperature[i]=temperature; 
        temperatureNotSentCount[i]++;
      }
    #endif
  }
  
  //Condition to check battery levell is lower then minimum then blink led 3 times
  //if (batteryV < 2.9) { //for 18650 Battery Powered Sensor 
  //if (batteryV < 2.0) { //for 2 x AAA Battery Powered Sensor 
  
  //if (batteryV < 2.0) { //for 3 x AAA Battery Powered Sensor 
    //blink_led(3, ledpin);
    //Serial.print("Low Voltage");
  //}
  //go to sleep for while
  //smartSleep(SLEEP_TIME);
  sleep(SLEEP_TIME);
}

//Blink LED function, pass ping number and number of blinks usage: blink_led(variable or number of time blink, ledpin);
void blink_led(int count, int pin){
  for(int i=0;i<count;i++){
    digitalWrite(pin, HIGH);
    delay(700);
    digitalWrite(pin, LOW);
    delay(700);
  }
}

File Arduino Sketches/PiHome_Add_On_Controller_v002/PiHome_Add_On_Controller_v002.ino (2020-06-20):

//  _____    _   _    _                             
// |  __ \  (_) | |  | |                           
// | |__) |  _  | |__| |   ___    _ __ ___     ___ 
// |  ___/  | | |  __  |  / _ \  | |_  \_ \   / _ \ 
// | |      | | | |  | | | (_) | | | | | | | |  __/
// |_|      |_| |_|  |_|  \___/  |_| |_| |_|  \___|
//
//    S M A R T   H E A T I N G   C O N T R O L 
// *****************************************************************
// *              Add-On Controller Relay Sketch                   *
// *            Version 0.02 Build Date 19/06/2020                 *
// *            Last Modification Date 19/06/2020                  *
// *                                          Have Fun - PiHome.eu *
// *****************************************************************

// Adapted for AC-DC double solid state relay module, see
// https://www.openhardware.io/view/77/AC-DC-double-solid-state-relay-module#tabs-instructions


// Enable debug prints to serial monitor
#define MY_DEBUG

//Set MY_SPLASH_SCREEN_DISABLED to disable MySensors splash screen. (This saves 120 bytes of flash)
#define MY_SPLASH_SCREEN_DISABLED

// Enable and select radio type attached
#define MY_RADIO_RF24
//#define MY_RADIO_NRF5_ESB
//#define MY_RADIO_RFM69
//#define MY_RADIO_RFM95

//Define this to use the IRQ pin of the RF24 module (optional). 
//#define MY_RF24_IRQ_PIN 8

// * - RF24_PA_MIN = -18dBm
// * - RF24_PA_LOW = -12dBm
// * - RF24_PA_HIGH = -6dBm
// * - RF24_PA_MAX = 0dBm
// Set LOW transmit power level as default, if you have an amplified NRF-module and
// power your radio separately with a good regulator you can turn up PA level.
// RF24_PA_MIN RF24_PA_LOW RF24_PA_HIGH RF24_PA_MAX RF24_PA_ERROR
#define MY_RF24_PA_LEVEL RF24_PA_MIN
//#define MY_DEBUG_VERBOSE_RF24

/**
 * @brief RF channel for the sensor net, 0-125.
 * Frequencies: 2400 Mhz - 2525 Mhz
 * @see https://www.nordicsemi.com/eng/nordic/download_resource/8765/2/42877161/2726
 * - 0 => 2400 Mhz (RF24 channel 1)
 * - 1 => 2401 Mhz (RF24 channel 2)
 * - 76 => 2476 Mhz (RF24 channel 77)
 * - 83 => 2483 Mhz (RF24 channel 84)
 * - 124 => 2524 Mhz (RF24 channel 125)
 * - 125 => 2525 Mhz (RF24 channel 126)
 * In some countries there might be limitations, in Germany for example only the range
 * 2400,0 - 2483,5 Mhz is allowed.
 * @see http://www.bundesnetzagentur.de/SharedDocs/Downloads/DE/Sachgebiete/Telekommunikation/Unternehmen_Institutionen/Frequenzen/Allgemeinzuteilungen/2013_10_WLAN_2,4GHz_pdf.pdf
 */
 
//Default RF channel Default is 76
#define MY_RF24_CHANNEL  91

//PiHome Add-On Controller Node ID
#define MY_NODE_ID 80

//RF24_250KBPS for 250kbs, RF24_1MBPS for 1Mbps, or RF24_2MBPS for 2Mbps
#define MY_RF24_DATARATE RF24_250KBPS

//Enable Signing 
//#define MY_SIGNING_SIMPLE_PASSWD "pihome2019"

//Enable Encryption This uses less memory, and hides the actual data.
//#define MY_ENCRYPTION_SIMPLE_PASSWD "pihome2019"

// Enable repeater functionality for this node
//#define MY_REPEATER_FEATURE

// Comment line below if you don't want to use the temperature sensor
#define USE_TEMP_SENSOR

//Define Sketch Name 
#ifdef USE_TEMP_SENSOR
  #define SKETCH_NAME "Add-On Controller/Sensor"
#else
  #define SKETCH_NAME "Add-On Controller"
#endif
//Define Sketch Version 
#define SKETCH_VERSION "0.02"

// Set baud rate to same as optibot
//#define MY_BAUD_RATE 115200

//set how long to wait for transport ready in milliseconds
//#define MY_TRANSPORT_WAIT_READY_MS 3000

#include <MySensors.h>
#include <Bounce2.h>

// MySensor Debug
#define MY_DEBUG

// Comment line below if you don't want to use the temperature sensor
#define USE_TEMP_SENSOR

#include <MySensors.h>
#include <SPI.h>
#include <Bounce2.h>

#define BUTTON_PIN   4  // Arduino Digital I/O pin number for button 
#define BUTTON_PIN_2 7
#define NUMBER_OF_RELAYS 2 // Total number of attached relays
int relayPins[]={5, 3}; // Arduino Digital I/O pin numbers for relays

#define CHILD_ID 1 // Id of the sensor child for 1st relay
#define CHILD_ID_2 2 // Id of the sensor child for 2nd relay

// Relay status
#define RELAY_ON 1
#define RELAY_OFF 0

// Source of state change (used when printing debug information)
#define CHANGE_STATE_SOURCE_RADIO 0
#define CHANGE_STATE_SOURCE_SWITCH 1


// Temperature sensor definitions
#ifdef USE_TEMP_SENSOR
  #include <OneWire.h>
  #include <DallasTemperature.h>
  #define COMPARE_TEMP 1 // Send temperature only if changed? 1 = Yes 0 = No, > 1 - force send if it value not sent that number of times and value is valid (keep lower than notice interval)
  #define ONE_WIRE_BUS 8
  #define CHILD_DSB_ID 0 // Id of the sensor child for temperature sensor
  #define TEMPERATURE_ROUNDING 5.f   // Change value to change rounding of temperature value: 10.f for 0.1°C change, 5.f for 0.2°C change, 2.f for 0.5°C change
  MyMessage msgTemp(CHILD_DSB_ID, V_TEMP);
  OneWire oneWire(ONE_WIRE_BUS);
  DallasTemperature sensors(&oneWire); // Pass the oneWire reference to Dallas Temperature.
  float lastTemperature;
  bool receivedConfig = false;
  bool metric = true;
  int temperatureNotSentCount;
#endif

Bounce debouncer = Bounce();
int oldValue;
bool state;
Bounce debouncer2 = Bounce();
int oldValue2;
bool state2;

MyMessage msg(CHILD_ID, V_LIGHT);
MyMessage msg2(CHILD_ID_2, V_LIGHT);

void presentation() {
  // Send the sketch version information to the gateway and Controller
  sendSketchInfo(SKETCH_NAME, SKETCH_VERSION);
  // Register all sensors to gw (they will be created as child devices)
  #ifdef USE_TEMP_SENSOR
    present(CHILD_DSB_ID, S_TEMP);
  #endif
  for (int i = 1; i <= NUMBER_OF_RELAYS; i++) {
    present(i, S_LIGHT);
  }
}

void setup()
{
#ifdef USE_TEMP_SENSOR
  sensors.begin();
  sensors.setWaitForConversion(false);
#endif

  // Setup the button
  pinMode(BUTTON_PIN, INPUT);
  // Activate internal pull-up
  digitalWrite(BUTTON_PIN, HIGH);

  // Setup the button
  pinMode(BUTTON_PIN_2, INPUT);
  // Activate internal pull-up
  digitalWrite(BUTTON_PIN_2, HIGH);

  // After setting up the button, setup debouncer
  debouncer.attach(BUTTON_PIN);
  debouncer.interval(5);

  debouncer2.attach(BUTTON_PIN_2);
  debouncer2.interval(5);

  // Set the initial values of oldValue/oldValue2 variables from status of physical switches
  //  if this is not done the loop() will detect status change and switch the relays on or off
  debouncer.update();
  debouncer2.update();
  oldValue = debouncer.read();
  oldValue2 = debouncer2.read();

  // Setup relay pins
  for (int thisPin = 0; thisPin < NUMBER_OF_RELAYS; thisPin++) {
    // Make sure relays are off when starting up
    setRelayState(relayPins[thisPin], RELAY_OFF);
    // Then set relay pins in output mode
    pinMode(relayPins[thisPin], OUTPUT);
    // Set relay to last known state (using eeprom storage)
    digitalWrite(relayPins[thisPin], loadState(thisPin+1)?RELAY_ON:RELAY_OFF);
    delay(3);
  }
}
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

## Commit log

2019-06-21 PiHome Smart Heating
    Schedule UI improved for last zone list slider
2019-06-23 Temperature deadband (#1)
    * Temperature deadband added
    Added temperature deadband, zone starts when temperature is below setpoint-deadband and stops when temperature is greather or equal to setpoint.
2019-06-23 Revert "Merge branch 'master' into temperature-deadband"
    This reverts commit a53494974c90fab766075ed5765a047d0d216f44, reversing
    changes made to a802bcfe4285a36c1aa652996f53101a3fd1fa12.
2019-06-27 Update model.php
    dispaly gpio pin number for boiler
2019-06-29 PiHome Smart Heating
    Basic Holiday option added Thanks you Terry Adams for code contribution.
2019-06-29 PiHome Smart Home
    #27
    Notice script to check when node (Boiler, Zone Controller and temperature sensor) isnt responding for set time.
2019-06-29 PiHome Smart Heating
    #31 If Gateway lost connection for 10 minute then search for gateway begin.
2019-07-09 Update PiHome_Boiler_Controller.ino
    #31
    This is the last update for this issue.
    [PiHome_Boiler_Controller.ino]
2019-07-10 Zone fail
    Zone fail on temperature reading / relay node timeout
    [DallasTemperatureSensor_Battery_v3.ino]
2019-07-13 Update homelist.php
    #25 Improvement: Sensors/Zone Communication
    ## Further updates
    If controller or sensors not reporting for set time, then zone become faulty all heating system for faulty zone are suspended. system will resume normal activity once issue selfheal or fixed by user.
2019-07-17 Update homelist.php
    #28 small improvement to display temperature sensor last seen and zone controller last seen
2019-07-19 PiHome Smart Heating
    #27 Settings icon for E-Mail settings for users., on same note users’ needs up update database as per previous updates.
2019-07-19 PiHome Smart Heating
    Few bugs and fixes pointed out by another User.
2019-07-24 PiHome Smart Heating
    Few bugs/Changes
    Boost list: Changed from hours to minutes for listing
    Holiday: code in header which no longer required.
    Model: email password field changed from text to password.
    Schedule add: amended with zone not marked for deletion.
2019-07-27 Update homelist.php
    bug: when controller was offline it showed sensors ID now fixed this
2019-07-31 PiHome Smart Heating
    Added option to modify Boiler Settings and how Boiler/Heat Source is controlled by PiHome i.e over GPIO or over Wireless Controller.
2019-08-04 PiHome Heating
    Further Update to Boiler Settings, added option to check if message_out table have boiler controller id.
2019-08-04 Coop start schedule
    Added option for zone schedule with coop start (option on schedule add/edit screen).
    Coop start schedule won't start zone if boiler is not already running. If boiler is running and temperature is below setpoint minus deadband schedule will start the zone, after starting it operates as any other schedule and will stop the zone when setpoint temperature is reached.
2019-08-06 PiHome Smart Heating
    Final Version 1.63 with Coop Start.
    Thanks to @aszumski
2019-08-29 Update pihome_mysql_database.sql
    Enable selection of heating zone graphs
2019-08-29 Update MySQL_View.sql
    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
2019-08-29 Update request.js
    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
2019-08-29 Update en.php
    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
2019-08-29 Update fr.php
    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
2019-08-29 Update pt.php
    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
2019-08-29 Update db.php
    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
2019-08-29 Update model.php
    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
2019-08-29 Update chartfooter.php
    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
2019-08-29 Update settingslist.php
    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
2019-09-10 Update model.php
    Fix for Add Boost button not working in MS EDGE
2019-09-12 i2C interface Relay support
    i2C interface Relay support
    the address needs to be in decimal (rather then hex) and all three values are cast as integers. easyi2c.py is needed as the class to manage the relay.
    #65 i2C interface Relay support
2019-10-12 i2c Settings
    i2c relay setting must be un-commented if user want to sue i2c relay or until issue #70 Nodes options completed.
2019-11-02 PiHome Smart Heating - Node Sketches Update
    Zone, Boiler and Temperature sensors sketches compatible with last updated version of PiHome
2019-11-15 i2c commented out
    Until Nodes options #70 isn’t implemented i have to comment out i2c from boiler as this is generating lots of un-necessary errors logs as most of users don’t have i2c interface enabled.
    If you have i2c relay then remove comments from three locations in boiler.php file
2019-12-16 Update chartfooter.php
    Bug - sensors_child_id used instead of sensor_child_id when accessing zone_view
2020-01-17 Update schedule_edit.php
    Query database for slider temperature. (do not revert to default 15)
2020-01-24 corrected i2c code
    updated i2c but left commented out.
2020-01-27 GPIO, I2C, Wireless Nodes
    To stream line raspberry pi GPIO and I2C relay boards and MySensors Controller Nodes. This update add option to have multiple raspberry pi to function as nodes with each raspberry with all gpio avail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
    #70 Nodes options
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2020-01-30 #70 Nodes options
    User can Add and Delete GPIO and I2C nodes from Settings ->Nodes
    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
2020-02-11 database badckup to email
    #48 some further updated after pull request #125 by @dvdcut
    under backup icon user can change email address to receive backup file in email attachment.
2020-02-16 nRF24L01 to RFM69CW/RFM69HCW/RFM69W/ Adapter
    <h1>PiHome - Smart Heating, Ventilation and Air Conditioning (HVAC)</h1>
    <p>nRF24L01 to RFM69CW/RFM69HCW/RFM69W/ Adapter compatible with MySensors Library</p>
    <h4>Size/Compatibility</h4>
    <p> RFM69CW/RFM69HCW/RFM69W</p>
    <p>For more information check PiHome website <a href=@http://www.pihome.eu@>http://www.pihome.eu</a></p>
    [PiHome RFM69-95 to nRF.brd, PiHome RFM69-95 to nRF.sch]
2020-02-19 Added exception logging and Error handling
    [wifigw.py]
2020-02-20 Fixed issue with adding nodes name to DB. Issue #136
    [wifigw.py]
2020-02-24 Setup TimeZone, Language, Temperature Unit while executing setup.php
2020-03-26 Update gateway.py
    Small issue with gateway script, need to from datetime import datetime
    [gateway.py]
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2020-03-30 Update weather_update.php
    datetime missing from list and weather temperature msising from messages_in table
    #166
2020-04-06 Update gpio_ds18b20.py
    1-Wire DS18B20 Temperature Sensor with Raspberry Pi, python script tested with temperature sensor.
2020-04-18 Boost Console/Button
    Boost Console/Button under setting and some code cleanup .
2020-05-08 fix for python error for physical gpio
    few items were missing,
    physical pin list
    All Languages updates
    [gpio3_relay.py]
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2020-06-06 Arduino Sketch for temperature sensor
    Arduino Sketch for temperature sensor
2020-06-09 basic record added
    raspberry pi GPIO, boiler, and away record added
2020-06-18 Delete Nodes/Sensors from Settings
    Delete Nodes/Sensors from Settings #258
2020-06-19 back end changes for boiler circulation pump ovverrun time
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2020-06-22 Code indentation
    Not directly related to any issue but i wanted to have clean code so we all can read all logics and make sense as well.
    Performance Issue #283
    Circulation Pump Overrun #263
2020-06-22 Circulation Pump Overrun #263 settings from gui
    Circulation Pump Overrun #263 option to change settings from gui under settings->boiler
2020-06-23 Update model.php
    adding option for disable overrun and keep valve open until next boiler start
2020-06-25 chart load time
    reduce loading time for charts, battery voltage graph is removed.
2020-06-25 buttons for chart
    adding bigger buttons same as settings.
2020-06-29 Update gpio_ds18b20.py
    gpio connected temperature senosrs,
    Charts #291
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2020-08-05 schedule name
    Schedule name on home screen moved next to zone temperature
2020-08-18 zone editing and battery level duplicate div removed
    Zone Editing fixed updating zone_sensors table
    batteryusage: duplicate div for battery level removed.
2020-11-05 Bug Fix for #425
    Fix for : Clicking on temperature circle deletes the schedule #425
2020-12-12 Update notice.py script for python3 and fixed a couple of issues: - wrong type cast when NULL is returned from mysql esults[bat_node_to_index['bat_level']] - missing BATTERY_NODE_INTERVAL variable - 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
    [notice.py]
2021-02-28 HA integration
    API modification to allow Home Assistant to pull also the sensor's battery info and the boiler status.
2021-02-28 Create getZoneStatus.php
    API that allows to check the status of a zone, and the zone info (i.e. temp, battery level etc.). This approach will work both to PiHome and for MaxAir.
2021-04-26 DS18b20 filtering
    Added filtering for DS18b20 data and the option to apply exponential moving average smoothing
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2021-05-02 Update gateway.py
    small bug fix in gateway.py
    #444
    [gateway.py]
2021-07-02 Update gateway.py
    i had to remove this as this is causing problem while pinging on WIFI gateway
    [gateway.py]

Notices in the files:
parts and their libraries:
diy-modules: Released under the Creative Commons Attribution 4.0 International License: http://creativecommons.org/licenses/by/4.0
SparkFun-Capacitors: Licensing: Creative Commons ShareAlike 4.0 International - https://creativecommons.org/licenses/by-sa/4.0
